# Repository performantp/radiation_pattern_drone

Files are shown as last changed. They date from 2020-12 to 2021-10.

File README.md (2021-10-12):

# Radiation Pattern Drone Project 
README

Die mit MMANA oder 4NEC berechneten Antennen sollen mit einer Drohne auf Abstrahlungscharakteristik und Abstrahlungswinkel ausgemessen und überprüft werden. Die erstellten versionierten Dateien sollen für weitere Projektmitglieder lesbar abgelegt werden.

Release 1.3a (diese Aufgabe wurde im September 2021 unterbrochen, weitere Hinweise und Details sind am Schluss aufgeführt).

Release 1.4a es wurden anschliessend zwei Lösungsvarianten evaluiert. 

Variante 1: Welche anfangs Oktober 2021 nun bereits mit einem ersten Test läuft, ist folgende: Mit einem Raspi auf dem rtl_power läuft und RTL-SDR mit einen Transverter
(47g) wird ein Frequenzbereich von 7-14 MHz überwacht und die gemessenen Werte werden mit einem Python Programm auf einem Raspi Zero W (40g) abgegriffen und dargestellt (Kabel und Antennen ca. 50g). Die ersten Messergebnisse sind so, dass man die gemessenen Werte noch gegenüber dem S-Level kalibrieren muss.

Variante 2: Im Hintergrund ist noch folgende zweite Lösung angedacht und die entsprechende Hardware wurde im September 2021 bereits beschafft.
Mit einem Raspi Zero W (40g) sollen die Messwerte von einem RTL-SDR mit integriertem Transverter aufgesammelt werden und die Daten anschliessend mit rtl_power und/oder Python ausgewertet werden.

Zu der Programmiersprache Python wurde von HB9FRV Ende September 2021 ein USKA HamAcademy durchgeführt. Es gibt voraussichtlich noch weitere Python Kurse. Auch wie man mit Python SDR Implementationen erstellt, wird von Mathias HB9FRV im Rahmen der USKA HamAcademy vermittelt. Daniel HB9GVD wird am 23.10.2021 am Kurs teilnehmen. Die Kurse sind für USKA Mitglieder mit 60.- CHF Kursgeld zugänglich. Auch dieser Kurs wird ev. wiederholt.

Das Team sucht weitere Interessierte, wenn möglich mit Python Kompetenz, welche die Python Aktivitäten unterstützen können. Interessenten melden sich bitte bei Martin HB9GYF oder Daniel HB9GVD.

Release 1.4b (nächste Aufgabe)
Mit einer grösseren Drohne und einer Last von ca. 150g und einem Gesamtgewicht von mehr als 1kg eine zu messenden Antenne (voraussichtlich eine Small Transmitting Loop (STL)) in einem Stufenflug zu erfliegen, damit daraus die Abstrahlcharakteristik der Antenne ermittelt werden kann. Analysieren wieviele Messungen im Flug pro Sekunde durchgeführt werden müssen, damit die Abstrahlcharakteristik ermittelt werden kann. Analysieren, ob sich im PoC dazu der WSPR-Ansatz eignet. Analysieren, wie z.B. grosse Beam-Antennen auf so kleine Aussendungen in 200m rund um die Antenne reagieren/gemessen werden können. Analysieren, ob sich die kleine Stabantenne im PoC eignet oder ob eine Drahtantenne realisiert werden soll. Analysieren, wie sich eine Aussendung z.B. mit 1W im Flug eignet. Die generelle Datensammlung soll im PoC überprüft werden. Die Datenauswertung im PoC soll nach einem Flug innert 12h vorliegen.

Eine Drohne herzustellen inkl. Akku, GPS und allem SDR-Equipmnet unter 250g wäre interessant, um unter den (künftigen) restriktiven gesetzlichen Anforderungen "in die Luft" zu kommen.



Die Drohne Plan B1 kann mehrere Way Points xyz fliegen und so müssten wir in der Lage sein, unser Stufenprofil auf verschiedenen Höhen auszufliegen. Die Drohne Plan B2 wurde bestellt und ist im September 2021 ebenfalls in der Schweiz bei Daniel HB9GVD. 



Release 1.4c (übernächste Aufgabe)
beinhaltet die Realisierung des sogenannten Datensammelpunkts gemäss Datenmodell sowie der Speicherung der Daten für spätere Auswertungen. Die Empfangssignalstärke sowie die GPS-Daten (es könnten die GPS-Daten der Drohne sein) sollen aufgenommen, zeitlich verknüpft und raw gespeichert werden. 

Release 1.5 (weitere Aufgaben) 
beinhaltet die Realisierung von Auswertungen nach Abzug über WLAN oder Bluetooth von der Drohne auf einen PC. Diese können als erstes Proof of Concept für die Auswertung des Abstrahlwinkels und den weiteren Sendekeulen manuell oder automatisch mit einer Python Programmierung erfolgen. 

---------------------------------------------------------------------------------------------------------------------------------------------------------------------------------
Release 1.3a (diese Aufgabe wurde im September 2021 unterbochen)

Aufgabenstellung: Beinhaltet die Realisierung auf einem eigenen Board mit einem ESP32 Prozessor für die Scriptsprache Phyton mit WLAN und Bluetooth Schnittstelle, welches mit KICAD geplant wird (Design per 15.04.2021 abgeschlossen) und dessen PCB-Fertigung in China inklusive Bestückung erfolgt. Dabei können nur Bauteile vom Produzenten auf der Platine eingebaut werden. Die Integration des Silicon Labs SDR Chipset SI4734-D60-GU (SSOP Bauweise) und weitere 1-2 Bauteile werden dann abschliessend manuell in der Schweiz bestückt und danach getestet. Die Box ohne Antenne ist ca. 5x5x3 cm gross und wird mit ca. 30g Last berechnet. Professionelle Drohne aus US mit 780g Fluggewicht und Funktionen wie u.a. Motion Tracking, Way Point Skills ist nach längeren Shiping Aktionen in der CH eingetroffen und sie wurde getestet. Die vorhandenen Flug Management Skills sind hervorragend, aber u.a. aus Lizenzgründen vermutlich "zu gut". Aus der Sicht maximales Gesamtgewicht, welches unter 250g angestrebt wird (somit ist ein Flug bis 250m Höhe ohne Voranmeldung möglich, gesetzliche Randbedingung) wurde für das PoC eine noch leichtere Drohne bestellt. Die PoC Anforderungen an diese leichte Drohne sind mit Last gesamthaft nicht schwerer als 250g, Way Points zu fliegen, Position halten zu können und alles bis ca. 15 km Wind auf +/- 0.5m genau zu fliegen, und dabei die GPS-Daten zu speichern.  

Das SDR PCB ist am 08.05.2021 fertig "designed" und geht bald in die Fertigung nach China. Screenshot von Daniel HB9GVD erhalten. 



Warum wurde unterbrochen? Beim Testen des Boards sind im August/September 2021 Design-Fehler aufgetreten. Einige Verbindungen konnten zwar mit einer ad hoc Verbindung/Korrektur korrigiert werden. Trotz mehreren Anläufen das Board "zum Laufen" zu bringen, und weiteren Arbeiten wurde der "Durchbruch" leider nicht erreicht. Die Arbeiten zu Release 1.3a wurden deshalb vorläuftig eingestellt, alternative Lösungswege wurden analysiert und gefunden. Gerne lädt das Team Interessierte ein, das Board und die entsprechende Programmierung weiterzuführen. Daniel HB9GVD teilt sein Wissen gerne. Die Gewichtsvorteile der eigenen Hardware würden eher eine <250g Drohne erlauben.

--------------------------------------------------------------------------------------------------------------------------------------------------------------------------------
Abgeschlossene oder gestrichene Releases:
Release 1.1 (am 23.12.2020 abgeschlossen)
beinhaltete die Realisierung im November/Dezember 2020 auf einem Breadboard mit dem Silicon Labs Chipset 30, welcher "nur" MW und FM kann. Die Realiserung mit dem Display ST7735SB mit einer SD-Speicherkarte wurde am 01.12.2020 wegen Inkompatibilität zur Original Display Library eingestellt. Weiter verfolgt wurde die Realisierung mit dem Display ST7735S. Die Realisierung wurde in Woche 50/2020 erfolgreich abgeschlossen. Die erreichten Ergebnisse von diesem Release sind in der Dokumentation festgehalten. 

Release 1.2 (auf diesen Schritt wird am 23.12.2020 verzichtet, weil zwei andere OM's diesen Nachweis bereits vollbracht haben, Verweis auf zwei you tube Videos)
beinhaltet die Realisierung auf einem Breadboard mit dem Silicon Labs SDR Chipset SI4734-D60-GU (in der SSOP Bauweise mit oder ohne Breakout Board), welcher MW, FM und SW, inbesondere LSB, USB und CW, kann. Das Display und die Bedienung wird mit einer App realisiert. 

--------------------------------------------------------------------------------------------------------------------------------------------------------------------------------

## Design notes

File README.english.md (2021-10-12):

Antennas calculated either with programs like i.e. MMANA or 4NEC shall be checked and measured with a drone for its real transmission angle and further antenna characteristics. 
Versioned Python sources, compiler scripts for raspi zero W or other documentation presented in Mind Manager files, pdf-files and/or Word files shall be documented for additional project members. 

Variant 1: Equipment rtl_power with transverter in tests and already measured values from 7-14 MHz shall be calibrated against S-Level. First measured realtime date with Python performed, and further analysis of these data still in progress as quick win. 

Variant 2: Equipment raspi zero W to be connected with uSDX (hardware already available on site), and measured data to be selected and displayed with Python to the user under investigation (second opinion). 

First Python training course from Mathias HB9FRV as USKA HamAcademy performed, second Python training already planned. A welcome to an additional team member with Python knowledge is kindly requested. If you would like to join the team, please contact either Daniel HB9GVD or Martin HB9GYF.

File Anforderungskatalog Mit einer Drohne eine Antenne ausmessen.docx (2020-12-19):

# Anforderungskatalog & Proof of Concept "Mit einer Drohne eine Antenne ausmessen" Motto: content over form 19.12.2020

# Anforderungskatalog & Proof of Concept "Mit einer Drohne eine Antenne ausmessen" Motto: content over form 19.12.2020

# 1 Einleitung

Man kann eine Antenne mit MMANA oder 4NEC2, usw. berechnen. Wenn man sie einerseits baut und andererseits aufstellt, weiss man nicht wie die Abstrahlungscharakteristik und der Abstrahlungswinkel wirklich ist. Welchen Einfluss hat u.a. die Umgebung?

Zur Schreibweise und Definition sind es zum Teil Anforderungen (ANF) zum Thema. Welche sich in Business Use Cases (BUC's) und [System] Use Cases (UC's) unterteilen.

## 1.1 Anforderungen (ANF) sind unterteilt in

### 1.1.1 Business Use Cases (BUC's)

Anforderungen vom Benutzer, was er braucht um den Business Use Case "Antennen mit einer Drohne ausmessen" benötigt/braucht

### 1.1.2 [System] Use Cases (UC's)

System Use Cases werden im Weiteren nur als Use Cases (UVC's) beschrieben und das sind Anforderungen an die Technik und/oder Drohne, welche erfüllt sein sollten, damit man schlussendlich einen oder mehrere BUC's durchführen kann.

Wenn Sie das Dokument durchlesen, werden sie leicht merken um was es dabei geht.

## 1.2 Testfälle für BUC's oder UC's werden als Test Cases (TC's) bezeichnet

# 2 Vor dem Start

Die Drohne steht in der Nähe der aufgebauten Antenne und die Antenne ist im Betrieb. Der Empfänger in der Drohne muss vo dem Start, resp. bereits beim Einschalten mindestens mit einem 60 dB Attenuator geschützt werden, ansonsten der Empfänger bei Anschluss einer Antenne gleich zerstört wird. Warum? Auch mit einem solchen Schutz mit 60 dB, so die Erfahrungen/Lernlektion anlässlich eines Fieldday mit dem HB9LU Morseteam, liegt bei ca. 100 W Sendeleistung der Empfangspegel von S9+40 an, wenn die sendende Antenne ca. 50m entfernt ist.

# 3 UC: Attenuator Umschaltung in der Luft

Der Attenuator muss in der Luft umgeschaltet werden können, d.h. je weiter weg die Drohne fliegt soll ein kleinerer Attenuator eingesetzt werden. Dies soll automatisch erfolgen. Wenn die Drohne weit genug weg ist, soll der Attenuator ausgeschaltet werden. Wenn die Drohne sich wieder der Antenne nähert, soll der Attenuator wieder eingeschaltet werden,

Wenn sich die Drohne einer anderen sendenden Antenne nähert, soll das gleiche Procedur erfolgen, um den Empfänger zu schützen.

# 4 BUC: 'normales' Diagram einer Monoband Antenne erfliegen

Monoband Dipole oder Monoband Verticals haben eher bekannte Abstrahlungscharakteren.

# 5 BUC: Diagramm einer Yagi Antenne erfliegen und F/B Verhältnis ausweisen

# 6 BUC: Sendekeulen inklusive Abstrahlwinkel erfliegen, z.B. mit einem Wellenflug oder Rundflug (Kreis) auf verschiedenen Höhen in verschiedenen Radien

## 6.1 24.11.2020

### 6.1.1 für das Proof of Concept könnte man ganz einfach in der erwarteten Hauptstrahlrichtung in Distanz 20m und 5m Höhe auf 150m hoch, dann 20m weiter weg in 40m/150 auf 5m runter, dann weiter weg auf 60m in 5m Höhe usw. fliegen

# 7 Eine Antenne ist an einen WSPR Sender (WSPRlite Flexi) angeschlossen und sendet auf einer eingestellten Frequenz

## 7.1 1 Watt

### 7.1.1 war es bei Martin früher einmal mit einer WSPR Aussendung auf dem ICOM 7300. Die TRX-Aussendung musste manuell gestartet werden. Habe die Ansteuerung nicht/nie realisiert. Aber für einzelne Aussendungen und kurze Tests über z.B. 10 Minuten (5 Aussendungen) war das ok

## 7.2 kleine Leistung ... sind m.E. die milliWatt Dinger ab der Stange

### 7.2.1 WSPRlite Flexi mit 200 mW

Siehe auch: WSPRlite Flexi mit 200 mW an einer kurzen Antenne mit der obigen Konfiguration, prüfen, oder

#### 7.2.1.1 bei Wimo für 80 Euro aber Ende Oktober 2020 ausverkauft

#### 7.2.1.2 der ältere Typ ist der WSPRlite Classic

##### 7.2.1.2.1 der ältere Typ WSPRlite Classic hat ein Filter für 20m und 30m eingebaut

##### 7.2.1.2.2 Der neuere Typ benötigt für jedes Band ein eigenes Filter um sich zu schützen

###### für die ersten Tests habe ich bis und mit 16.11.2020 keine weiteren Filter gebaut oder eingesetzt

#### 7.2.1.3 Lutz Electronic hat beide auch im Angebot, zu kaufen gemäss Web-Seite

##### 7.2.1.3.1 am 02.11.2020 WSPRlite Flexi mit Kleinmaterial bestellt

##### 7.2.1.3.2 Lieferung von Lutz Electronic am 04.11.20220 eingetroffen

#### 7.2.1.4 200 mW ist die maximale Leistung. Man kann sie laut Beschreibung auch auf 5 mW reduzieren

#### 7.2.1.5 WSPR Message Type 1

##### 7.2.1.5.1 wir werden den WSPR Message Type 1 verwenden und "nur" HB9GYF aussenden, d.h. ohne einen Prefix oder Suffix zu verwenden

Siehe auch: Callsign HB9GYF eingestellt

##### 7.2.1.5.2 wir werden "nur" den vierstelligen Locator JN47 aussenden

Siehe auch: Locator JN47

#### 7.2.1.6 WSPR Message Type 2/3

##### 7.2.1.6.1 WSPR Messages Type 2/3 benötigen zwei Aussendungen und sie werden gegenüber WSPR Message Type 1 nur zu ca. 25% von 'hörenden' Stationen erkannt und in die WSPR-Datenbank geschrieben

#### 7.2.1.7 Beschreibungen, FAQ, Config, usw sind auf der Web-Seite www.DXplorer.net nachzulesen, resp. das EInstellpogramm WSPRliteConfig runterzuladen

Siehe auch: Einstellungen des WSPRlite Flexi mit dem Programm WSPRliteConfig

#### 7.2.1.8 05.11.2020

##### 7.2.1.8.1 Einstellungen des WSPRlite Flexi mit dem Programm WSPRliteConfig

###### man kann 5, 10, 20, 50, 100 oder 200 mW einstellen

###### Callsign HB9GYF eingestellt

###### Locator JN47

###### 20m Band

###### Es wird eine Frequenz ausgewählt

###### Aussendung 50%

###### Aussendungsdauer 3 days

###### so ist jede Aussendung natürlich gesetzeskonform

##### 7.2.1.8.2 vor dem Start

###### nicht vergessen die 20m Antenne anzuschliessen

###### habe meine ca. 80 cm lange EH-Dipol Antenne, realisiert mit zwei Haarspraydosen mit einem SWR 3.0, vertikal an einer Stipprute aufgesteckt angeschlossen

###### Filter-Thematik: Habe es ohne Filter probiert

Siehe auch: Filter Thematik

###### haben andere OM's auch schon gemacht, aber ...

###### zusammen mit Dani und seinem Analyser noch die Oberwellen ausmessen

##### 7.2.1.8.3 Start

###### man muss manuell starten, in dem man auf die Taste am WSPRlite Flexi drückt und zwar an geraden Minuten und die Sekunde 02

###### dazu auf dem PC mit dem Browser auf eine Web-Seite "Atomuhr von der Schweiz" öffnen

###### und zur richtigen Zeit noch die Taste drücken

###### wenn man zur falschen Zeit drückt, wird sofort ausgesendet

Siehe auch: man kann in diesem Fall zur richtigen Zeit, d.h. zur Sekunde 02 in einer geraden Minute, erneut die Taste drücken

###### man kann in diesem Fall zur richtigen Zeit, d.h. zur Sekunde 02 in einer geraden Minute, erneut die Taste drücken

##### 7.2.1.8.4 Aussendungskontrolle

###### mit dem ICOM 705 einem Dummyload mit einem parallelen kurzen Draht auf dem Band messen

###### in 2m Abstand kommt das ausgesendete 5 mW Signal mit S9+15 an

##### 7.2.1.8.5 Auswertung

###### im WSPRliteConfig unten einen Link anklicken führt den Benutzer direkt auf die WSPR Datenbank

###### am 05.11.2020 mit 5 mW Aussendung über die Inhouse Antenne nichts über eine Aussendung von HB9GYF gefunden

#### 7.2.1.9 Filter Thematik

##### 7.2.1.9.1 WSPRlite Flexi hat keine Filter

###### WSPRlite Classic hat zwei eingebaute Filter für das 20m und 30m Band

##### 7.2.1.9.2 bei Lutz Elecronic kann man Filter pro Band kaufen. Man muss diese dann aber selber zu sammen bauen, wickeln und löten

###### die Platine für drei Filter hat aber noch zwei Schalter drauf und man muss die Filter umschalten

##### 7.2.1.9.3 man muss aufpassen, dass man Filter kauft, welche nicht nur zum Empfangen, sondern auch zum Senden verwendet werden können

###### Es kommt auch noch drauf an, für welche Power sie sind

###### Filter für 1 KW oder 100 W sind natürlich zu stark und kosten auch sehr viel (schwer mit PL-Stecker sind sie auch noch)

###### Filter für 10 W kann man für rund 25.- USD auch mit SMA Stecker pro Band kaufen

##### 7.2.1.9.4 ein Überlastschutz ist das natürlich nicht

###### hiezu könnte man die Schaltung mit der Glühlampe, welche ich zusammen mit Mathias baute, verwenden

###### einen Überlastschutz würden wir benötigen, wenn starke Stationen in der Nähe des WSPR's aussenden, weil diese den WSPR Empfänger "verbrennen" könnten

##### 7.2.1.9.5 Als Umgehung der Filter-Thematik kann man eine schmalbandige Magnetic Loop als Sende-Antenne einsetzen

###### Martin hat noch die Magnetic Loop von HB9LU, welche auch 20m kann

###### bis jetzt nur 80m ausprobiert

###### ev. bei Gelegenheit mal ausprobieren

## 7.3 so war m.E. der letzte Versuch bei HB9LU (Martin war leider im 2019 nicht dabei)

### 7.3.1 Bericht auf der Web-Seite von HB9LU resp. HB9BXE nachlesen

#### 7.3.1.1 Bericht von Hans-Peter erhalten gelesen und auch an Dani verschickt

#### 7.3.1.2 interessant: die gemessenen Daten (die Empfangspegel) werden per Morsesignal auf UHF übermittelt (1 Mann Betrieb)

### 7.3.2 Nein, es war bei HB9LU nicht WSPR, sondern ein Feldstärke Messgerät, Marke Eigenbau

#### 7.3.2.1 im Film von Marcin HB9EGA war nicht erkennbar wie gross die Distanz beim Ausmessen der Antenne war

# 8 BUC: NVIS Anteil einer Antenne erfliegen

## 8.1 gemäss Dani am 31.10.2020 darf die Drohne, entfernt von einem Flughafen, auf max. 150m Grund fliegen

# 9 Zugeklappte Punkte

## 9.1 Antenne sendet FT8 Signale aus

### 9.1.1 Entscheid 30.10.2020: das Proof of Concept führen wir mit WSPR durch

# 10 BUC: Hohe Schule mit ad hoc Messungen an/bei in Betrieb stehenden Antennen idR mit hoher Leistung

## 10.1 UC: Antenne sendet während dem Drohnenflug mit SSB oder CW z.B. in einem Contest auf einer (1) festen Frequenz

## 10.2 UC: Antenne sendet während dem Drohnenflug mit SSB oder CW z.B. in einem Contest auf mehreren nicht angekündigten Frequenzen

## 10.3 wenn 200 mW des WSPRlite Flexi ein S9+30 ergeben, sind 1W gleich S9+36, 4W gleich S9+42, 16W gleich S9+48, 64W gleich S9+52, 256W gleich S9+58 und 1000W gleich S9+64 (wenn wir HB-Stationen ausmessen)

### 10.3.1 ein Bandpass Filter ist hier definitiv nicht die Lösung oder nur dann, wenn andere Stationen in der Nähe als die zu messende, ebenfalls mit starker Leistung senden, aber auf einem anderen Band

### 10.3.2 wenn wir den SDR Empfänger Chip mit dem Bausatz mit der Glühbirne schützen, dann verbrennen wir mit einem starken Signal zwar den SDR Chip nicht, wir wissen aber nicht wie stark das Empfangssignal wirklich ist

Siehe auch: UC: wir müssen den SDR Empfänger Chip mit einem Attenuator von 60 dB schützen. Der Attenuator muss schaltbar sein und er muss irgendwie manuell einstellbar (z.B.vor dem Start) und/aber bei Überlast automatisch sein

### 10.3.3 UC: wir müssen den SDR Empfänger Chip mit einem Attenuator von 60 dB schützen. Der Attenuator muss schaltbar sein und er muss irgendwie manuell einstellbar (z.B.vor dem Start) und/aber bei Überlast automatisch sein

Siehe auch: UC: Attenuator Umschaltung in der Luft

# 11 BUC: 3D-Diagramm Darstellung von Keulen und Abstrahlwinkel und deren Winkel in Grad gegenüber N mit z.B. einer Stick-Steuerung nach Drohnenflug innert 60 Minuten erstellen

## 11.1 UC: in der Drohne hat es zur Datenspeicherung z.B. eine microSD Karte zur Datenspeicherung, oder sonst einen Speicher, welcher nach dem Flug manuell oder über WLAN Transfer abgerufen und ausgewertet werden kann

## 11.2 als Quick Win sicher keinen Datentransfer planen & realisieren

# 12 Lösungsideen

## 12.1 Dani hat einen SDR Chip für ca. 3 USD evaluiert, den wir prüfen müssen

### 12.1.1 https://de.aliexpress.com/item/32288294783.html

### 12.1.2 und noch Details sowie Schema

#### 12.1.2.1 https://www.hackster.io/CesarSound/am-fm-sw-radio-receiver-si4730-si4735-79438f

### 12.1.3 wie kann der SDR Empfänger ein WSPR Signal von 5.9 Hz Bandbreite erkennen? Oder messen wir mit einem Filter von 500 Hz einfach das stärkste Signal innerhalb des 200 Hz breiten WSPR-Bands?

### 12.1.4 SDR Chip

https://de.aliexpress.com/item/32288294783.html

## 12.2 Hack RF one

### 12.2.1 hat eine wirklich kleine Sendeleistung von ca. 5 dBm

### 12.2.2 wird im Novmber 2020 is auf Weiteres nicht verfolgt

# 13 Fragen

## 13.1 offene Fragen

### 13.1.1 Gewicht-Management

#### 13.1.1.1 Wieviel Gewicht mag die Drohne aus den USA etwa (+/- 50g) transportieren?

Siehe auch: Dani meint, dass der SDRPlay RSP1 mit ca. 120 g schwer oder zu schwer ist und dass es "leichtere Dinger" gibt

## 13.2 gelöste oder geschlossene Fragen

### 13.2.1 Es sind alle Informationen von früheren Fragen noch da, aber sie werden im Mindmap zugeklappt. Sie sind aber im Word Dokument jederzeit nachlesbar und/oder können im Mindmap jederzeit hier links aufgeklappt werden

#### 13.2.1.1 Können wir als Empfänger den SDRPlay RSP1 dazu unter Linux o.ä. einsetzen?

##### 13.2.1.1.1 Dani meint, dass der SDRPlay RSP1 mit ca. 120 g schwer oder zu schwer ist und dass es "leichtere Dinger" gibt

Siehe auch: Dani hat einen SDR Chip für ca. 3 USD evaluiert, den wir prüfen müssen

#### 13.2.1.2 Können wir als Empfänger einen SDR Kiwi dazu einsetzen?

##### 13.2.1.2.1 ist noch schwerer

# 14 Quick Wins

Siehe auch: Eine Antenne ist an einen WSPR Sender (WSPRlite Flexi) angeschlossen und sendet auf einer eingestellten Frequenz

## 14.1 zuerst die Quick Wins erreichen, austesten & überprüfen

# 15 Proof of Concept

## 15.1 Test Case 0

### 15.1.1 Wie kann man die Daten vom SDR-Empfänger aufsammeln? Zwischenspeichern? (siehe geänderter Lösungsansatz vom 18.12.2020)

#### 15.1.1.1 SDR Empfänger bauen und ausmessen (siehe Messresultate vom 18.12.2020)

##### 15.1.1.1.1 Eingangsprüfung durchführen. Am 21.11.2020 bis 10.12.2020 funktioniert es auf dem Steckbrett von Dani mit dem SDR Chip Typ SI4730 ohne den Zusatz D60, d.h. der SW-Teil SI4730-D60 noch nicht

###### SDR Chip am 18.11.2020 eingetroffen

###### SDR Chip bestellen

###### der erste SDR Chip bei Dani kann "nur" FM und MW

Siehe auch: der Testaufbau ist noch dunkel, es rührt sich noch nichts. Das Display zeigt bei Dani nichts an

###### 20.11.2020

###### Erwägungen: Man könnte das Schema zeichnen und dann alles in China fertigen und bestücken lassen

###### es geht laut Dani "nur" mit elektrischen Teilen, welche der Print-Hersteller in China selber zur Verfügung hat. Weitere Teile muss man dann anschliessend selber einbauen & einlöten

###### 22.11.2020

###### der Testaufbau ist noch dunkel, es rührt sich noch nichts. Das Display zeigt bei Dani nichts an

###### man muss die Library von der LCD-Library noch richtig zur Arduino Library einspielen. Diesen Punkt überprüfen durch Dani

Um mit dem I2C LCD Modul zu arbeiten benötigt man eine Library, welche noch nicht im Arduino Programm vorinstalliert ist. Diese kann man zum Beispiel unter https://github.com/fdebrabander/Arduino-LiquidCrystal-I2C-library als .ZIP Datei herunterladen. Danach muss die Library im Arduino Programm hinzugefügt werden. Das kann unter dem Punkt „Sketch“ dann „Include Library“ und „add .ZIP Library ..“ gemacht werden. Jetzt kann im Code auf die Library zurückgegriffen werden.

###### wird am 17.12.2020 geschlossen

###### 23.11.2020

###### es gibt noch eine gute Beschreibung zu Arduino

###### HYPERLINK "http://funduino.de/wp-content/uploads/2016/11/Anleitungen-deutsch-12-2016.pdf" Anleitungen für Arduino - Anleitungen und Kits für Arduino (funduino.de)

###### 10.12.2020

Dani meldet: Bei Mathias funktioniert das Display und der Arduino. Es muss fast ein (1) Display und ein (1) Arduino von je zwei (2) defekt sein. Er wird wenn das Material von Mathias zurück ist, dies bei sich erneut verifizieren. Er meint, dass es nichts mit Windows Arbeitssystem oder Linux Arbeitssystem zu tun hat. Bei ihm funktioniert, der Arduino nur mit dem Display verbunden, d.h. mit dem je zweiten Display und Arduino nicht. So ein Punkt ist natürlich tödlich und kostet enorm viel Zeit --> wir haben so ca. 17 Arbeitstage verloren/verbrannt

###### 15.12.2020

###### Nun funktioniert es bei Daniel auf dem Breadboard

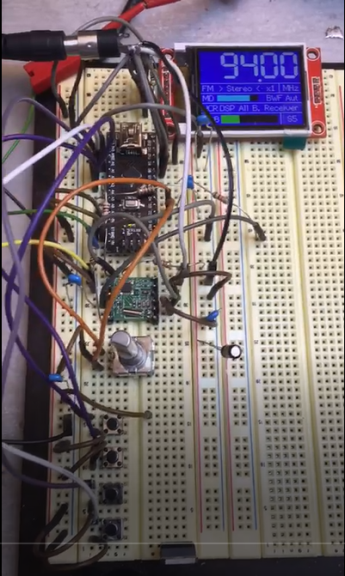
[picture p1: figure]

###### 17.12.2020

###### Dani berichtet, dass es bei ihm der Arduino ist/war, welcher defekt ist/war. Es könnte auch ein Pin gewesen sein

###### Auch ein AM-Signal auf 630 kHz im Mittelwellenberich mit 1 kHz Bandbreite kommt nun rein

###### Test Resultate 8.12.2020

###### Zusammenfassung

###### Welche Tests hat Martin durchgeführt

###### Weitere Tests

###### Weiteres Vorgehen

###### hier liest Du das Mail dazu

Hier meine Kurzzusammenfassung meiner Tests. Daniel brachte mir am Donnerstagabend 17.12.2020 das Breadboard mit dem laufenden Arduino und Display für weitere Tests vorbei, welches er am Nachmittag bei Mathias gezeigt hat.

Zusammenfassung

Das Breadboard läuft mit dem 30-er Chip auf FM und MW hervorragend. SW und insbesondere SSB (F3E) oder CW (A1A) kann es nicht. LW kann es auch nicht.

Welche Tests hat Martin durchgeführt?

Parallel zum Testaufbau hat Martin ein Tecsun S-8800e (allein stehend) sowie den Xiegu G90 mit einer 53m langen Drahtantenne hinter einem CG-3000 zur Verfügung.

Der Empfang mit der FM-Modulationsart funktioniert problemlos mit der ca. 10 cm langen FM-Antenne. Wenn der 10 cm lange Draht auf dem Tisch liegt kommt der FM-Sender auf 99.90 MHz mit S5 durch. Ist der 10 cm lange Draht senkrecht in die Luft gerichtet, kommt der gleiche FM-Sender auf 99.90 MHz mit S7 an.

Wenn man durchklickt, hat es die Bereiche LW, MW1, MW2 und man erkennt dann auch die SW-Bänder, ganz am Schluss ist dann der FM-Bereich eingeschaltet. Dann fängt es wieder von vorne mit dem LW an. In diesen SW-Bändern kann man die Frequenz in 1 oder 5 oder 10 kHz Schritten etwas rauf oder runterdrehen und man fällt dann automatisch in unsere Amateurfunk KW-Bänder rein. Man erkennt dies direkt an der Anzeige. Der zweite Draht am Breadboard ist die AM-Antenne, welche Martin mit einem 1m langen Draht verlängert hat.

LW auf 234 kHz wird zwar ein S3 angezeigt, aber der französische Sender kommt auf dem Breadboard nicht durch, auf dem Tecsun S-8800e hingegen schon.

MW2 auf 1190 kHz kommt mit der Bandbreite 6 kHz ein eventuell slavischer Sender mit S5 an. Der Sender, resp. die Sprache und Musik kann klar empfangen werden. Wenn man das Verstärkerboard, an das der Lautsprecher angeschlossen ist, etwas vom Breadboard entfernt (ca. 20 cm) dann nimmt das Knacken ab. Das Knacken erfolgt im Rhythmus wie das Lämpchen am Arduino blinkt (bei der Realisierung der kleinen Platine an die Abschirmung denken, die Realisierung beim Colibrinano könnte m.E. diesbezüglich ein gutes Vorbild sein). Man merkt, dass die Propagation sich verändert. Um 1908 LT steigt die Signalstärke auf S7 und um 1912 LT ist die Signalstärke wieder bei S5 angelangt. Um 1920 LT ist die Signalstärke noch S3, aber die Sprache des Senders ist immer noch klar und verständlich.

Es fällt auf, dass man die Bandbreite von 1, 1.8, 2, 2.5, 3, 4 und 6 kHz einstellen kann, dies aber keinen Einfluss auf den Empfang hat.

Um 2300 LT auf MW2 und 740 kHz kommt ein spanischer Sender mit S5 an.

Um 2305 LT auf MW2 und 660 kHz liegt ein eventuell italienischer Sender mit S7 an.

Um 2312 LT hat es auf 640 kHz einen Sender, welcher zwischen S5 und S7 schwankt.

Die gleichen Empfangsfrequenzen auf dem MW1 Bereich zeigen schwächere Empfangssignale bei den gleichen obigen Sendern an. MW1 auf 740 kHz ein S3 und 660 kHz ebenfalls ein S3. Warum das so ist, ist Martin nicht klar. Habe daraufhin immer mit MW2 gearbeitet.

Beobachtung 1

Plötzlich war zwei Mal die Ausgabe auf dem Lautsprecher weg. Den Strom auf dem Verstärkerboard off/on brachte keinen Erfolg. Den Strom am Breadboard off/on ebenfalls nicht. Irgendwie war es so, dass man nach dem Wiedereinschalten am Schalter für die Bereichsumschaltung durchklicken musste und erst wenn der FM-Bereich aktiv war/ist, wird der Lautsprecher wieder aktiv.

Weiteres

Auf MW2 konnte ich die Frequenz auf 1838 kHz in das 160m Band stellen. Dabei schaltete die Anzeige auf dem Display auf AM 160 um. Wenn ich mit dem Xiegu G90 auf 1837 kHz mit CW sendete, bewegte sich die dB-Anzeige, d.h. der Balken nach rechts und es wurde S5 angezeigt. Im Lautsprecher hörte ich nichts. Die Beobachtung der Anzeige war aber nicht bei jedem Senden mit dem Xiegu G90 eindeutig. Manchmal reagierte die Anzeige nicht mehr. Nach off/on und einmal rundherum Schalten über FM und dann über LW in die SW-Bänder ging es dann wieder ein oder zwei Mal.

Erwägung 1

Der 30-er Chip kann m.E. nicht SSB und auch nicht CW. Er kann „nur“ AM und FM. Mit CW (A1A) haben wir ja nur einen Träger. Martin hat zwei neuere Videos auf dem Internet gefunden, zu dem zwei OM’s unabhängig voneinander mit dem SI4735-D60-GU Chip und selber erstellen Boards ein SSB-Signale (LSB und USB) sowie ein CW Signal hörbar zeigten.

Weiterer Test

Am Freitag 18.12.2020 führte ich eine AM-Aussendung mit dem Xiegu G90 im 160m Band auf 1860 kHz durch. Dies brachte zwar die S-Level Anzeige zur leichten Bewegung, aber aus dem Lautsprecher kam nichts heraus. Martin meint, dass der 30-er Chip diese 1860 kHz Frequenz nicht beherrscht. Auf 21400 kHz war dasselbe Verhalten bei einer AM-Aussendung vom Xiegu G90 feststellbar. Auf dem Tecsun S-8800e hörte ich zwar das Geräusch/Ton von meinem Reinblasen am Xiegu G90 Mikrofon, den Pfeifton hingegen aber nicht (komisch). Aber eine AM-Aussendung auf dem Xiegu G90 hat Martin noch nie gemacht. Auf dem Display vom Xiegu G90 sah es aber nach einer AM-Aussendung mit zwei Seitenbändern aus.

Erwägung 2

Der 30-er Chip ist gemäss Datenblatt nicht für SW freigegeben. Tests mit dem SI4735-D60-GU Chip planen und wiederholen.

Erwägung 3

Im Moment sind meine Gedanken „ausgeschossen“. Ich hoffe, dass wir mit dem SI4725-D60-GU Chip weiter kommen (sie sind im Moment am/beim Zoll). Vielleicht kann man mit fast Null-Aufwand einfach den neuen Chip auf das Breadboard stecken und einen weiteren Test durchführen. Dies könnte dann ein Eingangscheck sein. Vermutlich ist die Arduino Software natürlich für den neuen Chip „bereit“, aber ohne den neuen Chip geht es halt nicht.

Weiteres Vorgehen

Daniel erläuterte mir, dass die weiteren Tests mit einem ESP32 Prozessor geplant werden. Dieser ESP32 Prozessor ist wesentlich leistungsstärker. Über einen Bootloader kann man WLAN und Bluetooth Anschlüsse aktivieren und eine Anzeige könnte einfach über ein App erfolgen. Es braucht gar kein Display. Eine GPS Anbindung und/oder eine Sammlung von GPS-Daten wäre über eine weitere Schnittstelle relativ einfach denkbar. Eventuell auch eine SD-Karte für eine Speicherung wäre so einfach möglich. Die Print-Planung und die Print-Herstellung (Abschirmung) sind die nächsten Schritte, welche Daniel in Angriff nimmt.

##### 15.1.1.1.2 SDR Chip SI4734-D60-GU bei Dani eingetroffen

###### Es gibt neu den Chip SI4734-D60-GU, der SW kann und von dem Dani fünf (5) Stück am 21.11.2020 bestellt hat

Siehe auch: https://www.aliexpress.com/item/4000063117010.html

###### leider gibt es das Breakout Board nicht mehr in Ali-Express

Siehe auch: https://www.aliexpress.com/item/4000063117010.html

###### https://www.aliexpress.com/item/4000063117010.html

###### am Schluss die Bezeichnung GU von SI4734-D60-GU bedeutet, dass das Bauteil die Grösse 24-SSOP hat, d.h. 24 Pin ca. 20x40 mm

###### 17.12.2020

###### Dani meldet, dass die D60-er Chips nun am CH-Zoll sind

###### einer der nächsten Schritte ist das Board, welches nun aufgeplant werden soll/wird. Dani trifft sich heute noch mit Mathias (ist am 17.12.2020 erfolgt, siehe dazu wie sich die Lösungsidee verändert hat)

###### 19.12.2020

###### Das geplante Vorgehen ändert sich mit einer Realisierung mit einem ESP2 Prozessor

Daniel erläuterte mir, dass die weiteren Tests mit einem ESP32 Prozessor geplant werden. Dieser ESP32 Prozessor ist wesentlich leistungsstärker. Über einen Bootloader kann man WLAN und Bluetooth Anschlüsse aktivieren und eine Anzeige könnte einfach über eine App erfolgen. Es braucht gar kein Display. Eine GPS Anbindung und/oder eine Sammlung von GPS-Daten wäre über eine weitere Schnittstelle relativ einfach denkbar. Eventuell auch eine SD-Karte für eine Speicherung wäre so einfach möglich. Die Print-Planung und die Print-Herstellung (Abschirmung) sind die nächsten Schritte, welche Daniel in Angriff nimmt.

Vielleicht kann man, als Idee von Martin, mit fast Null-Aufwand einfach den neuen Chip SI4734-D60-GU auf das Breadboard stecken und weitere KW- und CW-Tests durchführen. Dies könnte dann ein Eingangscheck sein. Vermutlich ist die Arduino Software natürlich für den neuen Chip „bereit“, aber ohne den neuen Chip geht es halt nicht

###### man könnte so auch den WSPRlite Flexi auf einer leicht anderen Frequenz austesten

##### 15.1.1.1.3 Kurzbeschreibung SI4730-D60 hier nachlesen

Ein hochintegriertes SDR-Receiver-IC, ein Arduino und ein Farbdisplay ergeben zusammen einen respektablen Empfänger, der von Langwelle bis UKW reicht. Hackster-User CesarSound hat mit dem Silicon-Labs-Chip si4730 einen komfortablen Weltempfänger gebaut, der Frequenz, Wellenbereich und Empfangsfeldstärke übersichtlich auf einem 1,8"-Farbdisplay darstellt und über einen Dreh-Encoder bedient wird. Die Ansteuerung des über den I2C-Bus befehligten Chips übernimmt ein simpler HYPERLINK "https://www.heise.de/thema/Arduino" Arduino Nano. Der si4730 war der erste voll integrierte AM/FM-Empfänger auf dem Markt, der vollständig ohne externe Spulen, Verstärker- und Abstimmstufen auskam; die interne Signalverarbeitung (Filterung, Verstärkung, Demodulation, bei FM auch Stereo-Dekodierung) erfolgt rein digital. Das für Handheld-Geräte gedachte winzige IC gibt es inzwischen mit allen benötigten Bauteilen montiert auf einem Breakout-Board, Händler verlangen rund 2 Euro dafür. Bei der Beschaffung sollte man darauf achten, die IC-Revision D60 zu erwischen, nur sie unterstützt auch die Kurzwellen-Bänder. Das auf HYPERLINK veröffentlichte Projekt bietet eine Frequenzanzeige im Siebensegment-Stil, zwei Balkenindikatoren zur Anzeige der Signalstärke, die Auswahl von sieben Bandbreiten-Filtern für AM, Anzeige der Wellenlänge des Bandes, eine Stereo/Mono-Anzeige und zwei "Skins" (Farbschema). Es deckt 14 Bänder ab: LW, MW, KW, CB (100kHz bis 30MHz) sowie das erweiterte FM-Band von 64 bis 108MHz. Das Display ist ein preiswertes 1,8"-TFT, so dass die gesamten Bauteilkosten weniger als 20 Euro betragen (ein billiger Arduino-Nachbau vorausgesetzt). Die Lang- und Kurzwellenversionen des Chips sind Si4734 und Si4735. Die Si4731 und 4735 haben zusätzlich noch RDS-Support. Laut einigen Beiträgen im Internet funktioniert der Si4730 jedoch auch auf Kurzwelle.

###### Hier sind einige Videos zu sehen

###### HYPERLINK "https://www.heise.de/news/Mit-2-Euro-SDR-Chip-Arduino-wird-zum-Weltempfaenger-4941272.html" Mit 2-Euro-SDR-Chip: Arduino wird zum Weltempfänger | heise online

###### Auszug aus zwei PDF's

###### 4.2. Operating Modes

The Si473x-D60 operates in either an FM receive or AM receive modes. In FM mode, radio signals are received on FMI and processed by the FM front-end circuitry. In AM mode, radio signals are received on AMI and processed by the AM front-end circuitry. In addition to the receiver mode, there is a clocking mode to choose to clock the Si473x-D60 from a reference clock or crystal. On the Si473x-D60, there is an audio output mode to choose between an analog and/or digital audio output. In the analog audio output mode, ROUT and LOUT are used for the audio output pins. In the digital audio mode, DOUT, DFS, and DCLK pins are used. Concurrent analog/digital audio output mode is also available requiring all five pins.

###### 4.4. AM Receiver

4.4. AM Receiver

The highly-integrated Si473x-D60 supports worldwide AM band reception from 520 to 1710 kHz using a digital low-IF architecture with a minimum number of external components and no manual alignment required. This digital low-IF architecture allows for high-precision filtering offering excellent selectivity and SNR with minimum variation across the AM band. The DSP also provides adjustable channel step sizes in 1 kHz increments, AM demodulation, soft mute, seven different channel bandwidth filters, and additional features, such as a programmable automatic volume control (AVC) maximum gain allowing users to adjust the level of background noise. Similar to the FM receiver, the integrated LNA and AGC optimize sensitivity and rejection of strong interferers allowing better reception of weak stations. The Si473x-D60 provides highly-accurate digital AM tuning without factory adjustments. To offer maximum flexibility, the receiver supports a wide range of ferrite loop sticks from 180–450 µH. An air loop antenna is supported by using a transformer to increase the effective inductance from the air loop. Using a 1:5 turn ratio inductor, the inductance is increased by 25 times and easily supports all typical AM air loop antennas which generally vary between 10 and 20 µH.

###### 4.5. SW Receiver

The Si4734/35 is the first fully integrated IC to support AM and FM, as well as short wave (SW) band reception from 2.3 to 26.1 MHz fully covering the 120 meter to 11 meter bands. The Si4734/35 offers extensive shortwave features such as continuous digital tuning with minimal discrete components and no factory adjustments. Other SW features include adjustable channel step sizes in 1 kHz increments, adjustable channel bandwidth settings, advanced seek algorithm, and soft mute. The Si4734/35 uses the FM antenna to capture short wave signals. These signals are then fed directly into the AMI pin in a wide band configuration. See "AN332: Si47xx Programming Guide” and “AN383: Si47xx Antenna and Schematic Guidelines" for more details.

Radio operation:

The radio is operated using a rotary encoder and 4 buttons, as described below:

Rotary encoder: used to tune to radio stations.

Button 1: for changing bands (14 AM and 1 FM bands).

Button 2: for changing tuning steps AM (1kHz, 5kHz, 10kHz).

Button 2: for changing tuning steps FM (100kHz, 200kHz). NEW

Button 3: to select the AM bandwidth filters (6, 4, 3, 2.5, 2, 1.8, 1kHz).

Button 3: to select the FM bandwidth filters (Aut, 110, 84, 60, 40kHz). NEW

Button 4: to select the color scheme of the display (2 schemes).

###### Button 3: to select the AM bandwidth filters (6, 4, 3, 2.5, 2, 1.8, 1kHz)

###### SW band support (Si4734/35 and Si4730-D60) (2.3–30 MHz)

###### Receiver Characteristics

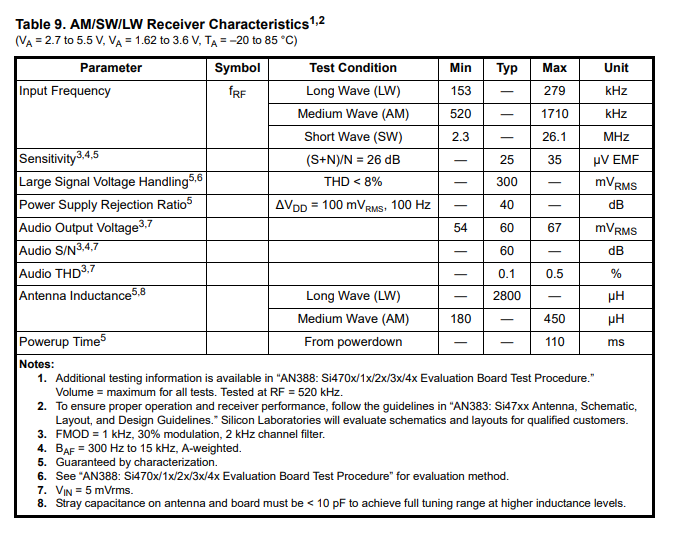
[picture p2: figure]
graphic
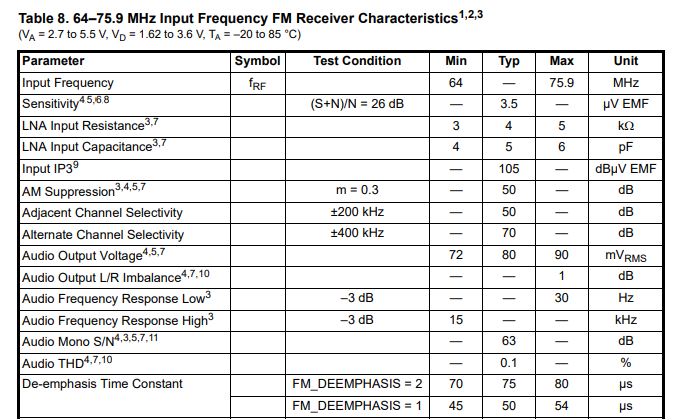
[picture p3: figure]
graphic

###### Lessions learned

###### in solchen Fällen halte Dich zuerst an die Datenblätter vom Produzenten. Die sind unterteilt in Werte in uV/m <30 MHz und in >30 MHz (siehe Receiver Characteristics)

###### Gemäss Silican Labs ist die Sensivity 25 uV/m, das wäre S8

###### es könnten auch 3.5 uV/m sein, das wäre S5

###### Dieser Wert ist beim Hersteller in der FM Tabelle aufgeführt. Somit ist bei FM S9 = 5uV/m über 50 Ohm und der Wert 3.5 uV/m ist somit ein S8

###### in einer Beschreibung auf einer China Web-Seite des Vorgängers zur D60 Ausführung sind 34 dbuV/m angegeben, das wäre ein S9 Signal

###### <30 MHz, S9 = -73 dBm = 50 uV/m über 50 Ohm >30 MHz, S9 = -33 dBM = 5 uV/m über 50 Ohm

###### Table 25. AM Receiver Window Descriptions

###### Function, Band Selection

The Function buttons are used to boot up the device in different mode. Using the Band Selection drop down box, you can select different AM, LW, or SW bands. The drop down box will only appear with LW or SW enabled device. If an SW band is selected using the SW/WB Antenna Card, set the varactor to 1 for best performance. LW not support with SW/WB Antenna Card.

###### Status

The RSSI indicator displays the RSSI of the signal in dBuV. The SNR indicator displays the SNR of the received signal in dB. The varactor value specifies the capacitance of the tuning front-end. A value of 6143 means that the maximum capacitance is being presented at the AM input and a value of 1 means that the varactor is at its minimum value. The AGC Index indicator displays the AGC status. The Soft Mute indicator displays the estimated attenuation applied to the signal based on RSSI and SNR values.

###### 6. Ordering Guide

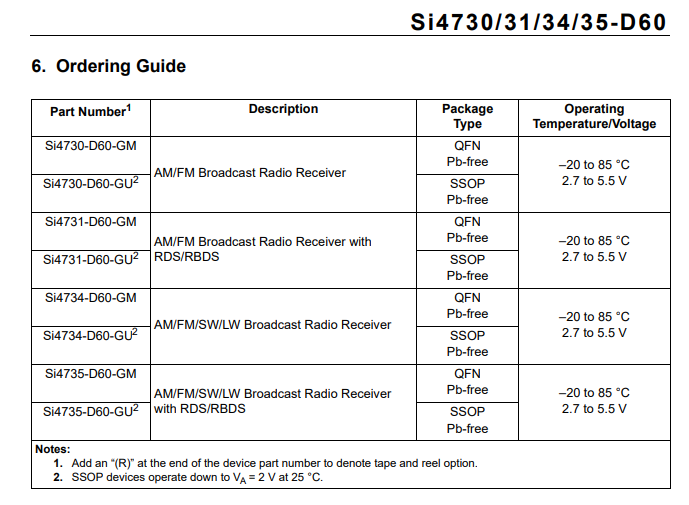
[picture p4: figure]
graphic

###### Functional Description

###### Functional Block Diagram

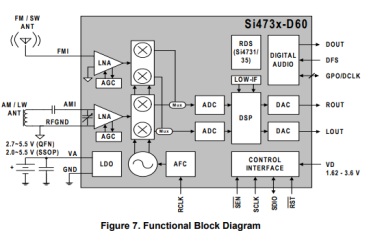
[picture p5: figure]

###### Auszug aus der hackster Beschreibung

###### Radio operation

Siehe auch: SW band support (Si4734/35 and Si4730-D60) (2.3–30 MHz), Button 3: to select the AM bandwidth filters (6, 4, 3, 2.5, 2, 1.8, 1kHz)

The radio is operated using a rotary encoder and 4 buttons, as described below:

Rotary encoder: used to tune to radio stations

Button 1: for changing bands (14 AM and 1 FM bands)

Button 2: for changing tuning steps AM (1kHz, 5kHz, 10kHz)

Button 2: for changing tuning steps FM (100kHz, 200kHz). NEW

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

Button 3: to select the FM bandwidth filters (Aut, 110, 84, 60, 40kHz). NEW

Button 4: to select the color scheme of the display (2 schemes)

###### Antenna

About the antenna to be used. Preferably use an external Long Wire antenna and a ground connection for good shortwave reception. Other types of antennas can also be used, such as the MiniWhip and the Magnetic Loop.

For good performance in MW (LW) band should be user a standard ferrite stick antenna with 12cm x 1cm. The bigger the ferrite bar is, the better is the reception.

For the FM band, a whip or wire with 70cm will be sufficient. For DX reception, a commercial external VHF/FM antenna can be used.

###### Status per 29.11.2020

Im Weiteren hat Martin den Arduino Code angesehen und zwar die Rev ision 2.1 vom November 2020. Man muss bei den Variablen noch die Startadresse I2C ADDRESS OF SI7435 angeben. Bei der Anweisung „Byte SI7435_ADDRESS“. Entweder ist es 0x11 oder 0x63. Einmal ist es mit 0x11 SEN PIN TO GND gemeint, und sonst ist es 0x63 SEN PIN TO 3v3 verstanden. Im Schema sehe ich, dass es am IC1 an Pin 3 den GND gibt und an Pin 1 den 3V3. Pin 1 ist auf dem Schema mit Arduino verdrahtet und dort geht es auf den Anschluss 3.3V. Den genauen Pin am Arduino Uno selber kann Martin nicht aus dem Schema rauslesen. Die Antworten kommen von Dani.

Q1. Welche SI7435_ADDRESSE hast Du angegeben?
A1. 0x63, bei meinem Breakoutboard mit dem quadratischen 3020 Chip drauf ist der SEN Pin fest auf 3.3V verdrahtet.

Q2. Was ist eigentlich mit SEN gemeint? Sending? Anders? Oder ist es so, dass man dem Arduino so angibt, dass er den Ausgang 3.3 V am Arduino aktivieren soll und die 3.3 V so rausgehen?
A2. Bin mir auch nicht sicher, Sense?

Q3. Wir haben m.E. noch den quadratischen SI4730 ohne eine Nachbezeichnung (kann MW & FM) mit den 10 Pins im Einsatz. Richtig?
A3. Ja, so ein SI4030 Breakout PCB, mit einem quadratischen Chip drauf der mit 3020 bezeichnet ist, das ist meines Wissens nach die Rev. 20 (ohne SW).

Q4. Der Kollege hat m.E. bereits den SI4730-D60 (der kann schon SW, es könnte aber noch der quadratische Chip sein) angeschlossen und wir werden das Nachfolgemodell SI4734-D60 oder SI3735-D60 einsetzen? Und die Bezeichnung am Schluss mit -GU zeigt dann auf die Bauform SSOP. Die ist eher rechteckig mit Füsschen und Pins zum anlöten. Richtig?
A4. Genau, ich habe nun die SI4734-D60-GU (Bauform SSOP) bestellt. Die sind rechteckig und mit Füsschen ...

Q5. Wie bist Du sonst noch weiter gekommen? Hat das Library mischen/einfügen etwas gebracht?
A5. Nur neue Warnungen und mehr Verwirrung. Ich muss mal mehr Zeit investieren ...

###### Conf Call vom 30.11.2020 mit Mathias, Dani und Martin

###### Status: Drohne ist noch in Kanada. könnte aber im Dezember 2020 noch voraussichtlich eintreffen. Erste Tests mit WSPR und Magnetic Loop durchgeführt, Die Arbeiten mit dem Arduino und der aktuellen Source von Hackster läuft nicht. Es kommen viele Warnungen, welche analysiert werden müssen

###### Repository mit Github ev. von HB9UF planen & mittelfristig sicherstellen

###### Source Code, Libraries und Compiler Prozeduren ablegen und nachführen

###### Martin hat die Dokumentation abgelegt

###### Repository Konzept festhalten, zentrale Ablagen und dezentrale Ablagen, d.h. lokale Ablagen sicherstellen

###### wir haben unsere Unterlagen am anfangs Dezember im Repository von HB9UF

###### Zugangskonzept planen & durchführen

###### Martin muss von Mathias lernen, welche Rollen das HB9UF GitHub kennt

###### habe ich irgendwi an anderere Stelle ganz grob dokumentiert

###### man muss aber das nehmen, was GitHub zur Verfügung stellt

###### Wiki planen & durchführen

###### erster kurzer Test im Gratis-GitHub durchgeführt. Es scheint im 2020 nicht unsere erste Aufgabe zu sein

###### Ticket System planen & sicherstellen

###### die Funktion im Gratis-GitHub gesehen. Scheint im 2020 nicht unsere erste Aufgabe zu sein

###### Mathias arbeitet mal mit Windows und Arduino

###### Material zum Testen, u.a. ST7735 an Mathias schicken, verantwortlich Daniel

###### Daniel arbeitet mit Linux und Arduino weiter

###### Vorgehensweg: Wenn etwas nicht läuft, Codeteile mit der dazugehörenden Library rausnehmen und so mal arbeiten, resp. schrittweise reduzieren bis es mit dem Arduino läuft. Dann wieder schrittweise einzelen Teile wieder einbringen, usw.

###### 01.12.2020

###### Martin fragte am 01.12.2020 Elmar HB9DVF an, ob wir ein Repository vonHB9UF benützen dürfen

###### Dazu ein Grobkonzept erstellt

###### Antwort von Elmar am 02.12.20 ... ja wir dürfen. Alles Weitere zur Einrichtung des Repository/Project soll über Mathias laufen

###### Martin nimmt mit Mathias Kontakt auf

ein public Repository (die Gratisvariante) erstellt und ein paar Unterlagen drauf geladen. Die Versionierung von Mind Maps funktioniert nicht ganz so wie Martin es erwartet. Die Regel scheint nicht so zu sein, wie es bei UBS in DocWeb war (wie heisst das Tool mit dem Originalnamen auf dem Markt? Anders? Ja, aber wie?). Oder ich habe den Weg zum Ziel noch nicht gefunden

Siehe auch: Erkenntnisse , Martin konnte falsch eingestellte Dateien im Repository kommentieren & löschen, man kann aus dem zentralen Repository die Ausgabe "Main" runterladen (Martin hat noch keinen Branch angestossen) und auf dem Laptop dezentral weiter arbeiten

###### Wenn man GitHub macht, resp. anwendet dann muss man gemäss Martin als GitHub Anfänger eine Schulung von ca. 6h durchführen

###### ... Ergänzung am 17.12.2020: Es waren am Schluss ca. 3 Arbeitstage mit der Ablage von live-Unterlagen und einer Besprechung im Team für die Abmachung der Prinzipien. Es ist an einer Stelle im Mindmap dokumentiert

am Telefon berichtet Daniel, dass er neue (1-2) andere Displays erhalten hat. Er macht mal mit denen weiter. Die neuen scheinen technisch und Bezeichungsmässig eher beim erforderlichen Typ ST7735 zu sein. Daniel hat etwas von einer anderen und einfacheren Schnittstelle erwähnt. Martin hat das technisch nicht verstanden. Aber die Nachricht tönte gut

Siehe auch: das jetzige Display ST7735S wird, laut Daniiel, vermutlich mit der Original Library von Xhackster laufen

###### 02.12.2020

###### im Gratis Git Hub

###### Martin konnte falsch eingestellte Dateien im Repository kommentieren & löschen

###### man kann aus dem zentralen Repository die Ausgabe "Main" runterladen (Martin hat noch keinen Branch angestossen) und auf dem Laptop dezentral weiter arbeiten

###### Daniel kann die Unterlagen auch aus dem Repository runter laden und sie werden nachher auf seinem PC/Laptop dargestellt

###### Daniel wird einen Account lösen und dann seine Test im Gratis-GitHub planen & durchführen

###### Display

###### Das erste Display war/ist ST7735SB und hat eine SD-Speicherkarte und vier zusätzliche Pins. Mit der funktioniert die Library von Xhackster laut Daniel nicht

Siehe auch: ab 15.12.2020 erledigt

###### das jetzige Display ST7735S wird, laut Daniiel, vermutlich mit der Original Library von Xhackster laufen

###### ab 15.12.2020 erledigt

##### 15.1.1.1.4 Library einrichten

###### I2C LCD

Um mit dem I2C LCD Modul zu arbeiten benötigt man eine Library, welche noch nicht im Arduino Programm vorinstalliert ist. Diese kann man zum Beispiel unter https://github.com/fdebrabander/Arduino-LiquidCrystal-I2C-library als .ZIP Datei herunterladen. Danach muss die Library im Arduino Programm hinzugefügt werden. Das kann unter dem Punkt „Sketch“ dann „Include Library“ und „add .ZIP Library ..“ gemacht werden. Jetzt kann im Code auf die Library zurückgegriffen werden.

###### hier ist noch ein Hinweis zu entnehmen (RFID)

Beim Auslesen und verarbeiten der Daten eines RFID-Empfängers wären wie auch bei anderen komplexen Aufgaben sehr viele Zeilen Quellcode erforderlich. Daher bedienen wir uns einer vorgefertigten Library aus dem Internet. Es gibt einige verschiedene im Netz zu finden. In dieser Anleitung haben wir uns für die Library von der Internetseite

https://github.com/miguelbalboa/rfidentschieden. Damit man damit arbeiten kann, muss man sich die Library zunächst herunterladen und im Arduino Programmordner abspeichern. Auf der Internetseite klickt man dazu unten rechts auf „Download ZIP“ und speichert die gepackte Datei auf seiner Festplatte.

Danach entpackt man den Inhalt in die Arduino-Software auf der Festplatte und zwar in den Ordner „libraries“. Für gewöhnlich befindet sich der Ordner auf der Festplatte unter dem Pfad „C:Programmearduinolibraries…“ (Wenn man das Programm an einer anderen Stelle gespeichert hat, muss man dort den Ordner „libraries“ verwenden. Sobald die Datei entpackt ist, entsteht im Ordner „libraries“ die Datei „rfid-master“. Jetzt MUSS zunächst der Bindestricht entfernt werden. Man benennt den Ordner also um in den Ordner „rfidmaster“. So, das wäre geschafft. Die Library kann in der Arduino-Software verwendet werden.

### 15.1.2 GPS Eingangsprüfung durchführen

#### 15.1.2.1 GPS Bestellung

##### 15.1.2.1.1 GPS Evaluation durchführen

### 15.1.3 Daten vom SDR-Empfänger aufsammeln, zwischenspeicherm und auswerten? Datum, Zeit, ev. Frequenz oder kleines Frequenzband (WSPR Bandbreite von, Martin meint, 200 Hz), gemessene Feldstärke, Ort und Höhe mit einem GPS

#### 15.1.3.1 WSPRlite Flexi mit Sendeantenne zu SDR Chip Empfänger mit einer kurzen Empfangsantenne, alles "nicht fliegend" auf einem Pult, resp. in einem Raum oder auf einem Balkon und einem Pult (50% Aussendungszeit und Starttaste am WSPRlite Flexi beachten)

#### 15.1.3.2 GPS Messung so sicherstellen, dass wir dies zusammen mit dem SDR Empfänger auf die Drohne platzieren können

## 15.2 Test Case 1

### 15.2.1 die Motoren zeigen bei einem Test mit einer (1) älteren Drohne bei Dani am 30.10.2020 am Analyser praktisch keine Störungen an/auf

#### 15.2.1.1 eine Drohne gleich neben einem SDRPlay RSP1A unter Windows und SDRuno mit einer kurzen Empfangsantenne laufen lassen und prüfen, ob u.a. die Motoren den Empfang stören oder nicht. Wie verhält sich u.a. der Rauschpegel?

Siehe auch: die Motoren zeigen bei einem Test mit einer (1) älteren Drohne bei Dani am 30.10.2020 am Analyser praktisch keine Störungen an/auf

##### 15.2.1.1.1 auf nächste Woche geplant

###### hat Martin mit dem ICOM 705 am 05.11.2020 durchgeführt

Siehe auch: WSPRlite Flexi mit 200 mW

#### 15.2.1.2 uns wird klar, dass man diesen Test mit der neuen Drohne aus den USA wiederholen muss, wenn sie eintrifft, resp. bei jeder anderen Drohne natürlich auch

##### 15.2.1.2.1 es könnte sogar ein Testpunkt vor jedem Drohnenstart sein

### 15.2.2 Martin könnte bei Dani am 06.11.2020 mit dem ICOM 705 nochmals den Motorentest messen. Kommen wir auf das gleiche Resultat?

## 15.3 Test Case 2

### 15.3.1 WSPRlite Flexi mit 200 mW an einer kurzen Antenne mit der obigen Konfiguration, prüfen, oder

Siehe auch: ICOM 705 mit 1 Watt und der WSPR Software zum Senden bringen und eine kurze Antenne mit der obigen Konfiguration prüfen, oder

#### 15.3.1.1 Lutz meldet am 30.10.2020, dass beide WSPR's am Lager sind und die Versandkosten 10.- CHF betragen

##### 15.3.1.1.1 Martin bestellt einen WSPRlite

##### 15.3.1.1.2 zuerst den Betrag am Sonntagabend mit XYL überweisen. Wurde dann erst am Montag 01.11.2020 gemacht

##### 15.3.1.1.3 alles bestellte Material liegt am 04.11.2020 bei Martin vor

Siehe auch: WSPRlite Flexi mit 200 mW

#### 15.3.1.2 Martin hat zwei ganz kleine EH-Antennen, zwei für 80m und zwei für 20m in der Länge von 50 cm, resp. 1m. Die könnten wir für einen Inhouse Messversuch bei Dani oder Martin einsetzen

Siehe auch: kleinen und sehr leichten SDR Empfänger mit WSPR Empfangssignal testen

##### 15.3.1.2.1 "out door" gehen die Antennen natürlich auch

### 15.3.2 Vorbehaltener Entschluss sofern es mit WSPRlight Flexi betreffend Power und Sendezeit nicht geht

#### 15.3.2.1 ICOM 705 mit 1 Watt und der WSPR Software zum Senden bringen und eine kurze Antenne mit der obigen Konfiguration prüfen, oder

##### 15.3.2.1.1 Entscheid: am 31.10.2020: lassen wir das, weil wir die Variante WSPRlite Flexi verfolgen

## 15.4 Test Case 3

Siehe auch: Test Case 0

### 15.4.1 kleinen und sehr leichten SDR Empfänger bauen

#### 15.4.1.1 Den SDR Chip hat Dani bestellt und berichtet am 31.10.2020, dass er den Testaufbau gemäss dem Schema mal probieren wird. Dann haben wir etwas in der Hand und können so den SDR Chip und die Ausgabedaten testen

##### 15.4.1.1.1 am 18.11.2020 SDR Chip eingetroffen

##### 15.4.1.1.2 Testaufbau auf dem Steckbrett liegt am 01.12.2020 vor

##### 15.4.1.1.3 am 01.12.2020 neues Display eingetroffen

##### 15.4.1.1.4 am 01.12.2020 läuft es noch nicht

### 15.4.2 kleinen und sehr leichten SDR Empfänger mit WSPR Empfangssignal testen

### 15.4.3 kleiner und sehr leichten SDR Empfänger im Drohnenflug mit WSPR Empfangssignal testen

## 15.5 Test Case 4

### 15.5.1 Empfängerüberlast

#### 15.5.1.1 Dani 31.10.2010, Abschwächer 10-30 dB kann mit IC geschaltet werden

##### 15.5.1.1.1 Wir würden bei einer sehr starken Sendeantenne sicher eine 60 dB Dämpfung benötigen

#### 15.5.1.2 wir könnten die Schaltung mit der Glühlame, welche wir mit Mathias HB9FRV geplant & gebaut haben, für den Überlastfall vor dem WSPRlite Flexi einschlaufen

##### 15.5.1.2.1 aber ... wie ist nun das gemessene Empfangssignal? Das funktioniert nicht, resp. es wäre nur eine Überlastsicherung

## 15.6 Test Case 5

### 15.6.1 WSPR sendet 1 min 51 sec und dann erst wieder auf die volle Minute, resp. per 01 oder 02 (eine ganz leicht verspätete Aussendung ist mit der erwarteten zeitlicher Verschiebung über mehrere Tage nicht so empfindlich ...)

15.6.1.1 die Drohne müsste ggfs. dann ca. 10 Sekunden in der Luft stehen bleiben, bevor sie weiter fliegt & weiter misst. Achtung diese Aussage stimmt leider nicht ganz. Es ist eine sogenannte 50% Aussendung. Habe aber am 10.11.2020 gemerkt, dass die Aussendungen auch ab und zu länger ausbleiben. Man müsste in einem solchen Fall bei dem WSPRlite Flexi auf die Starttaste drücken (dabei ist die organisatorische Aktion und die Möglichkeit einer 100m weit abgesetzte Antenne zu beachten!?)

##### 15.6.1.1.1 sie fliegt laut Dani mit 50-100 km/h

##### 15.6.1.1.2 wie lange dauert ein Flug mit 36 km/h im Radius um die Antenne von 50m, 100m 150m und 200m?

###### 36 km/h sind 10 m/s

###### 50m Radius mal 2 mal 3.14 = 100 x 3 = ca. 300, d.h. mit 10 m/s dauert ein Kreis rund 30 Sekunden

###### Für eine maximale Höhe von 150m sind in 5m Höhenschritte somit 30 Runden, ohne NVIS Messung, zu erfliegen. Eine Messung dauert dann mit 36 km/h somit 900 Sekunden oder 15 Minuten

Siehe auch: fliegt die Drohne mit 72 km/h dauert alles nur noch die Hälfte und somit 4,5 Minuten, NVIS Messung: auf 50m Höhe die Kreise in 5m Schritten verkleinern, bis sich die Drohne in der Luft in der Mitte, d.h. gerade über der Antenne befindet/stillsteht. Danach Landung oder nächsten Messauftag einleiten.

###### bei einem Radius 50 m auch nur in 5-er Schritten bis 50m Höhe fliegen, dauert es 10 Runden und somit 300 Sekunden also 5 Minuten

###### 100m Radius, 200 x 3 = 600, dauert es rund 60 Sekunden

###### fliegt die Drohne mit 72 km/h dauert alles nur noch die Hälfte und somit 4,5 Minuten

###### NVIS

###### NVIS Messung: auf 50m Höhe die Kreise in 5m Schritten verkleinern, bis sich die Drohne in der Luft in der Mitte, d.h. gerade über der Antenne befindet/stillsteht. Danach Landung oder nächsten Messauftag einleiten.

##### 15.6.1.1.3 wir könnten in 5m Höhe (Sicherheitshöhe) anfangen und in 5m Schritten nach oben bis in die maximale Flughöhe von 150m messen

#### 15.6.1.2 wir könnten auch in einer Distanz von xy-Meter einfach mal mit der Drohne senkrecht 150m hoch fliegen lassen und so den Abstrahlungswinkel messen . Distanz dann jeweils um 20-40m erhöhen und wieder in verschiedenen Höhen messen

##### 15.6.1.2.1 das könnten wir mit auch älteren Drohnen durchführen (einfach, kein Risiko)

##### 15.6.1.2.2 drehbare Antennen wären so einfach ausmessbar

##### 15.6.1.2.3 das schafft die Drohne in einem Messdurchgang (1 min 51 sec)

#### 15.6.1.3 Zeitmanagement & Akku-Management

##### 15.6.1.3.1 Dani meinte mal, dass die Akku 10-15 Minuten halten würden

## 15.7 Test Case 6

### 15.7.1 GPS

#### 15.7.1.1 Ein GPS misst laut Daniel auf ca. einen (1) Meter genau. Wir prüfen, ob wir einen GPS Empfänger neben dem SDR Empfänger einbauen können

##### 15.7.1.1.1 so könnte man auch ohne Drohne eine Antenne messen und z.B. mit dem Auto herumfahren oder zu Fuss unterwegs sein und messen oder eine drehbare Yagi-Antenne auf einen Berg richten und mit dem Auto die Strasse hoch- und runterfahren und so den Abstrahlwinkel messen

#### 15.7.1.2 ist vermutlich eine ANF ....

## 15.8 Test Case 7

### 15.8.1 Welchen Einfluss hat das Nahfeld und das Fernfeld auf die Abstrahlungsmessung und/oder Abstrahlwinkelmessung? Merkt man dies bei der Messung? Oder ist dies ein Punkt, welcher in den Fachgesprächen einfach weiter geplappert wird.

#### 15.8.1.1 wer hat dies schon wirklich gemessen? Und wenn ja, wie wurde das gemessen?

##### 15.8.1.1.1 die Ansichten gehen auseinander wo genau das Fernfeld anfängt. 2 Lambda, 5 Lambda oder 10 Lambda? anders? Wie?

###### wir werden es vermutlich herausfinden, wenn wir "fliegen"

15.8.1.2 Martin hat an seinen Loops mit dem Electromagnetic Radiation Tester zwar die uTesla gemessen und in nur 2 cm Abstand von der M.L. schon 1200 V/m gemesen. Deshalb glaube ich die Aussage rechts nicht mehr und behaupte, dass das magnetische Feld und das elektrische Feld viel näher beieinander sind

### 15.8.2 erster Feld Test am 07.11.2020 auf dem Herrenberg

#### 15.8.2.1 Sendeantenne die EH-Dipol mit den Haarspraydosen für 20m Band mit SWR 3.0, etwa 60° schräg in 4m Höhe aufgehängt, WSPRlite Flexi. Als Empfänger ICOM 705 mit einer ca. 100 cm langen Lautsprecherlitze (analog als mögliche Empfangsantenne an einer Drohne)

##### 15.8.2.1.1 WSPRlite Flexi 5 mW hat in unmittelbarer Entfernung zur Sendeantenne ein S9+8, in 10m ein S3 und in 20m ist der Empfangspegel kleiner S3

###### die ca. 100 cm lange Empfangsantenne lag einfach auf der Ladefläche vom Kombi des Subarus

##### 15.8.2.1.2 WSPRlite Flexi mit 100 mW hat in unmittelbarer Entfernung zur Sendeantenne ein S9+25 oder S9+30 in 10m ein S8, in 20m ein S5 und in 35m ein Signal kleiner S3. Wenn man dort den Draht der 50 cm langen Empfangsantenne senkrecht hält, ist es ein S5 Signal

##### 15.8.2.1.3 WSPRlite Flexi mit 200 mW hat ein S9+30

###### WSPR Aussendung, man muss mit einer Atomuhr auf dem Handy bei einer gerade Minute auf 01 oder 02 Sekunde starten, zeigt nur eine Station HB9NF mit SNR -21 dB an

Siehe auch: die in der Luft hängende 60° schräge Haarspraydosen Antenne verbessert das Ergebnis eigentlich auch nicht so gut ...

###### Ist die Haarspradose wirklich so schlecht? Ich hatte doch zu Hause kurz vor Mitternacht auf 20m mit RBN in ca. 10m Höhe aus dem Dachfenster hinaus eine Station aus D und eine aus F und war sehr stolz auf das Ergebnis

###### Wieso hatte ich damals mit dem herunter hägenden Koaxkabel aus dem Dachfenster hinaus in 10m Höhe (simit ca. 15m über Grund) ein gutes SWR auf 20m und auf dem Herrenberg in 4m Höhe nicht mehr? Es sah doch im Hinblick auf das Koaxkabel in etwa gleich aus ...

#### 15.8.2.2 Fragen & Antworten

Siehe auch: Fragen

##### 15.8.2.2.1 Wie nimmt schon wieder der Empfangspegel mit der Distanz ab? Quadratisch?

##### 15.8.2.2.2 Welchen Einfluss hat die Empfangsantenne, wenn sie senkrecht oder vertikal steht? Und die Sendeantenne als Dipol vertikal steht

###### die in der Luft hängende 60° schräge Haarspraydosen Antenne verbessert das Ergebnis eigentlich auch nicht so gut ...

##### 15.8.2.2.3 Wie sieht das Ganze an der Stealth Loop Antenne von Ciro Mazzoni im Garten aus? Ein WSPR-Test kostet fast keinen Aufwand

###### 11.11.2020

###### Relativ gesehen schwache Reports von HB9NF. Zum Messen des Empfangssignals selber könnte es im Umkreis von 200m locker passen

Siehe auch: ich kann auch die HB9LU Loop Indoor zum Senden verwenden und dann draussen messen

##### 15.8.2.2.4 ich kann auch die HB9LU Loop Indoor zum Senden verwenden und dann draussen messen

Siehe auch: Wie sieht es aus mit der HB9LU Magnetic Loop (ML) auf 20m? Die könnte man später auch problemlos ins Feld mitnehmen

##### 15.8.2.2.5 Wie sieht es aus mit der HB9LU Magnetic Loop (ML) auf 20m? Die könnte man später auch problemlos ins Feld mitnehmen

###### Ja, die ML sendet am 09.11.2020 erfolgreich Indoor mit einem SWR 1.2 und interessanterweise gibt auch hier, das WSPRlite sendet ebenfalls wie am Samstag mit 200 mW, HB9NF mit SNR -16 dB eine Antwort, d.h. 5-8 dB besser als die Haarspray EH-Dipol Antenne (das ist eine (1) S-Stufe

###### Der Empfang-Wert schwankt ein bischen und die Frequenz auch

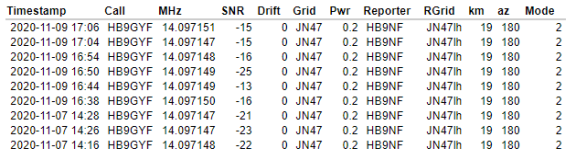
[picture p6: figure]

###### es sind plötzlich schlechtere SNR-Werte eingetroffen. Martin hat mit dem RigExpert gemerkt, dass das SWR viel schlechter geworden ist. Es scheint der BNC an der CL zu sein

###### Ursache gefunden & behoben. Schlechter Kontakt im/am BNC Stecker bei der CL

###### es ist vermutlich auch noch der BNC Stecker mit dem Kabel. Ab und zu ist das SNR nicht gut und man findet dann auch den Dip nicht oder der Dip ist schlecht

###### warum habe ich nur Rückmeldungen von HB9NF? Und sonst von keinem anderen Reporter?

###### Update Firmware von 1.1.4 auf 1.1.6 vom 20190103 am 09.11.2020 um 1031 pm durchgeführt

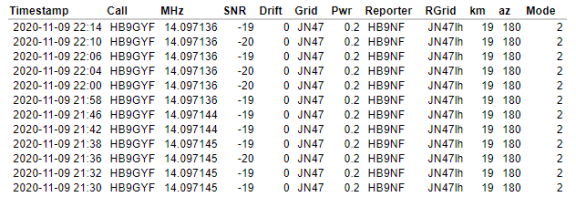
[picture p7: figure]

###### noch nicht verstanden, wie man die Frequenz einstellt. Habe unter FW 1.1.6 wieder auf 14.097145 gestellt, aber nun ist der Empfang auf 14.097136. Nicht verstanden warum ...

###### nach dem Firmware Update auf 1.1.6 hatte ich zuerst auf 14.097153 gestellt und m.E. wurde keine Aussendung von HB9NF dekodiert, resp. ich bin mir plötzlich zum Timestamp nicht mehr sicher. Der müsste doch UTC sein. Begründung, die Software läuft ja weltweit

###### noch nicht verstanden, wie breit die Bandbreiten wirklich sind. Es wird behauptet 5,9 Hz. Toleranz auch nicht verstanden

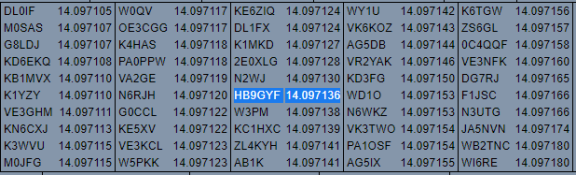
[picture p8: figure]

###### unter diesem Link kann man auf allen Bändern nachsehen, welche Station wo sendet, resp. einen Platz belegt

###### http://wsprnet.org/drupal/wsprnet/activity

Siehe Dokument(e): http://wsprnet.org/drupal/wsprnet/activity

###### ich erkenne Überschneidungen bei Bandbreiten von 6 Hz

###### plötzlich eine leicht andere Frequenz, denn sie steht jetzt auf 14.097135

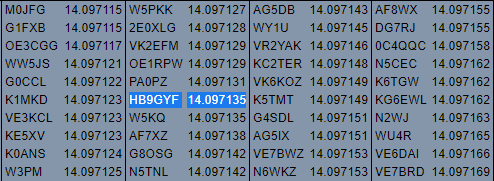
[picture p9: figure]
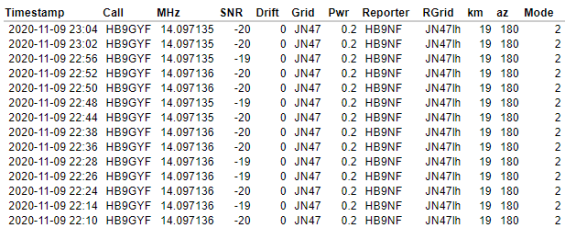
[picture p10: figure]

###### Wenn HB9BNF sendet, und ich weiss nicht wann, aber dann erkennt der meine Aussendung während seiner Aussendung natürlich nicht

###### Warum kommt Mode 2? Ich habe doch Mode 1 eingestellt, oder ist das nicht das gleiche?

###### Werden eigentlich eine oder zwei Aussendungen vorgenommen?

###### am Anfang, d.h. nach dem Drücken der Taste auf dem WSPRlite Flexi zur Sekunde 01/02 sind es beim ersten Mal jeweils zwei Aussendungen hintereinander

###### bei der WSPR Abfrage aus der Datenbank, kann man 2, 5, 15 oder 30 angeben. Die Werte 15 sind für Mode -2 & -15. Der Wert 30 ist Beta für FST4W MF/LF mode 300 & 1800

Siehe auch: Ich habe in meiner Config auch einen 6-stelligen Locator eingetragen,, aber das ändert bei mir nichts. Es kommt immer ein 4-stelliger Locator aus der Datenbank -->das hat mit Mode 2 zu tun

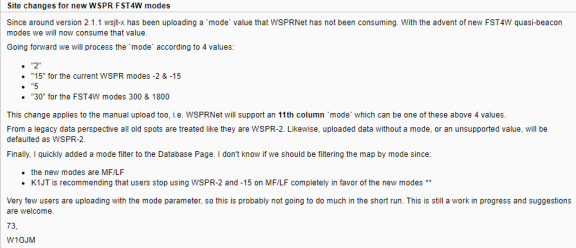
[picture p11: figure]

###### alle alten Spots werden unter Type 2 geführt

Siehe auch: a8

###### ich habe zuerst die Coupling Loop (CL) verwendet, welche wir in Luzern im Restaurant Listrig bauten

###### Noch die kleine CL mit 60 cm Länge 3x2,5 mm2 ausprobieren

###### der Reporter HB9NF meldet einige WSPR Stationen mit Mode 2 und die haben zum Teil wirklich 6-stellige Locators

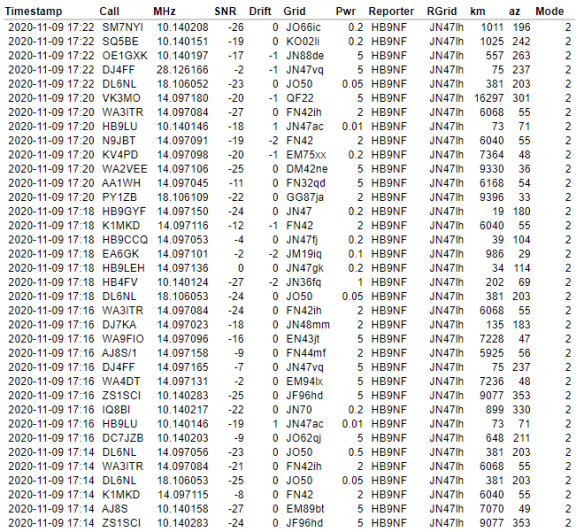
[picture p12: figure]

###### Ich habe in meiner Config auch einen 6-stelligen Locator eingetragen,, aber das ändert bei mir nichts. Es kommt immer ein 4-stelliger Locator aus der Datenbank -->das hat mit Mode 2 zu tun

Erstens, nun taucht jetzt am 10.11.2020 wieder ein Punkt auf, welchen ich schon mal herausgefunden habe. Wenn die CL im Umfang zu klein ist, ist der Dip nicht genügend ausgeprägt, resp. tief und sporadisch geht er nach einer gewissen Zeit wieder hoch. Zweitens, macht mir das RG58 Kabel (ich habe deren drei ausprobiert) ab und zu Mühe. Gibt es eigentlich mechanisch leicht unterschiedliche BNC-Stecker? Kontaktpobleme?

###### habe nun die grösste 3x2,5 mm CL mit U=1m eingesetzt. Das SWR kommt so schön runter 1.1

###### aber ab und zu "rutscht" das SWR wieder auf 3 hoch ... warum?

###### Toll, nun kommt noch ein weiterer Reporter HB9CCQ dazu

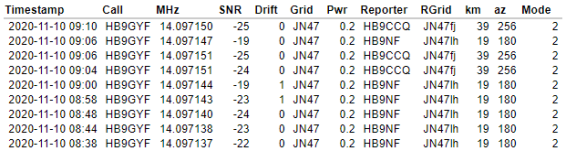
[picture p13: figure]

###### das beste Resultat des Tages mit einem RG58 Kabel von dem HB9LU ML-Kurs und der 1m langen 3x2,5 mm2 CL. Das SWR liegt 1.2 herum

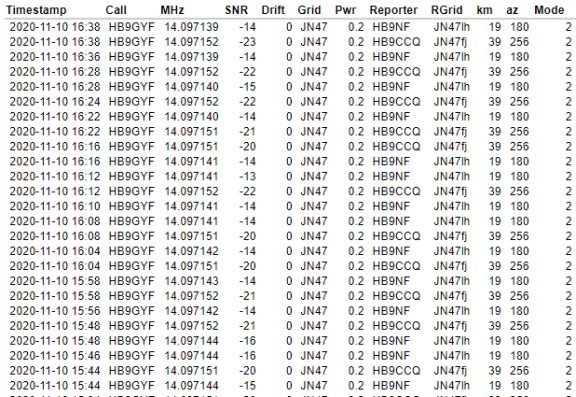
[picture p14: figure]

# 16 Datenschutz & Bewilligungen

## 16.1 wenn man mit einer Drohne bis auf eine maximale Höhe von 150m fliegt, muss man die Einwilligung von den Grundeigentümer und den Bewohner haben. Je nachdem wie weit wir fliegen (Nahfeld/Fernfeld) ist dieser Aspekt nicht unerheblich oder eventuell sogar ein Killerpunkt

### 16.1.1 Umgehung: Wir könnten bei den ersten Versuchen auf einem Modell Flugplatz testen, dort ist das fliegen ja erlaubt

#### 16.1.1.1 auf einem Modellflugplatz darf man gemäss Dani bis auf 300m Höhe fliegen

### 16.1.2 mit mehreren Grundeigentümer und den Bewohnern das Ganze absprechen wollen wir echt nicht während den Versuchen für Proof of Concept und vermutlich auch später nicht

# 17 Killerpunkte

## 17.1 die Killerpunkte müssen wir möglichst früh erkennen & festhalten

## 17.2 Übersteuerungsthematik

### 17.2.1 02.11.2020

#### 17.2.1.1 Wenn der Sender (beim WSPRlite vermutlich nicht, aber bei einer Antenne mit 100 W oder 1 KW u.U. schon) der zu messenden Antenne sendet, darf es den Empfänger zur Steuerung der Drohne nicht "zu machen" oder übersteuern (Bemerkung am Höck vom 02.11.2020 per Video Conf)

## 17.3 WSPRlite mit 50% Aussendung

### 17.3.1 04.11.2020

#### 17.3.1.1 WSPRlite Flexi sendet maximal 50% von einer Stunde oder mehr aus, d.h. nur je zwei Minuten, resp. 1 min 51 sec lang, und dann ist zwei Minuten Pause. Oder man drückt auf die Sendetaste

### 17.3.2 05.11.2020

17.3.2.1 Wird die Taste gedrückt, dann wird sofort gesendet und die LED leuchtet rot. Drückt man für eine ordentliche Aussendung die von anderen WSPR Empfänger aufgenommen werden soll und so in die WSPR Datenbank aufgenommen werden soll, zu früh, kann der Benutzer jeweils in einer graden Minuten wieder zur Sekunde 02 für die nächste Aussendung, resp. Start, die Taste drücken und so synchronisieren (dazu eine Atomuhr benutzen)

### 17.3.3 06.11.2020

#### 17.3.3.1 Alternative: Zum WSPRlite Flexi könnte man z.B. ein ICOM 705 mit 0,5 W einsetzen und eine vorprogrammierbare CW-Meldung mit 13 WPM absetzen, z.B. zuerst "qrl? qrl?" und dann "de hb9gyf/p hb9gyf/p antenna characteristic and radiation angle checking with a drone"

##### 17.3.3.1.1 diese Meldung während der Ausmessung dann laufend wiederholen lassen

## 17.4 nur ca. 100 cm lange KW-Empfangsantenne beim SDR Chip bei der Drohne

### 17.4.1 10.11.2020

#### 17.4.1.1 die WSPR-Signalstärke muss im Bereich von 1 bis 5 eventuell 10 Lambda (bei 20m sind das 100m, resp. 200m) noch gut auswertbar/messbar sein

17.4.1.1.1 man stelle sich den Unterschied beim Empfangssignal vor ... ein 2x5.05m Dipol auf 5m Höhe in 200m Distanz zur zu messenden drehbaren Antenne fest am Boden montiert oder eine flatternde 100 cm lange Laufsprecherlitze senkrecht nach unten hängend (Drohne steht in der Luft "Position Hold") oder die100 cm lange Laufsprecherlitze flattert horizontal in der Luft (Drohne fliegt mit 36 km/h einen Radius in n-m Höhe um die zu messende Antenne

###### oder müssen wir auf EndFed und ev. verkürzte EndFed umschalten/umdenken? Oder sind es einfach nur ca. 2.5m Lautsprecherlitze an Stelle von 100 cm für den KW-Empfang? Vertikal nach unten hängend?

## 17.5 potentieller Killerpunkt für/gegen WSPRlite Flexi Realisierung mit maximal 200 mW

### 17.5.1 11.11.2020

#### 17.5.1.1 WSPRlite Flexi auf 5 mW Leistung reduzieren und mit verschiedenen Empfangsantennen einen Test durchführen

##### 17.5.1.1.1 100 cm Lautsprecherliste

###### in 10m Entfernung inhouse ergibt sich ein S8 bis S8 auf dem ICOM 705

###### mit dem Tecsun 880e kann man das WSPR-Signal auch noch recht gut nachweisen/messen/austesten. Habe noch keine Erfahrungen betreffend dem Signalpegel auf dem Tecsun S-Meter. Inhouse hat es in 10m Entfernung gut geklappt. Outdoor Versuch noch planen & durchführen

##### 17.5.1.1.2 2.5 m Lautsprecherlitze

###### in 10m Entfernung inhouse ergibt sich ein S9 auf dem ICOM 705

##### 17.5.1.1.3 Kartonspule oder Luftspule

###### der Empfang am ICOM 705 auf dem 40m Band ist mit der Kartonspule sehr schwach. Auch mit einem winzigen Dipol aus zwei Kartonspulen ebenfalls. Man merkt es an dem Rauschen, welches idR mit Preamp 2 kleiner S3 ist

##### 17.5.1.1.4 Ferritkern mit einer Wicklung für das 20m Band

###### hat jemand00 einen Ferritkern oder Ferritstab?

###### am14.11.2020 im Brocki ein Kofferradio für 5.- Fr gekauft und daraus den Ferritstab genommen

Siehe auch: die Wicklungen darauf sind beim Kofferradiomit HF-Litze erstellt worden. Das Zeug ist echt sehr, sehr dünn. Ich selber wickelte ad hoc, d.h. ohne Berechnung, mit 0.28 mm Cu-Draht und erreichte glücklicherweise ein Dip oben im 20m Band

###### Dani hat am 14.11.2020 zwei Ferritstäbe aus China bestellt

###### die Wicklungen darauf sind beim Kofferradiomit HF-Litze erstellt worden. Das Zeug ist echt sehr, sehr dünn. Ich selber wickelte ad hoc, d.h. ohne Berechnung, mit 0.28 mm Cu-Draht und erreichte glücklicherweise ein Dip oben im 20m Band

###### die Zuschaltung eines Plattenkondensator beeinflusste die Resonanzfrequenz nur mariginal

###### Warum? Nicht begriffen ...

###### ich habe im Moment noch kein Messgerät für ein "kleines" Henry und für Kondensatormessung um schätzungsweise nachzumessen. Dani wird eines vorbei bringen

###### Es wurde schlussendlich am 16.11.2020 ein Ferritstab verwendet

###### am 16.11.2020, mit 5 mW aus dem WSPR Flexi erreichte ich ein S9+10 Signal in 2m Distanz. Der Ferritstab ist somit rund 10 dB schwächer als der 1m lange Draht

Siehe auch: in 10m Entfernung inhouse ergibt sich ein S8 bis S8 auf dem ICOM 705

17.5.1.2 Warum soll man die Leistung auf 10 mW reduzieren? Man hätte so die Möglichkeit die Sendeleistung noch auf 200 mW zu erhöhen. Das wären zwei S-Stufen. Man könnte so bei einer z.B. über 100m verwenden Koaxkablen RG213 abgesetzten Antenne die Leistung erhöhen um den Kabelverlust von ca. 7 dB auszugleichen

## 17.6 starke/s WSPR-Sendesignal/e gleichzeitig auf unserem Empfänger SI47xx-D60 während unserem Messflug, welche unser WSPRlite Flexi Sendesignal aus der zu messenden Antenne übertreffen

### 17.6.1 23.11.2020

#### 17.6.1.1 bei einer Feldmessung mit einem 10m langen Draht ist mir aufgefallen, dass WSPR Signale mit S5 zu hören/messen waren

Siehe auch: einmal testen, ob ich beim WSPRlite Flexi auch eine Frequenz ausserhalb der WSPR-Bandes von ca. 200 Hz einstellen kann. So könnten wir diesen Punkt umgehen und müssten nicht darauf hoffen, dass während dem Messflug kein anderes starkes WSPR-Signal aus der Umgebung reinkommt

#### 17.6.1.2 einmal testen, ob ich beim WSPRlite Flexi auch eine Frequenz ausserhalb der WSPR-Bandes von ca. 200 Hz einstellen kann. So könnten wir diesen Punkt umgehen und müssten nicht darauf hoffen, dass während dem Messflug kein anderes starkes WSPR-Signal aus der Umgebung reinkommt

# 18 Use Cases (UC's) für die Drohne und deren Steuerung

## 18.1 Fragen von Martin 06.11.2020

### 18.1.1 die Drohne ist physikalisch klein und in 150m Höhe ist sie für den Piloten nicht mehr sehr gut sichtbar. Auch die Fluglage ist u.U. vom Boden aus nicht mehr klar erkenntlich

Siehe auch: Eigentlich ist es verboten mit Flugobjekten ohne direkten Sichtkontakt zu operieren

#### 18.1.1.1 UC: Der Pilot muss einen Befehl an die Drohne senden können "Halte die Lage & Position bei"

Siehe auch: Ein "Position Hold" und ein "Coming Home" sind Grundfunktionen von GPS gesteuerten Drohnen

### 18.1.2 es windet regelmässig oder unregelmässig in der Höhe

Siehe auch: UC: Der Pilot muss einen Befehl an die Drohne senden können "Halte die Lage & Position bei"

#### 18.1.2.1 UC: Senkrecht auf- und abfliegen und dabei die Position halten (GPS)

Siehe auch: Ein "Position Hold" und ein "Coming Home" sind Grundfunktionen von GPS gesteuerten Drohnen

### 18.1.3 die Drohne erkennt u.U. eine Hochspannungsleitung nicht, oder sie erkennt den Antennendraht einer Windom F5 Antenne nicht

Siehe auch: Wie genau die Objekterkennung ist, muss Dani wohl erfliegen. Ja, ein dünner Draht kann schon schwierig werden.

#### 18.1.3.1 UC: Eine Art Flugverbotszone/n soll vor dem Flug definiert werden können

Siehe auch: Andere komerzielle Drohnen werden mit "offiziellen Flugverbotzonen" ausgeliefert und der entsprechende z.B. Flughafen muss ein Entsperrcode geben, damit trotzdem geflogen werden kann., Freiwillige Sperrzonen zu definieren ist vielfach möglich.

### 18.1.4 Der Pilot hat u.U. das Zeitmanagement im Zusammenhang mit dem Akku Management nicht immer im Griff

#### 18.1.4.1 UC: Wenn die Akkus zur Neige gehen, soll die Drohne zum Startpunkt fliegen und dort entweder in z.B. 50m Höhe auf den Landebefehl warten oder automatisch landen

Siehe auch: Eine "Batteriestandskontrolle" ist üblicherweise in der Telemetrie enthalten und ein Unterschreiten einer Schwelle kann dann vom RC-Sender z.B. in ein Piepston oder eine Vibration interpretiert werden

#### 18.1.4.2 UC: Status der Drohne anzeigen und ggfs. einen hörbaren Ton für den Piloten aussenden

### 18.1.5 man weiss als Pilot u.U. nicht mehr genau wo die Drohne ist, wenn sie z.B. in einem grösseren Radius um die Antenne herum fliegt oder sie ist nicht im Blickfeld des Piloten (Rücken) und sie dabei den Empfangspegel misst

18.1.5.1 UC: Der Pilot soll auf einen einfachen Befehl/Bedienung hin die Drohne dazu veranlassen, dass sie zum Startpunkt zurückfliegt und dort in z.B. 50m Höhe stehen bleibt. Der Pilot kann dann einen neuen Flugbefehle erteilten oder den den erteilten Flugbefehl fortsetzen lassen oder z.B. senkrecht nach unten eine Landung einleiten

Siehe auch: Ein "Position Hold" und ein "Coming Home" sind Grundfunktionen von GPS gesteuerten Drohnen

#### 18.1.5.2 UC: Fluglagedarstellung

Siehe auch: Fluglagen werden üblicherweise auch per Telemetrie übermittelt und können auf dem RC-Sender ev. grafisch angezeigt werden

## 18.2 Antworten von Dani 07.11.2020

### 18.2.1 Eigentlich ist es verboten mit Flugobjekten ohne direkten Sichtkontakt zu operieren

### 18.2.2 Ein "Position Hold" und ein "Coming Home" sind Grundfunktionen von GPS gesteuerten Drohnen

### 18.2.3 Eine "Batteriestandskontrolle" ist üblicherweise in der Telemetrie enthalten und ein Unterschreiten einer Schwelle kann dann vom RC-Sender z.B. in ein Piepston oder eine Vibration interpretiert werden

### 18.2.4 Wie genau die Objekterkennung ist, muss Dani wohl erfliegen. Ja, ein dünner Draht kann schon schwierig werden.

### 18.2.5 Andere komerzielle Drohnen werden mit "offiziellen Flugverbotzonen" ausgeliefert und der entsprechende z.B. Flughafen muss ein Entsperrcode geben, damit trotzdem geflogen werden kann.

#### 18.2.5.1 Freiwillige Sperrzonen zu definieren ist vielfach möglich.

### 18.2.6 Fluglagen werden üblicherweise auch per Telemetrie übermittelt und können auf dem RC-Sender ev. grafisch angezeigt werden

# 19 Was kann die Drohne, welche Dani bestellte?

## 19.1 03.11.2020

### 19.1.1 die Drohne "Skydio 2 mit Cinema Kit" ist schnell, mit hochauflösenden Bildern, resp. Film

#### 19.1.1.1 Film siehe hier

##### 19.1.1.1.1 https://www.skydio.com/pages/skydio-autonomy

### 19.1.2 ups, unser Projekt wurde schon mal realisiert

#### 19.1.2.1 USING A HACKRF AS A BEACON TRANSMITTER ON A DRONE FOR ANTENNA CALIBRATION

##### 19.1.2.1.1 https://www.rtl-sdr.com/using-hackrf-beacon-transmitter-drone-antenna-calibration/comment-page-1/

## 19.2 11.11.2020

### 19.2.1 die Drohne sendet vermutlich auf 2.4 GHz und nicht wie die anderen Modellfluggeräte auf 868 MHz

### 19.2.2 die Drohne wird laut Dani ohne FLARM geliefert

# 20 Spulen wickeln & messen

## 20.1 16.11.2020

### 20.1.1 mit einem Papier einen Spulenkörper erstellen und den möglichst satt aber doch noch rutschbar auf dem Ferritstab anbringen

#### 20.1.1.1 eine Art Pergamentpapier funktioniert am 18.11.2020 ganz gut

### 20.1.2 die Wicklung als Kreuzwickelspule, resp. wilde Wicklung anbringen

#### 20.1.2.1 diese beiden Typen auf der linken Seite, resp. Arten von Wicklungen nicht verstanden und in Wiki auch nichts dazu gefunden

##### 20.1.2.1.1 Korbboden-Wicklung

##### 20.1.2.1.2 Waben-Wicklung

### 20.1.3 im Moment noch mit 0.28 mm Cu Lackdraht gewickelt

#### 20.1.3.1 0.1 mm Cu Lackdraht bei Reichelt am 16.11.2020 bestellt

#### 20.1.3.2 gelernt, dass es HF-Litze in schier unermesslichen unterschiedlichen Typen gibt. Die Dinger sind z.T. sehr, sehr dünn mit 7x 0,07 mm

##### 20.1.3.2.1 irgendwie scheint der Vorteil von HF-Litze gegenüber Festdraht bei der Obergrenze von mehreren 100 kHz zu liegen

##### 20.1.3.2.2 ich konzentriere mich auf 14 MHz im 20m Band

20.1.3.2.3 Wilde Wicklung mit 0.28 mm Cu-Draht auf einem 10 mm Ferritkern funktioniert zufälligerweise im20m Band. Habe aber nicht gezählt wieviele Wicklungen ich getätigt habe, und der parallele Kondensator 5-30 pF bringt fast nicht, resp. die Res f verschiebt sich nur mariginal . Habe ihn deshalb weggelassen

## 20.2 18.11.2020

### 20.2.1 Dani meldet: Anbei ein Artikel von gestern, aber für uns sehr passend

#### 20.2.1.1 toller Artikel und Video

### 20.2.2 https://hackaday.com/2020/11/17/portable-ham-antenna-uses-smd-capacitors/

Siehe Dokument(e): https://hackaday.com/2020/11/17/portable-ham-antenna-uses-smd-capacitors/

## 20.3 19.11.2020

20.3.1 meine kleinste 20m Antenne gebaut (rund 12x40 mm lang, Antenne 60 mm lang) mit 3 primär Windungen doppelt und dann rund 20 sekundär Windungen mit 0.28 mm Cu-Draht. Lieber zuerst 30 Windungen wickeln (Res f ist dann zu tief) und dann abwicklen. Auch hier hat der parallele zur Primärwicklung geschaltete 5-30 pF Kondensator fast keinen Einfluss. Habe ihn einfach weggelassen

Siehe auch: der Drehko mit den drei zuschaltbaren Kondensatoren aus dem HB9LU Magnetic Loop Projekt eignet sich sehr gut, um die Res f eines bewickelten Toros einzustellen

#### 20.3.1.1 Dani hat noch ein paar so Torus-Kerne. Mit einem solchen ebenfalls ein Exemplar erstellen

Siehe auch: Was ist das? Eine Toroidspule, auch Kreisringspule, Ringspule oder Ringkernspule genannt

#### 20.3.1.2 Was ist das? Eine Toroidspule, auch Kreisringspule, Ringspule oder Ringkernspule genannt

## 20.4 20.11.2020

### 20.4.1 Dani hat Links von FM/MW Antennen von Ali-Express zum Studium geschickt

#### 20.4.1.1 https://de.aliexpress.com/item/4000125449068.html

#### 20.4.1.2 https://de.aliexpress.com/item/4000666255118.html

#### 20.4.1.3 https://de.aliexpress.com/item/32960744056.html

#### 20.4.1.4 https://de.aliexpress.com/item/32814705679.html

#### 20.4.1.5 https://de.aliexpress.com/item/4000666343805.html

#### 20.4.1.6 leider hat keine der Antennen aus China eine Beschreibung. Man muss sie kaufen und dann ausmessen. Oft sind es optisch gesehen zwei Wicklungen MW und FM vermutlich. SW haben sie idR vermutlich nicht

## 20.5 21.11.2020

### 20.5.1 der Drehko mit den drei zuschaltbaren Kondensatoren aus dem HB9LU Magnetic Loop Projekt eignet sich sehr gut, um die Res f eines bewickelten Toros einzustellen

#### 20.5.1.1 so gelernt, dass es erstens einen ca. 88-90 pF Kondensator braucht, um auf 14097 kHz zu kommen (C gemessen mit dem kleinen Gerät von Dani)

#### 20.5.1.2 gelernt, dass das SWR besser wird, wenn man sekundär Windungen wegnimmt, von 1:20 auf 1:12 brachte das SWR auf kleiner 1.5

#### 20.5.1.3 gelernt, dass man mit dem Abstand der sekundär Windungen und/oder der primär Windungen (nur 3) das SWR und die Res f leicht beeinflussen kann

#### 20.5.1.4 mit WSPRlite Flexi sendet auch diese munzig kleine 6 cm lange Antenne, aber sie ist um mehrere S-Stufen schlechter als die 20m Magnetic Loop von HB9LU

### 20.5.2 ein neues Kapitel öffnet sich: Digitally Tunable Capacitor

#### 20.5.2.1 DTC (digitally tunable capacitor)

##### 20.5.2.1.1 Bei den Kondensatoren unterscheidet man zwischen den verschiedenen Festkondensatoren und denen mit abstimmbarer Kapazität. Zu Letzteren gehören Drehkondensatoren, Trimmer, Kapazitätsdioden und digital abstimmbare Kondensatoren, Digitally Tunable Capacitors (DTC)

20.5.2.1.2 Digitally Tunable Capacitors sind in Chipform aufgebaute veränderbare Kondensatoren in CMOS- oder UltraCMOS-Technologie. Vom Aufbau her bestehen DCT-Kondensatoren aus mehreren MOS-Kondensatoren, die über MOSFETs zu- oder abgeschaltet werden. So können beispielsweise bei fünf Kondensatoren insgesamt 32 verschiedene Kapazitätswerte zu der vorhandenen Kapazität hinzugefügt werden. Liegt die Basiskapazität eines DTC-Kondensators bei 10 pF und haben die fünf Kondensatoren Kapazitäten von 1 pF, 2 pF, 4 pF, 8 pF und 16 pF, dann beträgt das Abstimmverhältnis 10 pF zu 41 pF, also 1:4,1. Durch Zu- und Abschalten kann jeder Wert zwischen 10 pF und 41 pF gewählt werden. Da DTC-Kondensatoren mit MOSFET-Schaltern arbeiten, haben sie einen hohen Gütefaktor, der 100 und mehr betragen kann

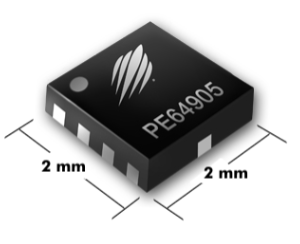
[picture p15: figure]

###### diese Dinger sind wirklich klein

###### Frequenzbereich min und max beachten

###### 100 MHz min

###### C min und C max beachten. Dies wird u.U. auch als Verhältnisfaktor ausgewiesen

###### die Preise sind sehr moderat, resp. klein

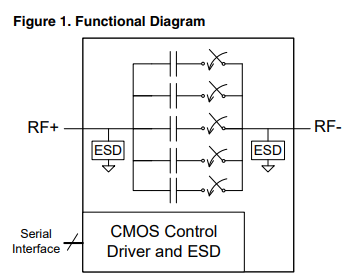
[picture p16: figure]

###### sehr interessant, aber vermutlich nichts für Martin

### 20.5.3 Martin selber wird im Moment für die weiteren Tests bei Scheiben-Kondensatoren sowie mit kleinen ca. 7-12 mm grossen Trimm-Kondensatoren bis max. 30 pF, welche noch mit zwei Fingern problemlos haltbar sind, vermutlich steckenbleiben

#### 20.5.3.1 Warum?

##### 20.5.3.1.1 in der SMD 805 Grösse?

###### SMD Trimm Capacitor Reichelt und Distrelec gesehen. Müsste man mal beschaffen und sehen wie gross die Stellschraube wirklich ist

###### die SMD Trimm Capacitor sind von den pF's her eher mit kleinen Werten ausgesattet. Auch das müsste man prüfen. Aber man könnte das mehrfach bestücken und mit Brücken arbeiten

# 21 Projektorganisation & Aufgaben

## 21.1 Projekt Organisation (PO)

Martin weiss am 01.12.2020 natürlich, dass man PO's idR anders darstellt. Aber auch hier gilt 'content over form' ... es geht für die Phase Proof of Concept auch so.

Im November 2020 haben 'nur' Daniel HB9GVD und Martin HB9GYF am Projekt gearbeitet.

Anfangs Dezember 2020 sind im Moment nur drei (3) Personen im engeren Kreis. Daniel HB9GVD, Mathias HB9FRV und Martin HB9GYF.

## 21.2 Aufgaben

Martin HB9GYF nimmt die Rolle Projekt Manager an sich und ist für die Dokumentation und das Projekt Repository verantwortlich. Im Moment auch die Aspekte über WSPRlite Flexi oder ICOM 705 Sender sowie eine Testantenne Magnetic Loop HB9AG oder andere kleine Testsendeantennen.

Daniel HB9GVD hat die technische Leitung für die Drohne, den SDR Empfänger, GPS Aspekte und Auswertung und im Moment insbesondere die Arduino Sourcen.

Mathias HB9FRV hilft partiell im Arduino Coding mit, damit wir den kostengünstigen und sehr, sehr leichten SDR Empfänger zum Laufen bringen. Er ist natürlich auch ein guter Reviewer der erarbeiteten Ergebnisse und kann mit seinen technischen Fähigkeiten unterstützen. Er hat auch immer gute und zu überprüfende Ideen sowie Hinterfragungen im Kopf.

# 22 Project Repository & Konzept

Wir möchten die Unterlagen in einem Github zentral ablegen. Die Arbeitskopien hat natürlich jeder Mitarbeiter selber auf seiner Arbeitsstation.

Wenn es vom Vorstand der HB9UF Gruppe bewilligt wird, würden wir gerne den Github von HB9UF benutzen.

Vorbehaltener Entschluss: Sollte dies nicht möglich sein oder erst etwas später, werden wir einen kleinen Github einrichten, welcher nur von den drei vielleicht mal vier Personen im Kernteam während dem Proof of Concept genutzt wird. Ein solcher Github, ich meine der kleinste, ist gratis und könnte ggfs. fürs erste genügen. Man könnte so z.B. auch die ersten Schritte lernen, sofern notwendig.

## 22.1 Rollen & Versionierung

Schon zum Anfang muss man sich Gedanken zu Rollen machen. Es sind dies aus der Sicht von Martin am 01.12.2020:

- Hithub Admin
- Hithub Projekt Admin
- Member
- Reviewer
- Projekt Viewer (Viewer für das Projekt)
- Viewer (die Unterlagen sind öffentlich sichtbar)

Wir arbeiten im Moment an der Version 1.1 und man merkt, dass eine Versionierung innerhalb des Projekts und auch bei den Dokumentationen und Sourcen, Compiler Scripts, usw. machen muss.

Die Rollen muss man pro Version steuern können. Warum? Wenn man in der Planungsphase von der Version 1.2 ist, möchte man dies nur im ganz kleinen Kreis tun und sich z.B. nicht von Viewers ablenken lassen.

Wir haben nun am 03.12.2020 unter der Leitung von Mathias auf das GitHub von HB9UF geschaltet. Dort ist alles privat und nur diejenigen Projektmitarbeiter, welche Mathias mit dem GitHub-Namen freischaltete, können das Projekt sehen und bearbeiten. Im Moment ist es am 03.12.2020 somit Mathias, Daniel und Martin.

Bei der Demo am 04.12.2020 merkten wir zusammen mit Mathias, dass das Wiki nur erscheint, wenn man 'public' ist. Auf 'privat' gibt es das nicht. Im Moment haben wir auf HB9UF also "nur" die Rolle Member. Ja, Martin meint, dass Mathias natürlich HitHub Admin ist.

### 22.1.1 Branch Strategie und erste Testergebnisse aus dem GitHub Testsystem

Von den zwei Varianten in GitHub, nämlich github flow oder gitflow, wählen wir den einfacheren, d.h. github flow. Wir haben somit nur zwei (2) branches, den master branch und den develop branch.

Am 03.12.2020 lernt Martin, als er Branch#1 create hat, dass es zwei branches hat. Da taucht noch ein default branch auf, welcher gegenüber Main ist. Der default branch wird auch base branch genannt. Man kann den default branch auch anders dirigieren/umlenken. Es soll aber grössere Auswirkungen innerhalb von GitHub haben. Daraufhin habe ich es wieder zurück geschaltet.

Den feature branch und den hotfix branch verwenden wir im Moment nicht. Den release branch ebenfalls nicht.

Als Martin das zweite Dokument in Branch#1 einstellte, war es hochgeladen sichtbar und dann führte ich einen Merge durch. Die beiden Dokumente wurden in GitHub im Main integriert. Es wurde sofort vorgeschlagen, dass man den Branch#1 nun löschen kann/soll. Martin überprüfte zuerst mit einem Download, dass die beiden Dokumente nun im Main sind. Anschliessend sah er, dass Branch#1 nun Merge ist, und gleich daneben hat es das Icon Korb, womit man den Branch#1 dann löschen kann.

An der HitHub Schulung von Mathias am 04.12.2020 legten wir folgende Branch Strategie fest.

1. Niemand darf so ohne weiteres in Main (vor ein paar Monaten hiess es Master) rein 'merge'. Dies bedarf immer einer Abstimmung und es somit generell verboten.

2. Aus Main wird nach jedem Release der Develop Branch aufgemacht. Es gibt dann daraus einen Develop-docs-martin Branch, einen Develop-source-dani und einen Develop-source-Mathias Branch.

3. Immer wenn ein Arbeitsergebnis fertig ist, wird in den Develop Branch 'merge'. Somit wird erreicht, dass alle Projektmitarbeiter jederzeit neue Funktionen oder z.T. Korrekturen ab dem Develop Branch laden können und so ohne Unterbruch weiter arbeiten können.

Wie eine Konsolidierung von verschiedenen Branches in Develop und dann anschliessend in Main aussieht, hat Martin auf dem Testsystem mal ausprobiert. Man kann das übersichtlich auf Insights/Network ansehen, siehe folgendes Bild. Auf dem Testsystem habe ich einfach mal zwei (2) Entwicklungs-Branches zum Test definiert.

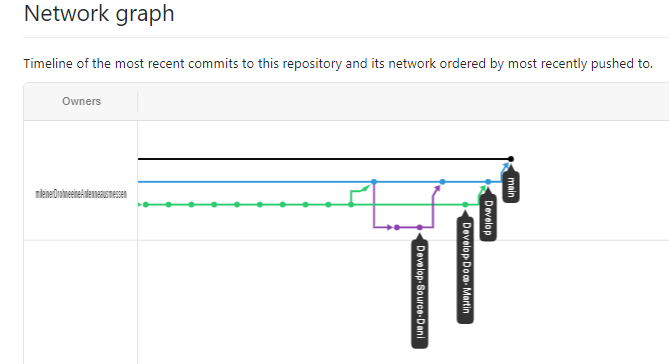
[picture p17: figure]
graphic

### 22.1.2 Umgebungen DEV/TE1/PROD

Im Moment haben wir zwei (2) DEV Umgebungen.

DEV1 bei Daniel unter Linux und ich nenne es mal eine irgendwie ähnlich C++ Sprache/Befehle für Arduino. Sowie den Arduino Ablauf Code nach der Ausführung des Compilers. Die ganz genaue Arduino Art von Daniel ist Martin am 03.12.2020 nicht bekannt.

DEV2 bei Mathias unter Linux und ich nenne es mal eine irgendwie ähnlich C++ Sprache/Befehle für Arduino. Diese ist dann gleich wie die DEV1. Auch hier den Ablauf Code nach der Ausführung des Compilers. Ob dieser in DEV2 gleich ist wie DEV1, ist Martin am 03.12.2020 nicht bekannt.

DEV3 werden wir zukünftig auch noch haben. Wann? Spätestens, wenn wir die Datensammlung für Empfangssignalpegel und GPS-Daten aufsetzen konnten, wird es ein Auswertungstool geben. Ob das auf Windows oder Linux läuft, ist im Dez 2020 noch völlig offen.

TE1 könnte später mal z.B. bei Martin oder Daniel sein. TE2 haben wir voraussichtlich nicht.

PROD ist dann unser erstes System mit dem wir Probeflüge durchführen.

Wenn wir ganz weit voraus denken, könnten es verschiedene PROD Systeme sein, die u.U nicht mal uns gehören, aber in denen Code von uns läuft. Und das noch in unterschiedlichen Versionen/Releases.

### 22.1.3 GitHub Rollen, welche Martin bis und mit 09.12.2020 lernte

#### 22.1.3.1 Sponsor

#### 22.1.3.2 Contributor

#### 22.1.3.3 Maintainer

#### 22.1.3.4 Member

#### 22.1.3.5 Viewer

#### 22.1.3.6 Warum ist das wichtig?

##### 22.1.3.6.1 Man muss das Konzept, welches man selber will, mit dem von GitHub abstimmen. Oder anders gesagt, wenn man sich Rollen vorstellt, welche es in GitHub nicht gibt, ist halt Pause

### 22.1.4 GitHub Ausführungen, welche Martin bis und mit 09.12.2020 kennenlernte

#### 22.1.4.1 Free

##### 22.1.4.1.1 Gratis GitHub, muss aber public sein

#### 22.1.4.2 Pro

##### 22.1.4.2.1 nur noch davon gelesen, aber in der Preisliste nicht mehr gefunden

#### 22.1.4.3 Team

#### 22.1.4.4 Enterprise

#### 22.1.4.5 GitHub One

#### 22.1.4.6 Martin weiss am 09.12.2020 nicht, welche Variante das HB9UF Repository ist/hat

#### 22.1.4.7 am 10.12.2020 im GitHub Testsystem gemerkt, dass dort der Hersteller z.T. auch neue Funktionen ausprobiert. Der Menue-Punkt "Discussions" ist einer davon

## 22.2 Dokumentation

### 22.2.1 Übersicht gesamt

Application/Product Management ist im Moment die Sicht. Es ist aber etwas zuviel des Guten. Wir sind in der Proof of Concept Phase und das Ergebnis kann auch begraben werden, aber ja diese Sicht darfman eigentlich nie ganz aus dem Auge verlieren. Aber mit dieser ad hoc Dokumentation machen wir eigentlich schon recht viel.

#### 22.2.1.1 Im README kann man im Projekt jederzeit und ganz leicht einen kurzen Überblick geben

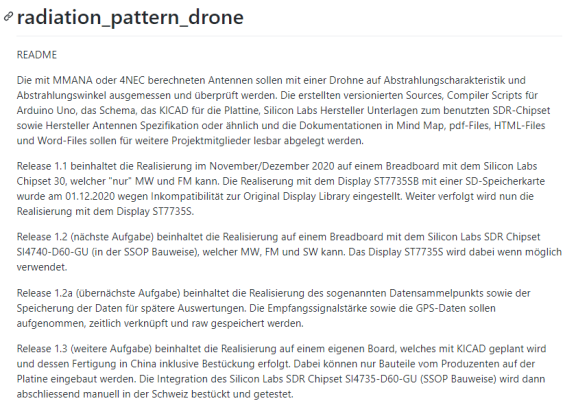
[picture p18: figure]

### 22.2.2 Übersichtsschema SDR Empfänger

AM 02.12.2020 von dem Proof of Concept abgelegt, resp. die original Ausgabe von Xhackster.

### 22.2.3 Projektdokumentation

#### 22.2.3.1 Mindmap, HTML, Word, pdf

#### 22.2.3.2 wichtige Besprechungen & Entscheide

### 22.2.4 Source Code SDR Empfänger

#### 22.2.4.1 Version 1.0 von Xhackster

Achtung es rauschen auch hier schon einige Versionen im Feld herum. Und ein Hithub oder so liegt hier z.Zt. noch nicht vor.

#### 22.2.4.2 Version 1.1

##### 22.2.4.2.1 Proof of Concept

#### 22.2.4.3 Version 1.2

#### 22.2.4.4 Version 1.2a

#### 22.2.4.5 Version 1.3

### 22.2.5 Libraries

### 22.2.6 Compiler & Prozeduren

### 22.2.7 Platinen & weitere Unterlagen

#### 22.2.7.1 PCB

#### 22.2.7.2 Besteller in China

### 22.2.8 Test Equipment

### 22.2.9 Wiki

### 22.2.10 Ticketsystem

#### 22.2.10.1 Das Ticketsystem funktioniert in GitHub mit sogenannten Issues. Die Issues kann man einem Bearbeiter zuweisen

##### 22.2.10.1.1 wie es Viewer benutzen können, weiss Martin am 09.12.2020 nicht. Im Moment nur so verstanden, dass die Projektteilnehmer es nutzen können

##### 22.2.10.1.2 irgendwie scheinen die Issues noch mit dem Kanban Projekt zusammen geführt werden zu können. Aufgefallen ist mir das am 09.12.2020, als ich bei einer Kanban Karten ein # Zeichen benutzte und es eine Issue Nummer anziehen wollte. Noch mehr ausprobieren

Siehe auch: Wenn man den Titel eines Issues mit der # Nummer anzieht, wird es in z.B. To do reingezogen und man kann mit Edit den Punkt anpassen oder man die Question einfach mal so stehen lassen, bis sich jemand die Aufgabe "schnappt"

##### 22.2.10.1.3 Wenn man den Titel eines Issues mit der # Nummer anzieht, wird es in z.B. To do reingezogen und man kann mit Edit den Punkt anpassen oder man die Question einfach mal so stehen lassen, bis sich jemand die Aufgabe "schnappt"

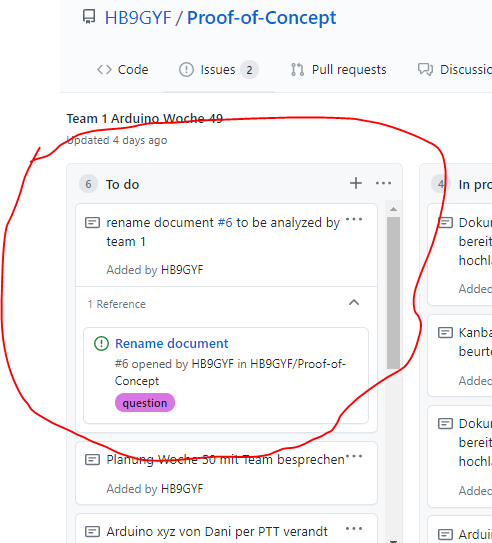
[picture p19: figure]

### 22.2.11 Dokumentation von Herstellern

#### 22.2.11.1 zu SIxxxx

### 22.2.12 Linksammlung

#### 22.2.12.1 eigene

#### 22.2.12.2 auf externe Seiten & Unterlagen

### 22.2.13 Ausbildung

#### 22.2.13.1 Arduino

## 22.3 Einführung GitHub als Version Control System (VCM)

Eine erste Kurzbeschreibung kann man aus dem Wiki entnehmen. Diese Informationen wiederhole ich hier nicht. Eine andere auf Deutsch zusammengefasste Kurzbeschreibung ist auf t3n.de zu entnehmen.

Git: Versionsverwaltung für Software-Projekte

Sinn und Funktion von GitHub stecken schon im zweiteiligen Namen: Git ist nämlich auch der Name einer Software zur Versionsverwaltung. Und was ist das schon wieder? Ganz einfach: An einem Software-Projekt arbeiten heutzutage oftmals mehrere, teilweise sogar Hunderte oder Tausende Entwickler mit. Von denen widmet sich jeder einem anderen Teil des Programms, und deren Arbeitsergebnisse müssen irgendwo zusammengeführt werden. Natürlich könnte jeder Entwickler seine Änderungen und Neuerungen an eine zentrale Person schicken, und diese kümmert sich dann ausschließlich darum, den erhaltenen Code immer zu aktualisieren. Genau diese Tätigkeit lässt sich aber mithilfe einer Versionsverwaltung wie Git automatisieren. Und weil das so praktisch ist und gut funktioniert, finden sich inzwischen viele bekannte Open-Source-Projekte auf GitHub wieder (zum Beispiel der Linux-Kernel, das Web-App-Framework Ruby on Rails oder die JavaScript-Bibliothek jQuery).

Die Beschreibung geht noch weiter, man kann es hoffentlich auch noch in ein paar Monaten dort nachlesen.

### 22.3.1 zu allererst muss man sich bezüglich Dokumentation von Git und GitHub sowie GitHub Desktop wie bei jedem neuen Programm im Klaren sein. Nur was in der Benutzeroberfläche und an Funktionen eingebaut ist, kann man als Benutzer auch nutzen

Vorstellungen im Kopf des Benutzers aus Erfahrungen mit anderen Programmen und Systemen können dabei enorm verwirren, für falsche Annahmen sorgen und ... mehr dazu könnte man in einem kleinen Buch schreiben. Aber ich höre jetzt auf ...

### 22.3.2 dieses Video von 1h ist vermutlich das Beste

#### 22.3.2.1 https://www.youtube.com/watch?v=8JJ101D3knE

Siehe Dokument(e): Git Tutorial for Beginners: Learn Git in 1 Hour - YouTube (https://www.youtube.com/watch?v=8JJ101D3knE)

Dieses Video muss vermutlich Daniel wirklich im Detail ansehen und verstehen.

#### 22.3.2.2 Wer wirklich GitHub Profi werden will, muss noch die nachfolgenden ca. 5h Schulung durchmachen

##### 22.3.2.2.1 aus den Erkenntnissen bis und mit 10.12.2020 genügt das nicht. Es braucht noch längere Schulung und vorallem Praxis

### 22.3.3 Version Control System (VCM) kann

#### 22.3.3.1 Track History

#### 22.3.3.2 Work Together

#### 22.3.3.3 public

#### 22.3.3.4 private

### 22.3.4 central repository like Subversion

#### 22.3.4.1 single point of failure (SPOF) und alle warten bis das System wieder oben ist

#### 22.3.4.2 auch Subversion kann einen dezentralen Betrieb. Es wird mit sogenannten SVN (Subversion Number) synchronisiert oder so ähnlich

22.3.4.3 Wo muss man mit dem Naming noch aufpassen? Die Fans von u.a. Tortoise sprechen ,wenn die das zentrale System meinen, oft auch vom Remote System. Und ja, es ist natürlich die Sichtweise. Aber man kann es drehen und wenden wie man will. Der Lead hat halt das System wo das GitHub Desktop zugreift

### 22.3.5 decentral repository like GitHub

#### 22.3.5.1 alle Entwickler können weiter arbeiten und Daten/Sourcen, usw. miteinander austauschen

#### 22.3.5.2 bedient im command line Modus

#### 22.3.5.3 bedient mit GUI's like Git Kraken oder Sourcetree

### 22.3.6 verteilte Verarbeitung

#### 22.3.6.1 es können auch, wenn das GitHub Desktop ausgefallen oder nicht erreichbar ist, die decentral repository miteinander arbeiten und sich so abstimmen

#### 22.3.6.2 das müsste man aber dann noch im Detail ausprobieren und im Projektteam festlegen

22.3.6.3 Projektregel: Wir fahren mit dem zentralen GitHub System und wer will kann sich dort immer das aktuelle Repository abziehen und dann auf dem eigenen Laptop/System weiter arbeiten. Bei jedem grössen Schritt muss der Projektmitarbeiter ins Develop synchronisieren. Nur wenn wir , d.h. alle eProjektmitarbeiter inverstanden sind, wird ins Main eingespielt

### 22.3.7 Martin hat zwar Git 2.29.2(2).64-bit.exe auf Windows installiert, (dezentral), wird aber das 'command line' Tool sicher nicht benutzen und deshalb bei dem Web-basierten GitHub bleiben

http://git-scm.com/download/win

Es gibt die Möglichkeit von der command line oder ein GUI, Git Kraken ist eines davon. geht für alle Plattformen. Aber, da muss man eine Fee zahlen. Open Source ist Sourcetree und geht aber nur für Windows und MAc.

In Windows kann man unten links cmd eingeben und man bekommt das Fenster. Die Kommandos sind nicht abschliessend.

Git Bash scheint das installierte Programm auf Windows zu heissen.

git --version

git config --global user.name xxxxx

git config --global user.email xxxxx

core editor muss auch konfiguriert werden, und es könnte folgendes sein

git config --global core.editor sein

im core.autocrlf muss man bei Windows ein true -e eingeben. Bei Mac ein Input.

Es scheint um das sogenannte end of line signal zu gehen abc\r\n (hier bin ich mit der Schreibweise nicht mehr sicher).

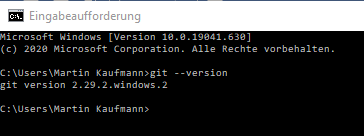
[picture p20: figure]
graphic

### 22.3.8 Erkenntnisse

Erst in der Nacht kommen die Erfahrungen von 10 Jahren bei UBS zur ganzen Thematik wieder in den Sinn und ich kann Git Hub nun wesentlich besser einfügen. Ich weiss es wäre ein kleines Buch. Die weiteren paar kurzen Worte sind nur damit ich mich erinnere ...

Alles was älter als 10 Jahre zum Thema ist, lasse ich im Moment sein. Requirements Management über proTrace, OCRWeb, RTM und das neuste ist im Moment nicht im Kopf. Filesysteme wie File, ShareDrive. Repositories wie Project Repository, Program Repository und Product Repository in DocWeb. Development in Subversion. Release Planung. Vorgehensmodelle wie ERL, RUP/EUP ... die neueren habe ich im Moment aus dem Kopf verloren ... ich müsste nun mein Übergabedokument an die Nachfolger einsehen. Aber ... lassen wir es dabei. Ich meine, ich kann nun Git Hub in diesen Systemen und Vorgehensmodellen richtig einordnen.

Am 03.12.2020 kommen neue Erkenntnisse dazu, als Martin in GitHub mehrere Releases öffnet und die nicht sichtbar sind. Die Denkesweise, dass GitHub bezüglich Releases gleich funktioniert wie RTM, ist komplett falsch. Ich muss es zuerst noch auf GitHub Test Umgebung ausprobieren. Aber es geht vermutlich nur über zuerst create branch und dann ein pull request zu einem Release. Kommt Zeit kommt Rat, aber es ist der gleich grosse Unterschied wie zwischen RTM und Subversion. Plattform Management wie in OCRWeb mal ganz ausser Betracht gelassen, in Zusammenhang mit GitHub.

### 22.3.9 out of github scope

#### 22.3.9.1 build process

#### 22.3.9.2 vendor management

##### 22.3.9.2.1 one vendor

###### Silicon Lab

##### 22.3.9.2.2 multiple vendor

#### 22.3.9.3 gitversion

#### 22.3.9.4 gitreleasemanger

### 22.3.10 Unterlagen, Ausbildung & Dokumentation zu GitHub

#### 22.3.10.1 Git Cheat Sheet

##### 22.3.10.1.1 alle line commands für Developer

#### 22.3.10.2 Tutorial GitHub

Siehe Dokument(e): Git Tutorial for Beginners: Learn Git in 1 Hour - YouTube (https://www.youtube.com/watch?v=8JJ101D3knE)

#### 22.3.10.3 Im Testsystem die erstellen zwei Develop Branches von Dani und Martin erfolgreich 'merged' in Develop und dann noch in Main eingefügt. Man kann das in Insights/Network gut verfolgen

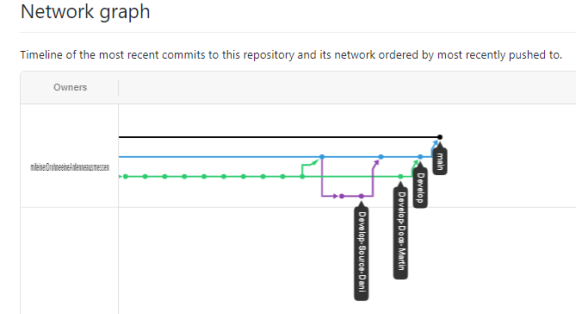
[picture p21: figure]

#### 22.3.10.4 07.12.2020

##### 22.3.10.4.1 Martin lernt etwas wieder, was er vor vielen Jahren mit den Developern von UBS diskutiert und getestet hat

Wir alle kennen es wie es ist, wenn alle auf ihren locals arbeiten ...

Wir haben dann ja alle schon lange ShareDrive eingesetzt gehbt, und gemerkt wie der eine am anderen alles überklatschen kann ...

Dann haben wir deshalb SharePoint eingesetzt und mit Check-out und Check-in gearbeitet. Mit oder ohne Versionierung, mit oder ohne Kommentar beim Check-in ...

SharePoint ist kein Archiv ...

Dazu das wirkliche Archivsystem Docweb, mit Baselines für Project-, Program- , Produkt-Ablagen. Für Organisations- und Mgmt-Ablagen, alles öffentlich oder versteckt. Martin liebt die Baselines von Docweb.

Die Developer-Kollegen hatten zeitgleich mit SharePoint auf Subversion gewechselt und hatten Erfolg für Sourcen, weil der Subversion-Check Zeile für Zeile durchgeführt wird. Mit Spezifikationen hatten sie Pech, das ging in Subversion nicht. Die haben wir dann in die Projekt-Ablage auf dem Docweb gelegt und jeweils in die Baseline von der TE2, kurz vor PROD, gelegt.

Martin scheint am 07.12.2020 zu begreifen, dass er mit den Dokumentationen in GitHub Desktop das gleiche Problem hat. Seine Dateien in z.B. als .docx Dateien scheinen alles zu "überklatschen". Es wird kein Conflict festgestellt. Es wäre also so wie zu ShareDrive Zeiten ... leider ...

Ob dies in Turtoise GUI anders wäre, entzieht sich per 07.12.2020. Einen Test muss ich auf dem Test GitHub Desktop noch machen und dabei zwei Branches verwenden.

###### Test auf Test GitHub Desktop mit zwei Branches und .docx Dateien, verantwortlich Martin

#### 22.3.10.5 09.12.2020

##### 22.3.10.5.1 in GitHub Beta wird neu von Head Branch und Base Branch unterschieden. Was ist das? Auch sind hier die für mich neuen Begriffe squash merging & rebase merging aufgeführt. Was ist das?

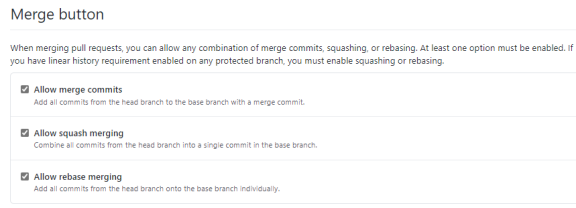
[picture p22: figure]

### 22.3.11 Unterlagen, Ausbildung & Dokumentation zu Sourcetree (open source)

#### 22.3.11.1 bei der Schulung wird das GUI vorgestellt

#### 22.3.11.2 Der Benutzer arbeitet gar nicht im Command Line Interface (CLI)

#### 22.3.11.3 Martin gefällt das Arbeiten mit GUI's und wird sicher nicht im Command Line Modus arbeiten

#### 22.3.11.4 in diesem zweiten Video erkennt man, dass sich das Arbeiten mit GitHub eignen, wenn man mit mehreren Personen in der "gleichen" Source arbeitet. Auch dann muss man sich absprechen, wer wo in der Source arbeitet, aber GitHub deckt auf, wenn die gleichen Zeilen verändert werden

##### 22.3.11.4.1 Link 1

Siehe Dokument(e): #1 Einfach GIT nutzen mit SourceTree ohne die böse Console! [Tutorial] - YouTube (https://www.youtube.com/watch?v=EfU4o7U_xAk)

##### 22.3.11.4.2 Link 2

Siehe Dokument(e): #2 Mit #GIT im Team arbeiten einfacher als man denkt! Git Tutorial! [Tutorial] - YouTube (https://www.youtube.com/watch?v=7rplh8J0nPI)

### 22.3.12 Unterlagen, Ausbildung & Dokumentation zu Tortoise GUI (ebenfalls open source)

#### 22.3.12.1 Mathias verwendet dieses Tool und wir "sollten" es deshalb auch verwenden

22.3.12.2 Martin als Fan von GitHub Desktop merkte, dass folgender Fall u.U. "verherend" sein kann. Wenn man als Benutzer nicht merkt, dass man im falschen Branch ist, dann geht es schnell schief. Martin hat im Testsystem dann mal schnell etwas in Develop rein 'merge', d.h. in den falschen Branch, und das wurde dann in den Main reingeschoben ???? Man muss als Bearbeiter in HitHub Desktop höllisch aufpassen was man macht. Würde man ein Remote GUI benutzen, passiert dieser Fehler m.E. nicht. Einfach auf dem Desktop GUI retour fahren wie im Remote GUI ist nicht einfach möglich. Man sieht so dann wirklich alle Fehler! Ja, so soll es auch sein

#### 22.3.12.3 10.12.2020 zwei Statements zu Tortoise

##### 22.3.12.3.1 Martin lernte in einem Telefongespräch mit Dani, dass er für seine Arbeiten Tortoise voraussichtlich nicht benutzen wird. Er kann relativ gut mit GitHub Desktop arbeiten

##### 22.3.12.3.2 Martin merkte auch, dass er alle Arbeiten in GitHub Desktop ausführen kann, ausser die Funktion Insights/Network ... das Projekt ist z.Zt. auf 'private' gestellt. Man müsste es auf 'public' stellen.

###### mit Mathias dies bei Gelegenheit besprechen

# 23 Abkürzungen Abbriviations

## 23.1 BOM order ist die Bauteileliste

# 24 Alternative, wenn der SDR Chip SI4734-D60-GU nicht geht

## 24.1 Es gibt von Elektra SDR Shield einen Bausatz für 45 Euro mit Arduino

## 24.2 Auch bei Shop Box 73 gibt es den gleichen

## 24.3 Beide sind am 10.12.2020 nicht verfügbar

# 25 Datenmodell

## 25.1 Martin hat am 11.12.2020 ein Datenmodell erstellt, resp. einen Vorstufe davon und eine Diskussion beantragt. Die Unterlagen decken die folgenden Bereiche ab

### 25.1.1 Datenmodell Phase Messung

### 25.1.2 Datenmodell Phase Flugplanung

### 25.1.3 Datenmodell Phase Auswertung

## 25.2 Das Datenmodell deckt eindeutig im Moment "nur" das Proof of Concept ab

# 26 Markante Projektänderung bezüglich der Lösungsidee

19.12.2020 Seite 11 von 77 Anforderungskatalog Mit einer Drohne eine Antenne ausmessen 20201205 20201205

Mit einer Drohne eine Antenne ausmessen

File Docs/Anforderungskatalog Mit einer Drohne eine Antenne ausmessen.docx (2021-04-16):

# Anforderungskatalog & Proof of Concept "Mit einer Drohne eine Antenne ausmessen" Motto: content over form 16.04.2021

# 1 Einleitung

Man kann eine Antenne mit MMANA oder 4NEC2, usw. berechnen. Wenn man sie einerseits baut und andererseits aufstellt, weiss man nicht wie die Abstrahlungscharakteristik und der Abstrahlungswinkel wirklich ist. Welchen Einfluss hat u.a. die Umgebung?

Zur Schreibweise und Definition sind es zum Teil Anforderungen (ANF) zum Thema. Welche sich in Business Use Cases (BUC's) und [System] Use Cases (UC's) unterteilen.

## 1.1 Anforderungen (ANF) sind unterteilt in

### 1.1.1 Business Use Cases (BUC's)

Anforderungen vom Benutzer, was er braucht um den Business Use Case "Antennen mit einer Drohne ausmessen" benötigt/braucht

### 1.1.2 [System] Use Cases (UC's)

System Use Cases werden im Weiteren nur als Use Cases (UVC's) beschrieben und das sind Anforderungen an die Technik und/oder Drohne, welche erfüllt sein sollten, damit man schlussendlich einen oder mehrere BUC's durchführen kann.

Wenn Sie das Dokument durchlesen, werden sie leicht merken um was es dabei geht.

## 1.2 Testfälle für BUC's oder UC's werden als Test Cases (TC's) bezeichnet
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

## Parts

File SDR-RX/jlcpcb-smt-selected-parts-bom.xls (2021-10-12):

Comment | Designator | Package | LCSC Part
68nF | C8 | Capacitor_SMD:C_0603_1608Metric_Pad1.08x0.95mm_HandSolder | C31658
10uF | C1,C6,C12,C13 | Capacitor_SMD:C_1206_3216Metric_Pad1.33x1.80mm_HandSolder | C13585
3V3 J5/J2 | PROG-VIN1 | Button_Switch_SMD:SW_SPDT_CK-JS102011SAQN | C160876
22pF | C4,C7 | Capacitor_SMD:C_0603_1608Metric_Pad1.08x0.95mm_HandSolder | C1653
33nF | C3 | Capacitor_SMD:C_0603_1608Metric_Pad1.08x0.95mm_HandSolder | C21117
LD1117S33TR_SOT223 | U3 | Package_TO_SOT_SMD:SOT-223-3_TabPin2 | C23984
SM4007 | D4,D1 | Diode_SMD:D_SOD-123F | C64898
470nH | L1 | Inductor_SMD:L_0603_1608Metric_Pad1.05x0.95mm_HandSolder | C1034
ESP32-WROOM-32 | U2 | RF_Module:ESP32-WROOM-32 | C82899
S8050 | Q1,Q2 | Package_TO_SOT_SMD:SOT-23_Handsoldering | C2146
Fuse_1A | F1 | Fuse:Fuse_1206_3216Metric_Pad1.42x1.75mm_HandSolder | C182308
100nF | C2,C5,C9 | Capacitor_SMD:C_0603_1608Metric_Pad1.08x0.95mm_HandSolder | C14663
32.768kHz | Y1 | Crystal:Crystal_SMD_3215-2Pin_3.2x1.5mm | C32346
GPS | GPS1 | Connector_JST:JST_SH_BM04B-SRSS-TB_1x04-1MP_P1.00mm_Vertical | C239522
10k | R1,R2,R3,R4,R5,R6 | Resistor_SMD:R_0603_1608Metric_Pad0.98x0.95mm_HandSolder | C25804
Reset ESP | RESET1 | Button_Switch_SMD:SW_SPST_B3SL-1002P | C318887
1k惟 @ 100MHz | FB1 | Inductor_SMD:L_1210_3225Metric_Pad1.42x2.65mm_HandSolder | C124093
18pF | C10 | Capacitor_SMD:C_0603_1608Metric_Pad1.08x0.95mm_HandSolder | C1647
470nF | C11 | Capacitor_SMD:C_0603_1608Metric_Pad1.08x0.95mm_HandSolder | C1623

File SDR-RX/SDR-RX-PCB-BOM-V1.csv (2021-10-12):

Reference | Quantity | Value | Footprint | Datasheet | LCSC Part #
C10 | 1 | 18pF | Capacitor_SMD:C_0603_1608Metric_Pad1.08x0.95mm_HandSolder | https://datasheet.lcsc.com/szlcsc/Samsung-Electro-Mechanics-CL10C180JB8NNNC_C1647.pdf | C1647
C11 | 1 | 470nF | Capacitor_SMD:C_0603_1608Metric_Pad1.08x0.95mm_HandSolder | https://datasheet.lcsc.com/szlcsc/Samsung-Electro-Mechanics-CL10B474KA8NNNC_C1623.pdf | C1623
C1 C6 C12 C13 | 4 | 10uF | Capacitor_SMD:C_1206_3216Metric_Pad1.33x1.80mm_HandSolder | https://datasheet.lcsc.com/szlcsc/Samsung-Electro-Mechanics-CL31A106KBHNNNE_C13585.pdf | C13585
C3 | 1 | 33nF | Capacitor_SMD:C_0603_1608Metric_Pad1.08x0.95mm_HandSolder | https://datasheet.lcsc.com/szlcsc/Samsung-Electro-Mechanics-CL10B333KB8NNNC_C21117.pdf | C21117
C4 C7 | 2 | 22pF | Capacitor_SMD:C_0603_1608Metric_Pad1.08x0.95mm_HandSolder | https://datasheet.lcsc.com/szlcsc/Samsung-Electro-Mechanics-CL10C220JB8NNNC_C1653.pdf | C1653
C8 | 1 | 68nF | Capacitor_SMD:C_0603_1608Metric_Pad1.08x0.95mm_HandSolder | https://datasheet.lcsc.com/szlcsc/Samsung-Electro-Mechanics-CL10B683KB8NNNC_C31658.pdf | C31658
C2 C5 C9 | 3 | 100nF | Capacitor_SMD:C_0603_1608Metric_Pad1.08x0.95mm_HandSolder | https://datasheet.lcsc.com/szlcsc/YAGEO-CC0603KRX7R9BB104_C14663.pdf | C14663
D1 | 1 | SM4007 | Diode_SMD:D_SOD-323F | https://datasheet.lcsc.com/lcsc/1809301215_MDD-Microdiode-Electronics-SM4007PL_C64898.pdf | C64898
D2 D3 | 2 | CM1213A-01SO | Package_TO_SOT_SMD:SOT-23 | http://www.onsemi.com/pub_link/Collateral/CM1213A-D.PDF
D4 | 1 | SM4007 | Diode_SMD:D_SOD-123F | https://datasheet.lcsc.com/lcsc/1809301215_MDD-Microdiode-Electronics-SM4007PL_C64898.pdf | C64898
F1 | 1 | Fuse_1A | Fuse:Fuse_1206_3216Metric_Pad1.42x1.75mm_HandSolder | https://datasheet.lcsc.com/lcsc/1808301741_Shenzhen-lanson-Elec-12H1100C_C182308.pdf | C182308
FB1 | 1 | 1kΩ @ 100MHz | Inductor_SMD:L_1210_3225Metric_Pad1.42x2.65mm_HandSolder | https://datasheet.lcsc.com/szlcsc/1811141410_FH-Guangdong-Fenghua-Advanced-Tech-CBG322513U102T_C124093.pdf | C124093
H1 H2 H3 H4 | 4 | MountingHole_Pad | MountingHole:MountingHole_2.7mm_Pad_Via | ~
J1 | 1 | Program | Connector_JST:JST_XH_S7B-XH-A-1_1x07_P2.50mm_Horizontal
J2 | 1 | Vin | Connector_JST:JST_XH_B2B-XH-A_1x02_P2.50mm_Vertical | ~
FM1 | 1 | FM Antenna | Connector_Coaxial:SMA_Samtec_SMA-J-P-X-ST-EM1_EdgeMount | ~
J4 | 1 | AM Antenna | Connector_Coaxial:SMB_Jack_Vertical | ~
J5 | 1 | Conn_01x03_Male | Connector_PinHeader_2.54mm:PinHeader_1x03_P2.54mm_Vertical | ~
GPS1 | 1 | GPS | Connector_JST:JST_SH_BM04B-SRSS-TB_1x04-1MP_P1.00mm_Vertical | https://datasheet.lcsc.com/szlcsc/2010160407_CJT-Changjiang-Connectors-A1002WR-S-4P_C239522.pdf | C239522
L1 | 1 | 470nH | Inductor_SMD:L_0603_1608Metric_Pad1.05x0.95mm_HandSolder | https://datasheet.lcsc.com/szlcsc/Sunlord-SDFL1608Q4R7KTF_C1034.pdf | C1034
Q1 Q2 | 2 | S8050 | Package_TO_SOT_SMD:SOT-23_Handsoldering | https://datasheet.lcsc.com/szlcsc/Changjiang-Electronics-Tech-CJ-S8050_C2146.pdf | C2146
R1 R2 R3 R4 R5 R6 | 6 | 10k | Resistor_SMD:R_0603_1608Metric_Pad0.98x0.95mm_HandSolder | https://datasheet.lcsc.com/szlcsc/Uniroyal-Elec-0603WAF1002T5E_C25804.pdf | C25804
Reset1 | 1 | Reset ESP | Button_Switch_SMD:SW_SPST_B3SL-1002P | https://datasheet.lcsc.com/szlcsc/XKB-TS-1187A-C-E-A_C318887.pdf | C318887
Prog-Vin1 | 1 | 3V3 J5/J2 | Button_Switch_SMD:SW_SPDT_CK-JS102011SAQN | https://datasheet.lcsc.com/szlcsc/1809041640_ALPSALPINE-SSSS710607_C160876.pdf | C160876
TP1 | 1 | Reset ESP | TestPoint:TestPoint_Pad_D1.5mm | ~
TP2 | 1 | Data | TestPoint:TestPoint_Pad_D1.5mm | ~
TP3 | 1 | Clock | TestPoint:TestPoint_Pad_D1.5mm | ~
TP4 | 1 | Reset SI4734 | TestPoint:TestPoint_Pad_D1.5mm | ~
TP5 | 1 | +3V3 | TestPoint:TestPoint_Pad_D1.5mm | ~
U1 | 1 | Si4734-D60-GU | Package_SO:SSOP-24_3.9x8.7mm_P0.635mm | http://www.silabs.com/Support%20Documents/TechnicalDocs/Si4730-31-34-35-D60.pdf
U2 | 1 | ESP32-WROOM-32 | RF_Module:ESP32-WROOM-32 | https://www.espressif.com/sites/default/files/documentation/esp32-wroom-32_datasheet_en.pdf | C82899
U3 | 1 | LD1117S33TR_SOT223 | Package_TO_SOT_SMD:SOT-223-3_TabPin2 | http://www.st.com/st-web-ui/static/active/en/resource/technical/document/datasheet/CD00000544.pdf | C23984
Y1 | 1 | 32.768kHz | Crystal:Crystal_SMD_3215-2Pin_3.2x1.5mm | https://datasheet.lcsc.com/szlcsc/1901081604_Seiko-Epson-Q13FC1350000400_C32346.pdf | C32346

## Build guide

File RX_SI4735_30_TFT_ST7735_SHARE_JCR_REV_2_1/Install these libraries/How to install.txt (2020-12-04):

Just copy all these libraries to you Documents/Arduino/libraries folder.

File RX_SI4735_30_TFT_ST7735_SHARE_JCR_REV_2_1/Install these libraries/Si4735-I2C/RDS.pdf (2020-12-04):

# Information on Radio Data System (RDS)

### Copyright 2012, 2013 Michael J. Kennedy

### May 13, 2013

This document is licensed under the Creative Commons Attribution-ShareAlike 3.0 Unported License. To
view a copy of this license, visit “http://creativecommons.org/licenses/by-sa/3.0/.”

## Background

Radio Data System (RDS) is a standard way of transmitting digital information over an FM analog audio broadcast channel. In the USA a slightly different standard called Radio Broadcast Data System (RBDS) is used. In this document any reference to RDS also applies to RBDS unless otherwise stated. See the Wikipedia page for RDS¹ (http://wikipedia.org/wiki/Radio_Data_System)
for additional information and very useful external links.

The RDS standard is given by IEC-62106:2009. The official version of this document may be purchased from IEC (International Electrotechnical Commission), however, an unofficial draft version is available for free from the RDS forum’s web site. With a little searching, you can also find the older 1999 official version for free on the internet.

RBDS is a combination of IEC-62106 and another document from the National Radio Systems Committee (NRSC) called NRSC-4-B, available for free from “http://www.nrscstandards.org.” The main differences between RBDS and RDS are different rules for PI and PTY codes.

A good book on RDS was published in 1999: "RDS: The Radio Data System" by Dietmar Kopitz and Bev Marks, ISBN 0-89006-744-9.

It is now common for traffic information to be sent over RDS using Group 8A, Traffic Message Channel (TMC) packets. TMC is described in ISO standard 14819 "Traffic and Traveler Information (TTI) — TTI messages via traffic message coding," with 4 parts:

ISO 14819-1:2003 Coding protocol for Radio Data System — Traffic Message Channel (RDS-TMC) using ALERT-C

ISO 14819-2:2003 Event and information codes for Radio Data System — Traffic Message Channel (RDS-TMC)

ISO 14819-3:2004 Location referencing for ALERT-C

ISO 14819-6:2006 Encryption and conditional access for the Radio Data System — Traffic Message Channel ALERT C coding

Before the ISO version was released, earlier versions of TMC were given by CEN standard ENV 12313. See the Wikipedia page for TMC² (http://wikipedia.org/wiki/Traffic_message_channel)
for more information.

1http://wikipedia.org/wiki/Radio_Data_System2http://wikipedia.org/wiki/Traffic_message_channel

## Data format

This document describes the data format once the signal has been decoded and error correcting codes have been applied. The data consists of a series of "packets" that RDS calls Groups. Each Group contains four Blocks named A through D. Each block contains 16 bits of data. All Groups have the following bit layout:

- Block A

16 PI (Program Identification) code that identifies the programming broadcast by the station.

- Block B

4 Group Type code.

### 1 Version code:

0 = A
1 = B

### 1 Traffic Program code:

0 = No Traffic Alerts
1 = Station gives Traffic Alerts

### 5 PTY (Program Type) code

5 Depends on Group Type and Version codes.

- Block C

16 Depends on Group Type and Version codes. Version A has data, version B usually has a duplicate PI also found in Block A.

- Block D

16 Depends on Group Type and Version codes.

The Group Type and Version codes indicate the format of Blocks C and D and the 5 low bits of Block B. In this document and the official documents, the Group Type code and Version code are combined. (Example: 4A.)

Block A always has the Program Identification (PI) code that uniquely identifies the programming broadcast by the station. Typically, a network of stations will share a PI code. This permits the radio to stay tuned to a network, instead of a station. Whenever a station becomes weak, the radio will automatically search for another stronger station with the same PI code. Some stations may switch between network and local programming. In this case, the station may switch to a different PI code while broadcasting local programming. This is usually done by changing the coverage area code inside the PI code.

In RDS, the PI code has the following bit layout:

4 Country code. Cannot be 0.

4 Coverage area code.

8 Assigned ID code. Cannot be 0.

While radio networks may still exist in Europe, Canada, and other areas, they no longer exist in the USA. (They were destroyed by competition from TV.) For many decades, each station has had a unique program format. There are nationally syndicated programs, but each program makes a separate broadcast deal with a station in each market. (In some cases, this can be over 600 stations.) Even when a company owns multiple stations across the country, they always have unique programming on each station.

Because there are no networks in the USA and there are many thousands of stations, the European PI codes found in RDS are inadequate to meet the needs of the USA. This caused the creation of the RBDS standard.

In RBDS, a formula is used to encode the station’s call sign into a PI code. (See the RBDS document for how this is done.) The encoding scheme used was designed to maintain compatibility with RDS, except that RBDS does not normally use coverage area codes.

Note: Occasionally, two USA local stations will broadcast identical programming. (This is called simulcasting.) This is done to increase the coverage area in rural areas. In this case, both stations become a mini network and should share the same PI code. The PI code used is based on the call sign of one of the stations.

The PI code was originally designed to meet the needs of Europe. Later, when RDS was spread to the rest of the world, the country code had to be expanded. Group Type 1A packets contain an 8 bit Extended Country Code (ECC). This permits having unique ID codes across the world. The European broadcasting area uses ECC E0 to E4.

According to RDS (IEC-62106:1999, which is out of date but freely available on the Internet), the USA uses ECC A0 with country codes 1-9, A, B, D, E. (Country codes C and F are unassigned for ECC A0.) Canada is assigned ECC A1 and country codes B, C, D, E. Mexico is assigned ECC A5 and country codes B, D, E, F. However, RBDS (NRSC-4-B:2011) says country code C is used by Canada and F by Mexico, but does not indicate what ECC is then used. RBDS also says country codes B, D, E are reserved for networks with coverage area codes and that they are coordinated with Canada and Mexico. When these country codes are used, the PI codes they form behave exactly as PI codes in RDS. The following table gives the allocation of country codes for RBDS:

Country | Coverage
code | area code | Usage
1-A | No | Call sign encoded PI (USA only)
B, D, E | Yes | NPR (USA) and CBC (Canada) networks
C | Yes | Canada
F | Yes | Mexico

Although RBDS reserves a few PI codes for the National Public Radio (NPR) network, it does not appear that these stations use their network PI codes because most (if not all) NPR stations have unique programming for each station.

It appears to this author, that RBDS ignores the ECC and has "reserved" country codes B-F for Canada and Mexico. This permits North American stations and receivers to ignore ECCs and to assume that country codes 1-A are RBDS and B-F are RDS.

There is one exception to the above rules permitted by RBDS. If a station is broadcasting Traffic Message Channel (TMC) groups (packets), it may set the high nibble to 0x1, regardless of the PI code it should normally use. Apparently, this tells TMC receivers that the station is located in North America.

The original intent of the PI code is to have a unique ID for each programming format to be used internally by the receiver. The user would never see this code. (Although some receivers now show it as a hexadecimal number.) However, because US codes are based on the station’s call sign, it is common for US receivers to display the station’s call sign, derived from the PI code.

The Program Type (PTY) code gives the type of programming found on the station. This code can change throughout the day if the Dynamic PTY flag is set (see below.) The codes chosen for RDS are fine for Europe but have limited value in the USA. For example, I doubt there is any station in the USA that would use the categories "Cultures," "Science," or "Documentary."

RBDS changes most PTY codes to values more useful for the USA. Examples include "Top 40," "Foreign Language," "Religious Music," "Religious Talk," "Spanish Music," "Spanish Talk," and "Hip Hop." It is unlikely that any of these would be used in Europe.

RDS text characters use custom character sets. However, the lower half of each set is basically ASCII. (See official documents for details.) Whenever a text character is received that the receiver does not understand, it should replace it with a space.

The following table gives the Group Types we will discuss in this document. Most other Group Types are for custom use or are reserved. (See official documents for info on the other Group Types.)

Type | Contents
0A/B | Basic information
1A | Additional information
2A/B | Radio Text
3A | Setup open data application
4A | Date and time
10A | Program Type Name
15B | Basic information

Group 0A/B — Basic tuning and switching information

- Block B (low 5 bits)

### 1 TA (Traffic announcement):

0 = No traffic announcements at this moment. Normal programming on audio channel. 1 = Traffic announcement currently being broadcast on audio channel.

### 1 MS (Music/Speech):

0 = Speech
1 = Music
1 Decoder-Identification control code. Contains a 1 bit segment of a four bit code.
2 Segment number for Program Service name and Decoder-Identification control code.
- Block C

16 Two alternate frequencies (version A) or duplicate PI (version B.) Some stations are part of a network of stations with common programming. This field gives the frequency of the neighboring stations in the network. See official documents for more info.

- Block D

8 Program Service name, first character in segment.
8 Program Service name, second character in segment.

The Program Service name is 8 characters that identifies the station with a name or slogan. However, most stations now use it to print a scrolling message that should be sent as a Radio Text message, despite the fact that this is prohibited by RDS. (Stations do this because most car radios do not display Radio Text messages.)

The Program Service name is broadcast in segments with each Group (packet) containing one segment. Each segment contains two characters. Therefore, the full name requires four segments.

The Decoder-Identification control code is a four bit code that provides miscellaneous info. Just as the Program Service name is divided into segments, so is the Decoder-Identification control code. Each group contains a 1 bit segment so four segments are required. The first segment (0) contains the most significant bit, the last segment (3) contains the least significant bit.

The following table shows the relationship between segment numbers and the Program Service name and Decoder-Identification control code:

Segment | PS characters | DI bit
0 | 1, 2 | 3 MSB
1 | 3, 4 | 2
2 | 5, 6 | 1
3 | 7, 8 | 0 LSB

The following table gives the meaning for each bit in the Decoder-Identification control code:

Segment | DI bit | Value and meaning
0 | 3 | 0 = Static PTY code
| | 1 = Dynamic PTY code
1 | 2 | 0 = Not compressed audio
| | 1 = Compressed audio
2 | 1 | 0 = Not artificial head
| | 1 = Artificial head (Binaural audio)
3 | 0 | 0 = Monophonic audio
| | 1 = Stereophonic audio

Group 1A — Program Item Number and slow labeling codes

- Block B (low 5 bits)

5 Radio Paging codes. See official documents.

- Block C

1 Link Actuator. See official documents.
3 Variant code. See below.
12 Data. See below.
- Block D

16 Program Item Number. See official documents.

The Variant code gives the data format for the 12 bit Data field. The following table gives the bit layouts for the Data field for the two most interesting Variants. (See official documents for other Variant codes.)

- Variant = 0

4 Paging. See official documents.
8 Extended Country Code (ECC). See description of PI codes above.
- Variant = 3

4 Reserved.

### 8 Language code. (Annex J says Language code is 8 bits.)

The most interesting Language codes are: (See IEC-62106 Annex J for other codes.)

Language
code | Meaning
0x00 | Unknown or not applicable
0x09 | English

Group 2A/B — Radio Text

- Block B (low 5 bits)

1 A/B flag. Toggles whenever a new message is started. 4 Segment number for Radio Text.

Version 2A:

- Block C

8 Radio Text, first character in segment.
8 Radio Text, second character in segment.
- Block D

8 Radio Text, third character in segment. 8 Radio Text, fourth character in segment.

Version 2B:

- Block C

### 16 Duplicate PI

- Block D

8 Radio Text, first character in segment.
8 Radio Text, second character in segment.

The Radio Text (RT) message is either 64 (Group 2A) or 32 (Group 2B) characters. It describes the current program being broadcast or provides other useful information like traffic reports. Radio Text is broadcast in segments with each Group (packet) containing one segment. There are 16 segments. Group 2A has four characters per segment. Group 2B has two characters per segment.

The following table shows the relationship between segment numbers and Radio Text:

Group 2A | Group 2B
Segment | RT characters | RT characters
0 | 1, 2, 3, 4 | 1, 2
1 | 5, 6, 7, 8 | 3, 4
15 | 61, 62, 63, 64 | 31, 32

Radio Text supports the following control characters:

Char | Name | Usage
0x0D | CR | Marks end of message
0x0A | LF | Optional line break
0x0B | End of headline
0x1F | Soft hyphen

The end of headline character may be placed anywhere within the first 32 character positions and indicates that the text up to that point is considered by the broadcaster to be the "headline" portion of the message. It is inserted by the broadcaster on the assumption that a 2 line by 16 character format has been adopted on the receiver. It may stand in place of a space character in the message.

The soft hyphen indicates the position(s) in long words where the author of the text would prefer a receiver to break a word between display lines if there is a need to do so. It has application only for multi-line non-scrolling displays.

The A/B flag is toggled whenever a new message is started. At this point the receiver should reset the Radio Text receive buffer. The A/B flag will maintain its current state while segments for the current message are broadcast repeatedly. Note that RDS permits stations to shorten the message by skipping segments at the end.

Group 3A — Application identification for open data

- Block B

4 Group Type code for ODA packet.

### 1 Version code for ODA packet:

0 = A
1 = B
- Block C

16 Message.

- Block D

### 16 Application Identification (AID)

RDS supports broadcasting custom protocols using undefined Groups Types (packets.) These packets are called Open Data Application (ODA) packets. To use an ODA packet, you must identify the custom protocol you are using and what Group Type and Version the protocol will be using. This is done by sending a Group 3A packet.

The Application Identification (AID) uniquely identifies which protocol is being used. Its value is assigned by the maintainers of the RDS and RBDS standards.

Some packet types can either be used for ODA or for a purpose defined by the RDS standard. For example, Groups 5A/B can be used for ODA or for Transparent Data Channels (TDC). If a broadcaster wants to use a packet for its default purpose, it sends a Group 3A packet with an AID of 0.

There is a 16 bit Message in Group 3A packets for custom information for each protocol.

Group 4A — Clock-time and date

- Block B (low 5 bits)

3 Unused.
2 Modified Julian Date (MJD) high bits.
- Block C

15 Modified Julian Date (MJD) low bits. 1 Hour high bit.

- Block D

4 Hour low bits.

### 6 Minute

### 1 Sign of Offset:

0 = Positive - Add offset to date/time.
1 = Negative - Subtract offset from date/time.
5 Offset to convert UTC to local time. Units in half hours.

If all date and time fields are set to zero then the packet is meaningless and should be ignored.

The date and time given are in UTC. The offset can be used to convert UTC to local date and time.

The date is given in Modified Julian Date (MJD) form. It represents the number of days since November 17, 1858. Officially, the date is supposed to be restricted to values up to 99999. However, the binary field can contain values up to 131071. I assume the official range will be increased once the current date reaches the current limit. I also suspect that most equipment already support dates up to 131071.

Hour is from 0 to 23. Minute is from 0 to 59.

The offset is an unsigned number. The sign flag indicates if the offset should be added to or subtracted from the date and time. The offset is given in half hour increments.

The following code fragment can be used to convert to local time:

unsigned long date_time; // combines date and time in units of minutes unsigned long MJD; // days since November 17, 1858
unsigned short hour, minute;
short offset;
bool sign;

// initialize MJD, hour, minute, offset, and sign with received RDS data ...
// combine date and time
date_time = MJD*24*60 + hour*60 + minute;
// adjust offset from units of half hours to minutes offset *= 30;
// determine sign of offset
if(sign) offset = -offset; // make negative
// compute local date/time
date_time += offset;
// break down date and time
minute = date_time%60;
date_time /= 60;
hour = date_time%24;
date_time /= 24;
MJD = date_time;

Group 10A — Program Type Name

- Block B (low 5 bits)

1 A/B flag. Toggles whenever a new message is started. 3 Unused.
1 Segment number for Program Type Name.
- Block C

8 Program Type Name, first character in segment. 8 Program Type Name, second character in segment.

- Block D

8 Program Type Name, third character in segment. 8 Program Type Name, fourth character in segment.

The Program Type Name (PTYN) is 8 characters that identifies the type of programming broadcast by the station. This is intended to supplement the Program Type (PTY) code which has only 32 possible values.

The Program Type Name is broadcast in segments with each Group (packet) containing one segment. Each segment contains four characters. Therefore, the full name requires two segments.

The following table shows the relationship between segment numbers and the Program Type Name:

Segment | PTYN characters
0 | 1, 2, 3, 4
1 | 5, 6, 7, 8

The A/B flag is toggled whenever a new name is started. At this point the receiver should reset the Program Type Name receive buffer. The A/B flag will maintain its current state while segments for the current name are broadcast repeatedly. Note that RDS permits stations to shorten the name by skipping the second segment.

Group 15B — Fast basic tuning and switching information

Blocks A and B have the same format as Group Type 0A/B. Block C is a duplicate of block A. Block D is a duplicate of block B.

This Group (packet) probably exists to improve the odds of receiving this basic information on a station with poor reception.

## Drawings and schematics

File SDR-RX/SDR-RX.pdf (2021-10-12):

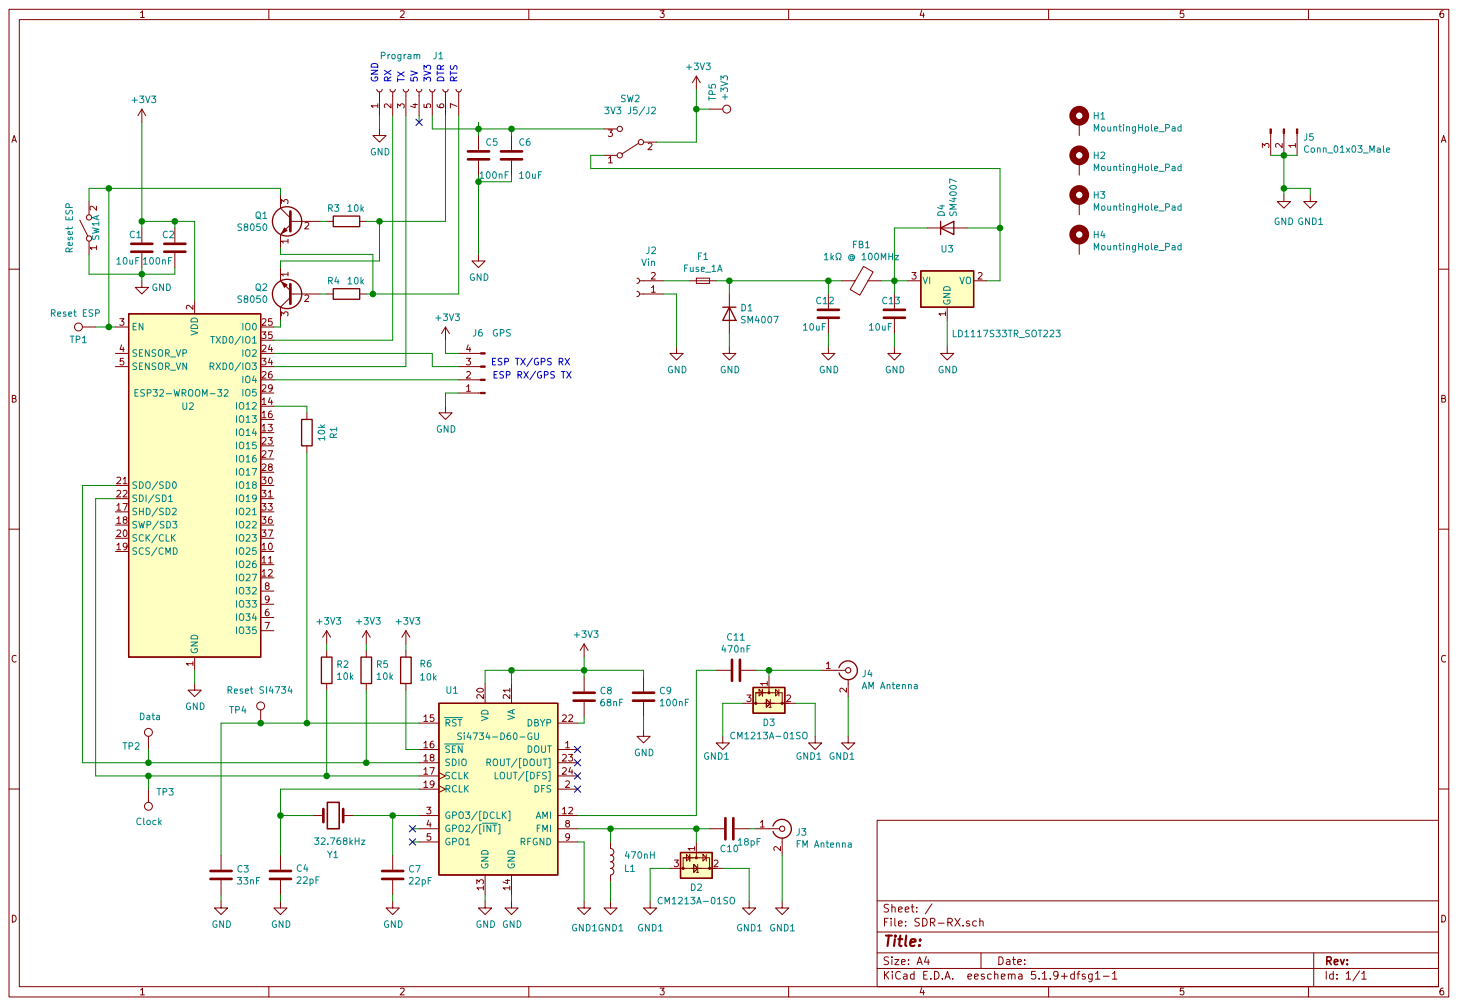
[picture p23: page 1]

1 2 SW1A Reset ESP GND GND GND

2 SCK/CLK 20 SDO/SD0 21 SDI/SD1 22

Id: 1/1 Title: File: SDR-RX.sch Sheet: / GND1

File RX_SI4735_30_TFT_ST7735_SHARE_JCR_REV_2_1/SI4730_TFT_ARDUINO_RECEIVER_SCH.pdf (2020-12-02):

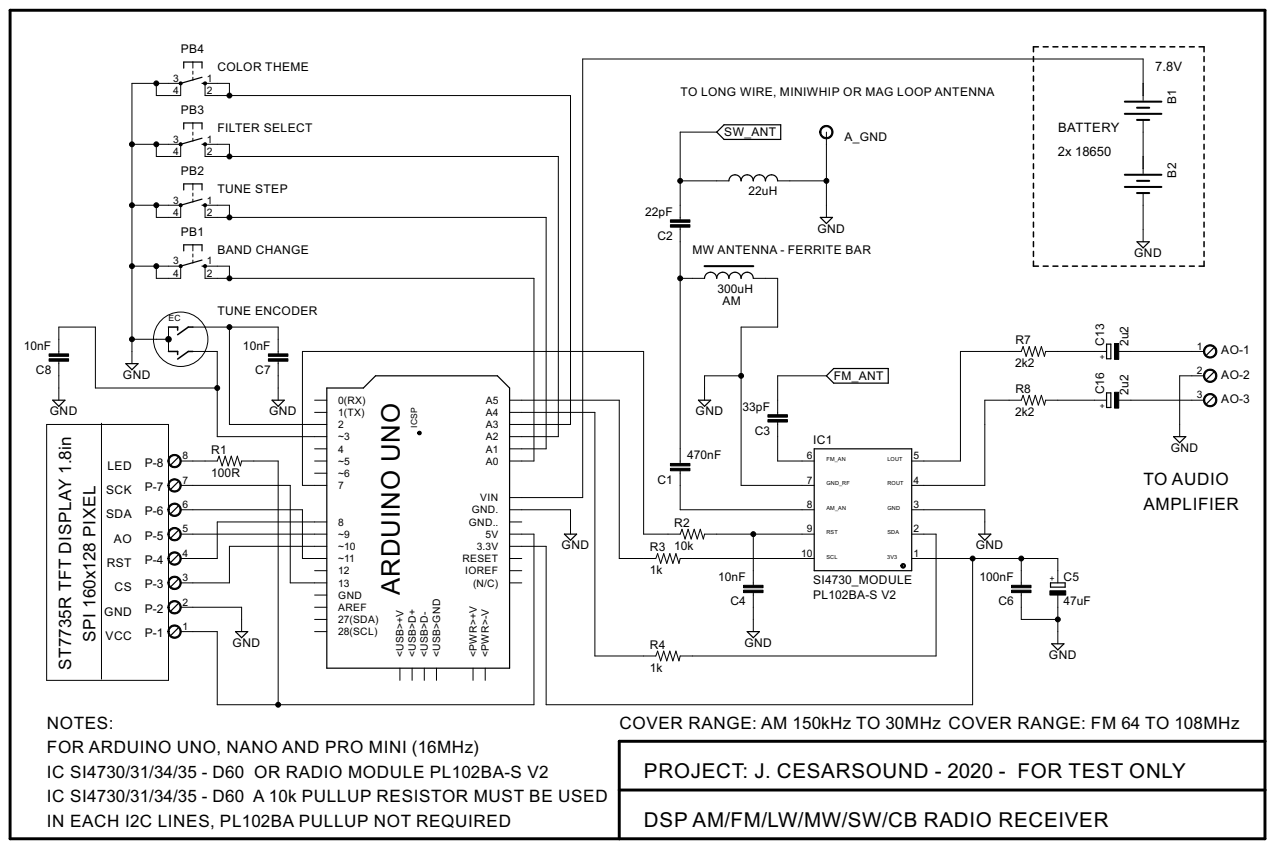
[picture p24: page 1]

TO LONG WIRE, MINIWHIP OR MAG LOOP ANTENNA

MW ANTENNA - FERRITE BAR

28(SCL) 27(SDA) AREF GND

NOTES:
FOR ARDUINO UNO, NANO AND PRO MINI (16MHz)
IC SI4730/31/34/35 - D60 OR RADIO MODULE PL102BA-S V2
IC SI4730/31/34/35 - D60 A 10k PULLUP RESISTOR MUST BE USED
IN EACH I2C LINES, PL102BA PULLUP NOT REQUIRED

COVER RANGE: AM 150kHz TO 30MHz COVER RANGE: FM 64 TO 108MHz

PROJECT: J. CESARSOUND - 2020 - FOR TEST ONLY

DSP AM/FM/LW/MW/SW/CB RADIO RECEIVER

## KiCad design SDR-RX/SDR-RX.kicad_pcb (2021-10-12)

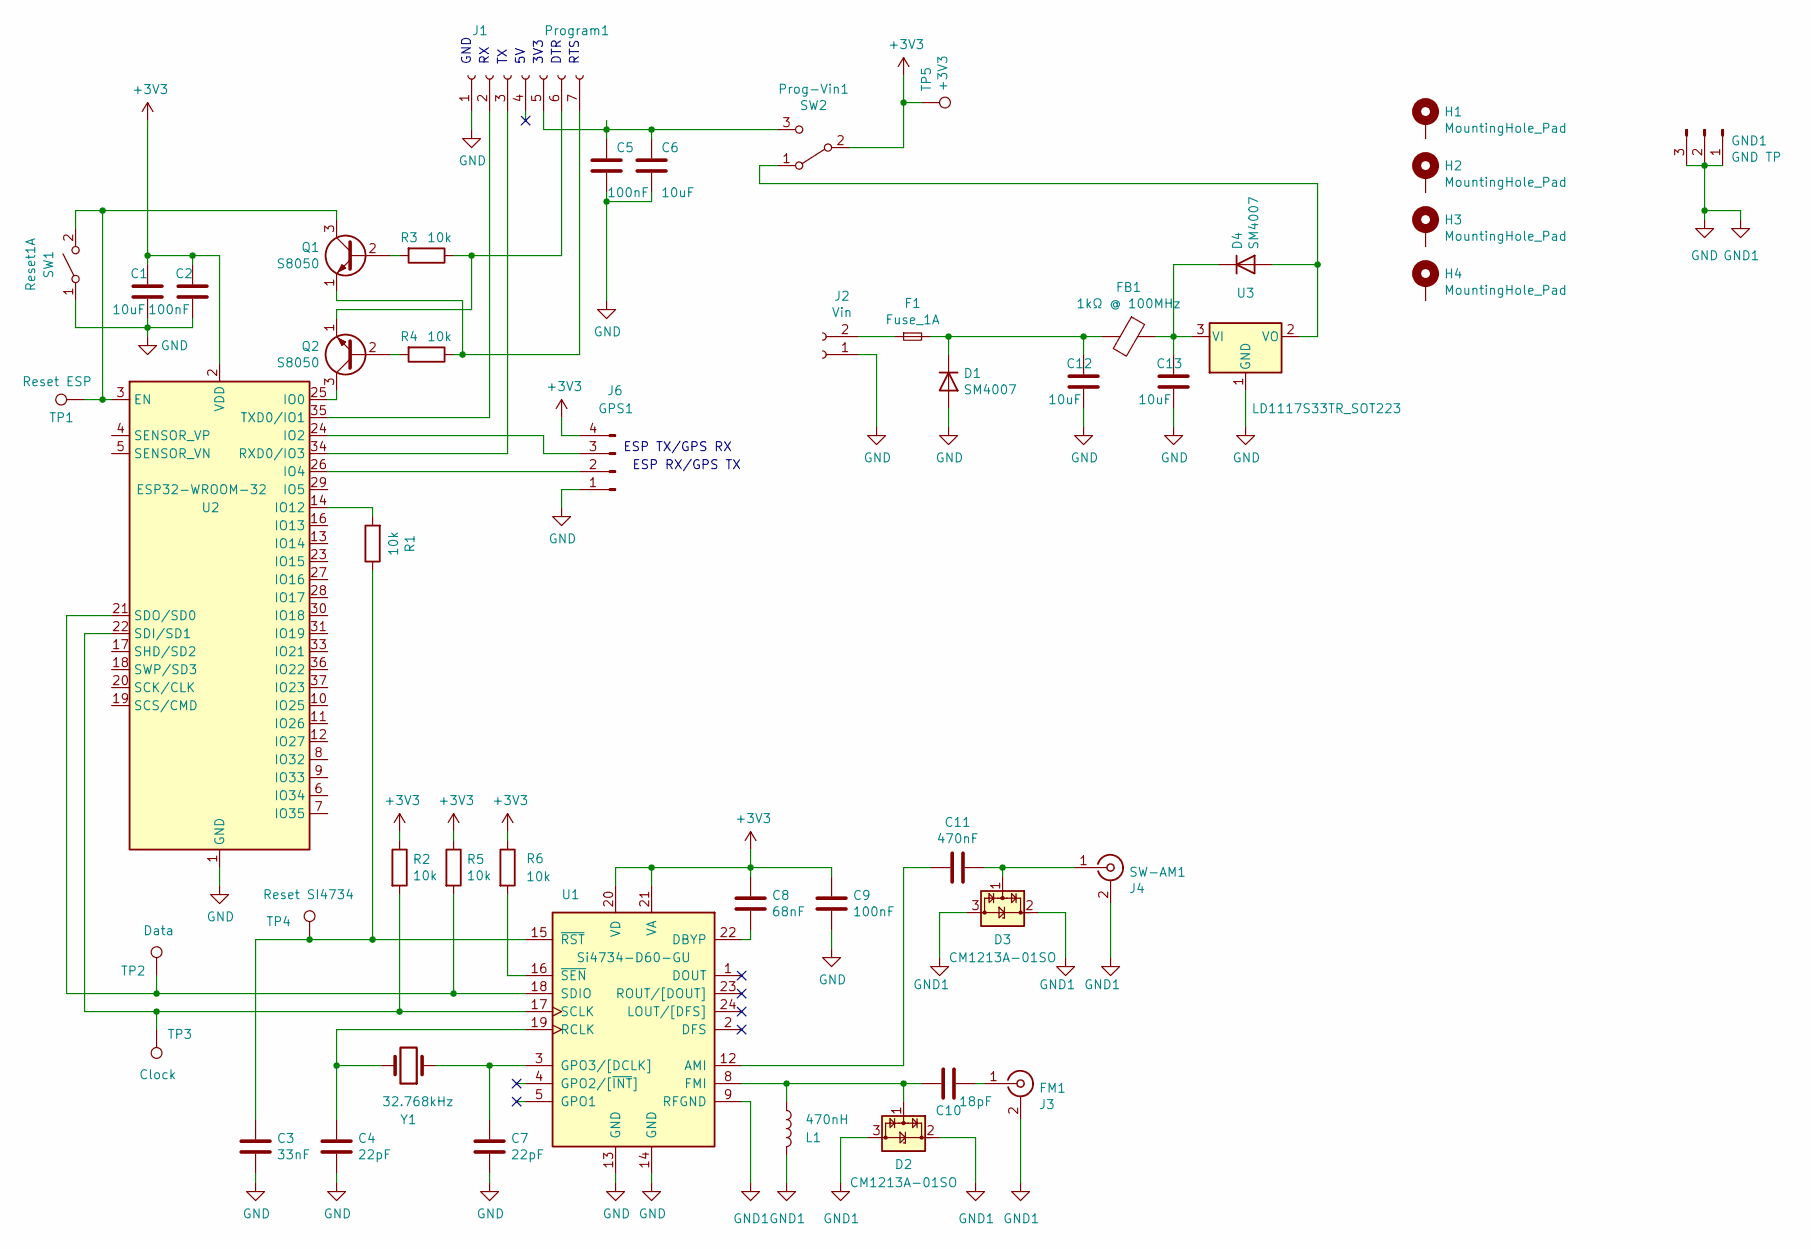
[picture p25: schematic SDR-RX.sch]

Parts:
C1, C6, C12, C13: 10uF; C_1206_3216Metric_Pad1.33x1.80mm_HandSolder; LCSC Part # C13585
C2, C5, C9: 100nF; C_0603_1608Metric_Pad1.08x0.95mm_HandSolder; LCSC Part # C14663
C3: 33nF; C_0603_1608Metric_Pad1.08x0.95mm_HandSolder; LCSC Part # C21117
C4, C7: 22pF; C_0603_1608Metric_Pad1.08x0.95mm_HandSolder; LCSC Part # C1653
C8: 68nF; C_0603_1608Metric_Pad1.08x0.95mm_HandSolder; LCSC Part # C31658
C10: 18pF; C_0603_1608Metric_Pad1.08x0.95mm_HandSolder; LCSC Part # C1647
C11: 470nF; C_0603_1608Metric_Pad1.08x0.95mm_HandSolder; LCSC Part # C1623
D1, D4: SM4007; D_1206_3216Metric_Pad1.42x1.75mm_HandSolder; LCSC Part # C64898
D2, D3: CM1213A-01SO; SOT-23
F1: Fuse_1A; Fuse_1206_3216Metric_Pad1.42x1.75mm_HandSolder; LCSC Part # C182308
FB1: 1kΩ @ 100MHz; L_1210_3225Metric_Pad1.42x2.65mm_HandSolder; LCSC Part # C124093
FM1: J3; SMA_Samtec_SMA-J-P-X-ST-EM1_EdgeMount
GND1: GND TP; PinHeader_1x03_P2.54mm_Vertical
GPS1: J6; JST_SH_BM04B-SRSS-TB_1x04-1MP_P1.00mm_Vertical-GPS; LCSC Part # C239522
H1, H2, H3, H4: MountingHole_Pad; MountingHole_2.7mm_Pad_Via
J2: Vin; JST_XH_B2B-XH-A_1x02_P2.50mm_Vertical
L1: 470nH; L_0603_1608Metric_Pad1.05x0.95mm_HandSolder; LCSC Part # C1034
Prog-Vin1: SW2; SW_SPDT_CK-JS102011SAQN; LCSC Part # C160876
Program1: J1; JST_XH_S7B-XH-A-1_1x07_P2.50mm_Horizontal
Q1, Q2: S8050; SOT-23_Handsoldering; LCSC Part # C2146
R1, R2, R3, R4, R5, R6: 10k; R_0603_1608Metric_Pad0.98x0.95mm_HandSolder; LCSC Part # C25804
Reset1: SW1; SW_SPST_B3SL-1002P; LCSC Part # C318887
SW-AM1: J4; SMB_Jack_Vertical
TP1: Reset ESP; TestPoint_Pad_D1.5mm
TP2: Data; TestPoint_Pad_D1.5mm
TP3: Clock; TestPoint_Pad_D1.5mm
TP4: Reset SI4734; TestPoint_Pad_D1.5mm
TP5: +3V3; TestPoint_Pad_D1.5mm
U1: Si4734-D60-GU; SSOP-24_3.9x8.7mm_P0.635mm
U2: ESP32-WROOM-32; LCSC Part # C82899
U3: LD1117S33TR_SOT223; SOT-223-3_TabPin2; LCSC Part # C23984
Y1: 32.768kHz; Crystal_SMD_3215-2Pin_3.2x1.5mm; LCSC Part # C32346

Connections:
+3V3: C1.1, C2.1, C8.1, C9.1, GPS1.4, Prog-Vin1.2 (B), R2.1, R5.1, R6.1, TP5.1, U1.20 (VD), U1.21 (VA), U2.2 (VDD)
GND: C1.2, C2.2, C3.2, C4.1, C5.2, C6.2, C7.2, C9.2, C12.2, C13.2, D1.2 (A), D2.2 (VP), D2.3 (VN), D3.2 (VP), D3.3 (VN), FM1.2 (Ext), GND1.1, GND1.2, GND1.3, GPS1.1, GPS1.MP, J2.1, L1.2, Program1.1, Reset1.1 (A), SW-AM1.2 (Ext), U1.9 (RFGND), U1.13 (GND), U1.14 (GND), U2.1 (GND), U2.15 (GND), U2.38 (GND), U2.39 (GND), U3.1 (GND)
unnamed: C3.1, R1.1, TP4.1, U1.15 (~RST)
unnamed: C4.2, U1.19 (RCLK), Y1.2
unnamed: C5.1, C6.1, Prog-Vin1.3 (C), Program1.5
unnamed: C7.1, U1.3 (GPO3/[DCLK]), Y1.1
unnamed: C8.2, U1.22 (DBYP)
unnamed: C10.1, FM1.1 (In)
unnamed: C10.2, D2.1 (CH1), L1.1, U1.8 (FMI)
unnamed: C11.1, D3.1 (CH1), SW-AM1.1 (In)
unnamed: C11.2, U1.12 (AMI)
unnamed: C12.1, D1.1 (K), F1.2, FB1.2
unnamed: C13.1, D4.1 (K), FB1.1, U3.3 (VI)
unnamed: D4.2 (A), Prog-Vin1.1 (A), U3.2 (VO)
unnamed: F1.1, J2.2
unnamed: GPS1.2, U2.26 (IO4)
unnamed: GPS1.3, U2.24 (IO2)
unnamed: Program1.2, U2.35 (TXD0/IO1)
unnamed: Program1.3, U2.34 (RXD0/IO3)
unnamed: Program1.6, Q2.1 (E), R3.1
unnamed: Program1.7, Q1.1 (E), R4.1
unnamed: Q1.2 (B), R3.2
unnamed: Q1.3 (C), Reset1.2 (B), TP1.1, U2.3 (EN)
unnamed: Q2.2 (B), R4.2
unnamed: Q2.3 (C), U2.25 (IO0)
unnamed: R1.2, U2.14 (IO12)
unnamed: R2.2, TP3.1, U1.17 (SCLK), U2.22 (SDI/SD1)
unnamed: R5.2, TP2.1, U1.18 (SDIO), U2.21 (SDO/SD0)
unnamed: R6.2, U1.16 (~SEN)

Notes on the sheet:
3V3
DTR
RTS
GND
ESP RX/GPS TX
ESP TX/GPS RX

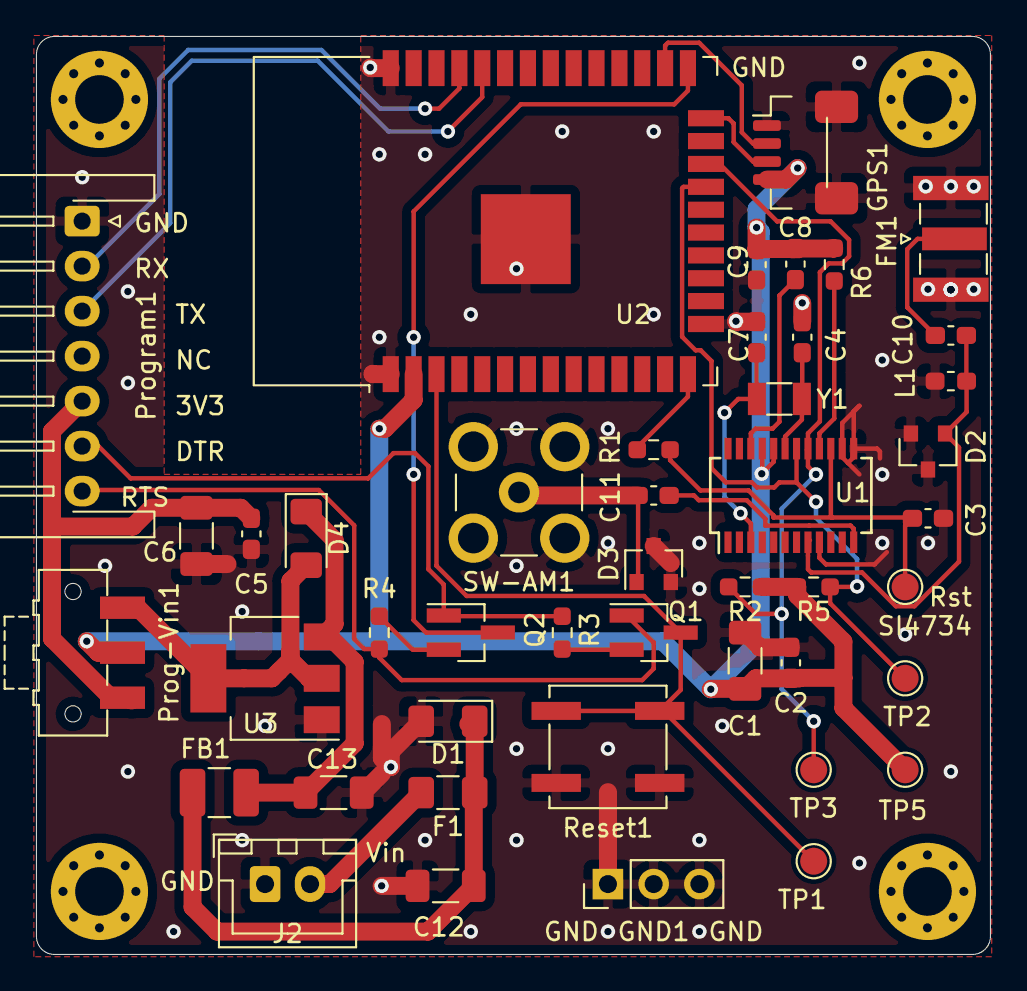
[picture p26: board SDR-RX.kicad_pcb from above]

Board: 2 copper layers, 53.0 x 51.0 mm, 49 parts (0 on the bottom side), 29 nets.

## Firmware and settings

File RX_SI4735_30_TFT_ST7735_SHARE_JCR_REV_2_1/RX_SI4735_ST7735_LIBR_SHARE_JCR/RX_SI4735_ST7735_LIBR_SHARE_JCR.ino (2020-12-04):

/*******************************************************************************************************************************************************
  SI4735/30 AM/FM STEREO - LW/MW/SW/CB RADIO RECEIVER WITH ST7735 COLOR TFT (LIB TFT_ST7735 BODMER) ARDUINO NANO/UNO/PRO MINI - WRITE BY JCR FEB/2020
  RECEPTION RANGE: AM 150kHz TO 30MHz - FM 64 TO 108MHz
  VERSION TO SHARE - JUN/2020
  REV.2.1 - NOV/2020
********************************************************************************************************************************************************
  ELECTRIC CONNECTIONS (ALSO SEE THE SCHEMATICS):
  ST7735 DISPLAY PIN CONNECTION TO ARDUINO NANO/UNO/PRO MINI:
  LED (BACKLIGHT) - 5V(VIA 100R RESISTOR SERIES); SCK - D13; SDA - D11; AO - D9; RESET - D8; CS - D10; GND - GND; VCC - 5V
  ROTARY ENCODER TO ARDUINO: D2; GND; D3
  PUSH BUTTONS:
  BAND SELECT - A0; TUNING STEPS (1k / 5k / 10k) - A1; AM IF FILTER SEL - A2; COLOR THEME - A3 (NOTE: THE OTHER SIDE OF P.B. IS CONNECTED TO GND)
  SI4735/30: SDA - A4 (VIA 1k RESISTOR SERIES); SCL - A5 (VIA 1k RESISTOR SERIES); RESET - D7 (VIA 10k RESISTOR SERIES); VCC - 3.3V; GND - GND
*********************************************************************************************************************************************************
  ATTENTION!
  -MUST INSTALL AND USE THE LIBRARIES LOCATED IN "INSTALL THESE LIBRARIES" FOLDER
  -PLEASE BELOW CHOOSE THE CORRECT I2C ADDRESS FOR YOUR SI4730/35 (0x11 OR 0x63), BEFORE TO START. MODULE PL102BA-S V2.11 USE 0x63
  -FOLLOW THE WIRING AS INDICATED ON SCHEMATICS
  -WORKS WITH IC SI4730-D60 AND SI4731/32/34/35 OR RADIO MODULE PL102BA-S V2.11
  -FOR ICs SI4730/31/34/35 - D60  A 10k PULLUP RESISTOR MUST BE USED IN EACH I2C LINES. FOR PL102BA-S MODULE PULLUPS NOT REQUIRED
*********************************************************************************************************************************************************/

#include <SPI.h>
#include "Wire.h"
#include <TFT_ST7735.h> //BODMER graphics and font library for ST7735 driver chip
#include <Si4735.h>     //MICHAEL KENNEDY SI4735 I2C library modified by JCR
#include <Rotary.h>     //BUXTON Rotary encoder library

TFT_ST7735 tft = TFT_ST7735();  //Invoke library, pins defined in User_Setup.h
Rotary r = Rotary(2, 3);
Si4735 radio;

const byte band = A0;     //Band select and Switch encoder Tune
const byte frstep = A1;   //Tuning Step
const byte filtsel = A2;  //IF filter select
const byte modesel = A3;  //Change diaplay color theme

byte SI7435_ADDRESS = 0x63; //I2C ADDRESS OF SI4735: 0x11 (SEN PIN TO GND) or 0x63 (SEN PIN TO 3v3)

const int bl[22] = {"160 ", "120 ", "90m ", "80m ", "75m ", "60m ", "49m ", "40m ", "41m ", "31m ", "30m ",
                    "25m ", "22m ", "20m ", "19m ", "17m ", "16m ", "15m ", "13m ", "12m ", "11m ", "10m "
                   };
unsigned int freq;
unsigned int fstep;
unsigned int freqold;
int sm, sm_old, mx, mod;
int stp = 2;
int mode = 2;
byte encoder = 1;
byte count = 6;
byte filter = 0x03;
byte fil = 4;
byte fr_h;
byte fr_l;
byte ssb_m = 0x00; //0x00 AM;
byte mw_sw = 0x00; //0x00 MW ; 0x01 SW
byte am_fm = 0x40; //0x40 AM ; 0x20 FM
int period = 100;  //millis period timer for refresh RSQ
unsigned long time_now = 0;  //millis init timer for refresh RSQ
int period_sm = 1000;  //millis period timer for S-meter val peak hold
unsigned long time_now_sm = 0;  //millis init timer S-meter val peak hold

uint16_t ca = 0x001F;  //Blue - tela de fundo
uint16_t cb = 0xFFFF;  //White - textos unidades (ORIG 0x07FF Cyan)
uint16_t cc = 0xFFFF;  //White - linhas
uint16_t cd = 0x3FE0;  //Green - barra SM
uint16_t ce = 0xF81F;  //Magenta - barra MD
uint16_t cf = 0x0000;  //Black - barra inv SM/MD
uint16_t cg = 0xFFFF;  //White - display e kHz
uint16_t ch = 0x07FF;  //Cyan - barra RIT

void setup() {
  tft.init();
  tft.setRotation(3);
  SPI.begin();
  Wire.begin();
  start_msg();
  tft.fillScreen(ca);

  pinMode(band, INPUT_PULLUP);
  pinMode(frstep, INPUT_PULLUP);
  pinMode(filtsel, INPUT_PULLUP);
  pinMode(modesel, INPUT_PULLUP);

  radio.begin(0, SI7435_ADDRESS);
  power_up_norm();
  delay(400);
  am_command();
  count = 6;      //Define initial band at startup
  bandpresets();
  layout();
  setstep();
  frequency();
  smeter();
  band_ind();
  filterAM();

  PCICR |= (1 << PCIE2);
  PCMSK2 |= (1 << PCINT18) | (1 << PCINT19);
  sei();
}

void loop() {
  if (freqold != freq) {
    freqold = freq;
    tune_freq();
    frequency();
  }

  if ((digitalRead(band)) == LOW) {
    inc_preset();
    while (digitalRead(band) == LOW);
  }

  if ((digitalRead(frstep)) == LOW) {
    if (am_fm != 0x20) inc_step();
    if (am_fm == 0x20) setstepFM();
    while (digitalRead(frstep) == LOW);
  }

  if ((digitalRead(filtsel)) == LOW) {
    if (am_fm != 0x20) filterAM();
    if (am_fm == 0x20) filterFM();
    while (digitalRead(filtsel) == LOW);
  }

  if (digitalRead(modesel) == LOW) {
    delay(500);
    ca = 0x0000;  //Black
    cb = 0xFFFF;  //White
    cc = 0xFFFF;  //White
    cd = 0xF81F;  //Magenta   //0x001F;  //Blue
    ce = 0xF81F;  //Magenta
    cg = 0x3FE0;  //Green
    ch = 0x07FF;  //Cyan
    tft.fillScreen(ca);
    //tft.setTextSize(1);
    tft.setTextColor(cb, ca);
    //tft.setCursor(20, 20);
    layout();
    bandpresets();
    frequency(); 
    if (am_fm != 0x20) {fil = 4; filterAM();}
    if (am_fm == 0x20) {fil = 0; filterFM();}
  }

  if (millis() > time_now + period) {
    time_now = millis();
    rsq();
    smeter();
    modgraf();
    if (am_fm != 0x20) band_ind();
    if (am_fm == 0x20) pilot();
  }

  if (sm > mx) mx = sm;
  if (millis() - time_now_sm >= period_sm) {
    time_now_sm = millis();
    mx = sm;
  }
}

ISR(PCINT2_vect) {
  char result = r.process();
  if (result == DIR_CW)
    set_frequency(1);
  else if (result == DIR_CCW)
    set_frequency(-1);
}

void set_frequency(short dir) {
  if (encoder == 1) {     //AM band limits
    if (dir == 1) freq = freq + fstep;
    if (freq >= 30000) freq = 30000;
    if (dir == -1) freq = freq - fstep;
    if (freq <= 150) freq = 150;
  }
  if (encoder == 2) {     //FM band limits
    if (dir == 1) freq = freq + fstep;
    if (freq >= 10810) freq = 10810;
    if (dir == -1) freq = freq - fstep;
    if (freq <= 6410) freq = 6410;
  }
}

void inc_preset() {
  count++;
  if (count > 15)
    count = 1;
  bandpresets();
  delay(50);
}

void bandpresets() {
  tft.setTextSize(1);
  tft.setTextColor(cb, ca);
  switch (count)  {
    case 1:
      encoder = 1;
      radio.begin(0, SI7435_ADDRESS);
      power_down();
      power_up_norm();
      delay(200);
      ssb_m = 0x00;
      freq = 198;
      am_fm = 0x40;
      tune_freq();
      am_command();
      filter = 0x03;
      stp = 1;
      setstep();
      tft.drawString("LW1       ", 30, 57, 2);
      tft.drawString("2k ", 135, 74, 2);
      break;
    case 2:
      freq = 620;
      stp = 3;
      setstep();
      tft.drawString("MW1", 30, 57, 2);
      break;
    case 3:
      freq = 1130;
      stp = 3;
      setstep();
      tft.drawString("MW2", 30, 57, 2);
      break;
    case 4:
      freq = 3700;
      stp = 1;
      setstep();
      break;
    case 5:
      freq = 5000;
      stp = 2;
      setstep();
      break;
    case 6:
      freq = 6180;
      stp = 2;
      setstep();
      break;
    case 7:
      freq = 7295;
      stp = 1;
      setstep();
      break;
    case 8:
      freq = 10000;
      stp = 2;
      setstep();
      break;
    case 9:
      freq = 11940;
      stp = 2;
      setstep();
      break;
    case 10:
      freq = 13790;
      stp = 2;
      setstep();
      break;
    case 11:
      freq = 15400;
      stp = 2;
      setstep();
      break;
    case 12:
      freq = 17780;
      stp = 2;
      setstep();
      break;
    case 13:
      freq = 21525;
      stp = 2;
      setstep();
      break;
    case 14:
      freq = 27015;
      stp = 1;
      setstep();
      break;
    case 15:
      encoder = 2;
      power_down();
      power_up_FM();
      delay(200);
      am_fm = 0x20;
      ssb_m = 0x00;
      freq = 10050;
      fstep = 10;
      tune();
      radio.setMode(FM);
      fil = 0; filterFM();
      stp = 0; setstepFM();
      break;
  }
  if (am_fm == 0x20) {
    tft.setTextColor(cg, ca); tft.drawString("MHz", 132, 57, 2); tft.setTextColor(cb, ca); tft.drawString("FM ", 3, 57, 2);
  }
  else {
    tft.setTextColor(cg, ca); tft.drawString("kHz ", 132, 57, 2); tft.setTextColor(cb, ca); tft.drawString("AM ", 3, 57, 2);
  }
}

void filterAM() {
  tft.setTextSize(1);
  tft.setTextColor(cb, ca);
  switch (fil) {
    case 0:
      fil = 1;
      filter = 0x00; tft.drawString("6k ", 135, 74, 2);
      break;
    case 1:
      fil = 2;
      filter = 0x01; tft.drawString("4k ", 135, 74, 2);
      break;
    case 2:
      fil = 3;
      filter = 0x02; tft.drawString("3k ", 135, 74, 2);
      break;
    case 3:
      fil = 4;
      filter = 0x06; tft.drawString("2k5", 135, 74, 2);
      break;
    case 4:
      fil = 5;
      filter = 0x03; tft.drawString("2k ", 135, 74, 2);
      break;
    case 5:
      fil = 6;
      filter = 0x05; tft.drawString("1k8", 135, 74, 2);
      break;
    case 6:
      fil = 0;
      filter = 0x04; tft.drawString("1k ", 135, 74, 2);
      break;
  }
  property_filter_AM();
}

void filterFM() {
  tft.setTextSize(1);
  tft.setTextColor(cb, ca);
  switch (fil) {
    case 0:
      fil = 1;
      filter = 0x00; tft.drawString("Aut", 135, 74, 2);
      break;
    case 1:
      fil = 2;
      filter = 0x01; tft.drawString("110", 135, 74, 2);
      break;
    case 2:
      fil = 3;
      filter = 0x02; tft.drawString("84k", 135, 74, 2);
      break;
    case 3:
      fil = 4;
      filter = 0x03; tft.drawString("60k", 135, 74, 2);
      break;
    case 4:
      fil = 0;
      filter = 0x04; tft.drawString("40k", 135, 74, 2);
      break;
  }
  fm_command();
}

void inc_step() {
  stp++;
  if (stp > 3)
    stp = 1;
  setstep();
  delay(50);
}

void setstep() {
  tft.setTextSize(1);
  tft.setTextColor(cb, ca);
  switch (stp) {
    case 1:
      fstep = 1;    // 1kHz
      tft.drawString("1k ", 100, 57, 2);
      break;
    case 2:
      fstep = 5;    // 5kHz
      tft.drawString("5k ", 100, 57, 2);
      break;
    case 3:
      fstep = 10;  // 10kHz
      tft.drawString("10k", 100, 57, 2);
      break;
  }
}

void setstepFM() {
  tft.setTextSize(1);
  tft.setTextColor(cb, ca);
  switch (stp) {
    case 0:
      stp = 1;
      fstep = 10;    // 100kHz
      tft.drawString(" x1", 100, 57, 2);
      break;
    case 1:
      stp = 0;
      fstep = 20;    // 200kHz
      tft.drawString(" x2", 100, 57, 2);
      break;
  }
}

void frequency() {    //Format of frequency numbers
  tft.setTextColor(cg, ca);
  if (freq >= 10000) tft.drawNumber(freq, 0, 1, 7); if (freq < 10000 && freq >= 1000) tft.drawNumber(freq, 32, 1, 7);
  if (freq < 1000 && freq >= 100) tft.drawNumber(freq, 64, 1, 7); if (freq < 100 && freq >= 10) tft.drawNumber(freq, 96, 1, 7);
  if (freq < 10) tft.drawNumber(freq, 128, 1, 7); if (freq < 10000) tft.fillRect (2, 1, 28, 48, ca);
  if (freq < 1000) tft.fillRect (34, 1, 28, 48, ca);

  if (am_fm == 0x40 && freq >= 1000) tft.fillCircle(63, 51, 2, cg); else  tft.fillCircle(63, 51, 2, ca);
  if (am_fm == 0x20) tft.fillCircle(95, 51, 2, cg);  else tft.fillCircle(95, 51, 2, ca);
}

void smeter() {  //BARGRAPH SIGNAL METER
  if (sm > 90) sm = 90;

  tft.fillRect(31, 111, sm, 14, cd); // BAR DIRECT
  tft.fillRect(31 + sm, 111, 90 - sm, 14, ST7735_BLACK); // BAR INVERSE

  tft.setTextSize(1);
  tft.setTextColor(cb, ca);
  if (mx < 1) tft.drawString("S0 ", 136, 110, 2);
  if ((mx >= 1) && (mx < 10)) tft.drawString("S1 ", 136, 110, 2);
  if ((mx >= 10) && (mx < 25)) tft.drawString("S3 ", 136, 110, 2);
  if ((mx >= 25) && (mx < 35)) tft.drawString("S5 ", 136, 110, 2);
  if ((mx >= 35) && (mx < 55)) tft.drawString("S7 ", 136, 110, 2);
  if ((mx >= 55) && (mx < 65)) tft.drawString("S9 ", 136, 110, 2);
  if ((mx >= 65) && (mx < 75)) tft.drawString("+20", 136, 110, 2);
  if ((mx >= 75) && (mx < 80)) tft.drawString("+40", 136, 110, 2);
  if (mx >= 80) tft.drawString("+60", 136, 110, 2);
}

void modgraf() {  //BARGRAPH SIGNAL TO NOISE
  int mod_g = map(mod, 0, 65, 65, 0);
  tft.fillRect(26, 77, mod_g, 10, ch); // BAR DIRECT
  tft.fillRect(26 + mod_g, 77, 65 - mod_g, 10, ST7735_BLACK); // BAR INVERSE
}

void layout() {
  tft.setTextColor(TFT_WHITE, TFT_BLUE);
  tft.drawFastHLine(0, 56, 160, cc);  //125
  tft.drawFastVLine(125, 56, 20, cc);
  tft.drawFastHLine(0, 73, 160, cc);
  tft.drawFastHLine(0, 90, 160, cc);
  tft.drawFastHLine(0, 107, 160, cc);
  tft.drawFastVLine(125, 107, 20, cc);

  tft.setTextSize(1);
  tft.setTextColor(cb, ca);
  tft.drawString("JCR", 3, 91, 2);
  tft.drawString("DSP All B. Receiver", 30, 91, 2);
  tft.drawString("MD", 3, 74, 2);
  tft.drawString("BWF", 105, 74, 2);
  tft.drawString("S|dB", 3, 110, 2);
}

void start_msg() {
  tft.fillScreen(TFT_BLACK);
  tft.setTextSize(1);
  tft.setTextColor(TFT_WHITE, TFT_BLACK);
  tft.drawString("JCR Radio - 2020", 3, 10, 2);
  tft.drawString("DSP ALL BAND RECEIVER", 3, 40, 2);
  tft.drawString("REVISION 2.1", 3, 70, 2);
  delay(2000);
}

void band_ind() {
  tft.setTextSize(1); tft.setTextColor(cb, ca);
  if (freq >= 1800 && freq <= 2000) tft.drawString(bl[0], 30, 57, 2); if (freq >= 2300 && freq <= 2495) tft.drawString(bl[1], 30, 57, 2);
  if (freq >= 3200 && freq <= 3400) tft.drawString(bl[2], 30, 57, 2); if (freq >= 3500 && freq <= 3800) tft.drawString(bl[3], 30, 57, 2);
  if (freq >= 3900 && freq <= 4000) tft.drawString(bl[4], 30, 57, 2); if (freq >= 4750 && freq <= 5500) tft.drawString(bl[5], 30, 57, 2);
  if (freq >= 5700 && freq <= 6200) tft.drawString(bl[6], 30, 57, 2); if (freq >= 7000 && freq <= 7299) tft.drawString(bl[7], 30, 57, 2);
  if (freq >= 7300 && freq <= 7600) tft.drawString(bl[8], 30, 57, 2); if (freq >= 9400 && freq <= 10000) tft.drawString(bl[9], 30, 57, 2);
  if (freq >= 10100 && freq <= 10150) tft.drawString(bl[10], 30, 57, 2); if (freq >= 11600 && freq <= 12100) tft.drawString(bl[11], 30, 57, 2);
  if (freq >= 13570 && freq <= 13870) tft.drawString(bl[12], 30, 57, 2); if (freq >= 14000 && freq <= 14350) tft.drawString(bl[13], 30, 57, 2);
  if (freq >= 15100 && freq <= 15830) tft.drawString(bl[14], 30, 57, 2); if (freq >= 18068 && freq <= 18168) tft.drawString(bl[15], 30, 57, 2);
  if (freq >= 17480 && freq <= 17900) tft.drawString(bl[16], 30, 57, 2); if (freq >= 21000 && freq <= 21450) tft.drawString(bl[17], 30, 57, 2);
  if (freq >= 21451 && freq <= 21850) tft.drawString(bl[18], 30, 57, 2); if (freq >= 24890 && freq <= 24990) tft.drawString(bl[19], 30, 57, 2);
  if (freq >= 25670 && freq <= 27999) tft.drawString(bl[20], 30, 57, 2); if (freq >= 28000 && freq <= 29700) tft.drawString(bl[21], 30, 57, 2);
  if (count == 4 && freq < 1800) tft.drawString("MW2", 30, 57, 2);
}
//----------------------------------------------------------------------------------------------------------------
void tune_freq() {
  fr_h = (freq) >> 8;      //Divide um numero Decimal em dois bytes Hexadecimal, Hi byte e Lo byte
  fr_l = (freq) & 0x00FF;

  if ((freq) < 1800) {     //Switch on/off MW tuning cap - 0x00 - MW ; 0x01 - SW
    mw_sw = 0x00;
  }
  else (mw_sw = 0x01);

  tune();
}

void rsq() {
  RSQMetrics rsq;
  radio.getRSQ(&rsq);
  sm = (rsq.RSSI);
  mod = (rsq.SNR);
}

void pilot() {
  RSQMetrics rsq;
  radio.getRSQ(&rsq);
  tft.setTextSize(1);
  tft.setTextColor(cb, ca);
  if (am_fm == 0x20) {
    if (rsq.stereo == 1)
      tft.drawString("> Stereo <", 30, 57, 2);
    if (rsq.stereo == 0)
      tft.drawString("<  Mono  >", 30, 57, 2);
  }
}

void am_command() {
  radio.setProperty(PROP_AM_SOFT_MUTE_MAX_ATTENUATION, 1); // 0 (OFF) - 63
  radio.setProperty(PROP_AM_AUTOMATIC_VOLUME_CONTROL_MAX_GAIN, 0x32C8); // 0x1000 - 0x7800
  radio.setProperty(PROP_AM_AGC_ATTACK_RATE, 4); // 4–248
  radio.setProperty(PROP_AM_AGC_RELEASE_RATE, 4); // 4–248
}

void fm_command() {
  radio.setProperty(PROP_FM_DEEMPHASIS, 0x0001); // 02 = 75 μs;  01 = 50 μs
  radio.setProperty(PROP_FM_CHANNEL_FILTER, filter); // 0 = automat; 1 = 110kHz; 4 = 40kHz
  radio.setProperty(PROP_FM_SOFT_MUTE_MAX_ATTENUATION, 0); // 0 = disable; 31 = max
  radio.setProperty(PROP_FM_BLEND_STEREO_THRESHOLD, 0); // 0 = stereo; 127 = mono
  radio.setProperty(PROP_FM_BLEND_MONO_THRESHOLD, 0); // 0 = stereo; 127 = mono
}
//----------------------------------------------------------------------------------------------------------------
void power_down() {
  Wire.beginTransmission(SI7435_ADDRESS);
  Wire.write(0x11);
  Wire.endTransmission();
  delay(1);
}

void power_up_norm() {
  Wire.beginTransmission(SI7435_ADDRESS);
  Wire.write(0x01);
  Wire.write(0x11);  //11 - NORM ; 31 - PATCH
  Wire.write(0x05);
  Wire.endTransmission();
  delay(1);
}

void power_up_FM() {
  Wire.beginTransmission(SI7435_ADDRESS);
  Wire.write(0x01);
  Wire.write(0x10);  //10 - NORM ; 30 - PATCH
  Wire.write(0x05);
  Wire.endTransmission();
  delay(1);
}

void tune() {
  Wire.beginTransmission(SI7435_ADDRESS);
  Wire.write(am_fm); //0x40 AM ; 0x20 FM
  Wire.write(ssb_m);
  Wire.write(fr_h);  //Hi byte Tune
  Wire.write(fr_l);  //Lo byte Tune
  Wire.write(0x00);
  Wire.write(mw_sw); //0x00 MW ; 0x01 SW
  Wire.endTransmission();
  delay(1);
}

void property_filter_AM() {
  Wire.beginTransmission(SI7435_ADDRESS);
  Wire.write(0x12);
  Wire.write(0x00);
  Wire.write(0x31);
  Wire.write(0x02);
  Wire.write(0x00);     //0x01 = Low cut filter 100Hz ON - 0x00 = OFF
  Wire.write(filter);   //0x00 = 6kHz; 1 = 4kHz; 2 = 3kHz; 3 = 2kHz; 4 = 1kHz; 5 = 1.8kHz; 6 = 2.5kHz;
  Wire.endTransmission();
  delay(1);
}

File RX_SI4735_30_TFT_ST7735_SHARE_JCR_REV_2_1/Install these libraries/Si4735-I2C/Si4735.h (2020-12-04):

/* Arduino Si4735 Library.
 * Original by Ryan Owens for SparkFun Electronics on 2011-5-17.
 * Altered by Wagner Sartori Junior <wsartori@gmail.com> on 2011-09-13.
 * Altered by Jon Carrier <jjcarrier@gmail.com> on 2011-11-11.
 * Cleaned up and improved by Michael J. Kennedy.
 *
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
 * See README file for additional documentation.
 * See the example sketches to learn how to use the library in your code.
 */

#ifndef Si4735_h
#define Si4735_h

//Use to activate low level debugging messages on software serial port
//#define DEBUG 1

#if DEBUG
#include "SoftwareSerial.h"  //SoftwareSerial Library
extern SoftwareSerial debugSerial;
#define DEBUG_TX A0  //Tx PIN
#define DEBUG_RX A1  //Rx PIN - not currently used
#define debug(method, ...) debugSerial.method(__VA_ARGS__)
#else
#define debug(method, ...)
#endif

#if ARDUINO >= 100
  #include <Arduino.h>
#else
  #include <WProgram.h>
#endif

#include <pins_arduino.h>  //Defines SPI pins: SCK, MOSI, MISO, SS

#ifdef __AVR__
   #include <avr/pgmspace.h>
#else
   // Create dummy versions of macros and functions found in <avr/pgmspace.h>
   #define PROGMEM
   #define pgm_read_byte(ptr) (*(ptr))
   #define pgm_read_word(ptr) (*(ptr))
   #define strcpy_P(d, s) strcpy((d), (s))
   #define memcpy_P(d, s, l) memcpy((d), (s), (l))
#endif

/******************************************************************************
* Compile time options for Si4735 library.                                    *
* Change these as required when using the SparkFun Si4735 Breakout Board.     *
* Default values are for SparkFun Si4735 Arduino Shield.                      *
******************************************************************************/

// If Si47xx_SPI macro is defined, use SPI bus to talk to radio.  Otherwise, use I2C bus.
// Remove this macro if you want to use I2C when using SparkFun's breakout board.
// Warning: The SparkFun Arduino shield does NOT support I2C without major modification
// of the circuit board!  If you want to use I2C, use the SparkFun breakout board.
// Warning: The I2C code requires Arduino software 1.0 or greater.
//#define Si47xx_SPI

// Radio I/O pins.  These pin assignments are based on the SparkFun shield.
// Change these if you want when using SparkFun's breakout board.
enum {
   RADIO_SPI_SS_PIN=10,  //SS pin on "original" Arduinos
   RADIO_RESET_PIN =7,   //JCR ORIG =9; W/ TFT ST7735 =7
   RADIO_POWER_PIN =0,   //JCR ORIG =8; W/ TFT ST7735 =6 -->ASSIGN TO 0 TO DISABLE POWER_PIN<--
   //Warning: On the Leonardo, the I2C port's SDA and SCL pins are on pins 2 and 3.
   //Therefore, if you want to use I2C on the Leonardo, RADIO_INT_PIN must be something
   //other than pins 2 and 3.
   //Note: RADIO_INT_PIN must agree with RADIO_EXT_INT below
   #if defined(__AVR_ATmega32U4__) && !defined(Si47xx_SPI)
   RADIO_INT_PIN   =7,  //Leonardo Arduinos with I2C
   #else
   RADIO_INT_PIN   =2,  //All other combinations //JCR ORIG =2 -->ASSIGN TO 0 TO DISABLE INT_PIN<--
   #endif
};

// External interrupt number for AVR based Arduinos.
// Change this if you want when using SparkFun's breakout board.
// For "original" Arduinos this must be from 0 to 1.
// For "Mega" Arduinos this must be from 0 to 5.  (6 and 7 are not connected.)
// For "Leonardo" Arduinos this must be from 0 to 3 or a 6.
// Not used with ARM based Arduinos such as the Due.
enum {
   //Note: RADIO_EXT_INT must agree with RADIO_INT_PIN above
   #if defined(__AVR_ATmega1280__) || defined(__AVR_ATmega2560__)
   RADIO_EXT_INT=4  //Mega Arduinos
   #elif defined(__AVR_ATmega32U4__) && defined(Si47xx_SPI)
   RADIO_EXT_INT=1  //Leonardo Arduinos with SPI
   #elif defined(__AVR_ATmega32U4__) && !defined(Si47xx_SPI)
   RADIO_EXT_INT=6  //Leonardo Arduinos with I2C
   #elif defined(__AVR__)
   RADIO_EXT_INT=0  //Original Arduinos
   #endif
};

/********************************
* Si4735 library default values *
********************************/

// In SPI mode, the second argmunet to begin() gives the clock divider to pass to
// SPI.setClockDivider().  If the second argument is not given to begin(),
// RADIO_SPI_CLOCK_DIV is used instead.  You may change the value of RADIO_SPI_CLOCK_DIV
// if you want.
// Note: Max speed of Si4735 clock input is 2.5 MHz.  All current 5V Arduinos run
// at a 16MHz clock speed.  For 16MHz, use divide by 8 or slower.  The Due runs at
// 84 MHz.  For the Due, use divide by 34 or slower.
// Note: Most users will be running a 5V Arduino with an added level shifter for MISO.
// Some low-to-high volt level shifters can only handle slow speeds.  We choose a slow
// conservative default that is about the same speed as I2C.  If your level shifter
// can handle more, or you don't need a level shifter, you may change the SPI speed.
#ifdef __AVR__
   #if F_CPU <= 8000000L
    #define RADIO_SPI_CLOCK_DIV  SPI_CLOCK_DIV32  //CPU = 8 MHz
   #else
    #define RADIO_SPI_CLOCK_DIV  SPI_CLOCK_DIV64  //CPU = 16 MHz
   #endif
#else
 /* ARM based Due */
 // Note: The Due runs at 3.3V and therefore does not require level shifting.  However,
 // a relatively long wire between the Due and the shield or breakout board will be
 // required and long wires are prone to picking up noise.  Therefore, we choose a slow,
 // conservative bus speed.
 #define RADIO_SPI_CLOCK_DIV  255  //CPU = 84 MHz
#endif

// I2C address of radio chip.  Pass this as the second argument to begin() in I2C mode.
// The radio can be configured to use one of two addresses depending on the SEN/SS input:
//    SEN   Address
//    -------------
//    Low   0x11 (Hexadecimal)
//    High  99   (Decimal)
enum {
   RADIO_I2C_ADDRESS_LOW =0x11,
   RADIO_I2C_ADDRESS_HIGH=99U,
   // If no address is passed to begin(), RADIO_I2C_ADDRESS is used.  Address defaults
   // to SEN == HIGH for Si4707 breakout board compatibility.  Change if you want.
   RADIO_I2C_ADDRESS     =RADIO_I2C_ADDRESS_HIGH
};

/***********************************
* Define Si4735 library class info *
***********************************/

// Bit masks for status byte and interrupts.
// Returned by currentInterrupts(), getInterrupts(), and getStatus().
enum {
   CTS_MASK= 0b10000000,  //Clear To Send
   ERR_MASK= 0b01000000,  //Error occurred
   RSQ_MASK= 0b00001000,  //Received Signal Quality measurement has triggered
   RDS_MASK= 0b00000100,  //RDS data received (FM mode only)
   SAME_MASK=0b00000100,  //SAME (WB) data received (Si4707 only)
   ASQ_MASK= 0b00000010,  //Audio Signal Quality (AUX and WB modes only)
   STC_MASK= 0b00000001   //Seek/Tune Complete
};
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

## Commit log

2020-12-02 Create README.md
    Release Planung am 02.12.2020 erstellt.
    Im Moment arbeiten wir für den Release 1.1 im Main und wir werden am Schluss den Release schliessen, wenn die Arbeiten für Release 1.2 beginnen.
2020-12-02 Update README.md
    Noch zwei Typos gefunden und korrigiert.
2020-12-02 Add files via upload
    Diese vier Dateien sind von Martin mit dem Stand vom 01.12.2020. Es gibt in der Zwischenzeit betreits schon neuere Arbeitsdokumente, und auch dieser Update wird so dann noch ausgetestet.
2020-12-02 Add files via upload
    Dies ist die Spezifikation vom Hersteller Silicon Labs über die leicht neuere SDR Chipreihe mit zwei unterschiedlichen Bauformen. Dabei ist darauf zu achten, dass wir erstens jeweils die Funktion SW 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
2020-12-02 Add files via upload
    Der Hersteller Silicon Labs gibt Unterlagen und Spezifikationen für die Antenne bekannt, welche berücksichtigt werden müssen.
2020-12-02 Add files via upload
    Die ist ein Schema, welches das Projekt von Xhackster verwendet. In diesem Fall wird der Chipset SI4630-D60 in der quadratischen Form verwendet, welcher aber bereits SW kann. Diesen Chip haben wir fü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
2020-12-02 Add files via upload
    Dies ist der Original Code aus dem Xhackster Projekt, welches mit dem SI4730-D60 Chip (mit SW) arbeitet. Wir haben diesen Code mit den entsprechenden Libraries ausprobiert, aber am 03.12.2020 noch ni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
2020-12-03 Update README.md
    Mit dem Release 1.2a "Empfangssignalstärke verknüpft mit den GPS-Daten am Datensammlungspunkt " werden wir überprüfen können, wie der Empfang an einer Live-Antenne im Feld aufgenommen werden können.
2020-12-04 Originalcode von CesarSound (hackster.io)
    Dieser Commit enthält den von CesarSound auf hackster.io publizierten Originalcode zur Ansteuerung des si4730/35 Chips inkl. TFT Display. Sein Schema sowie die notwendigen Arduino-Library Abhängigkei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
2020-12-04 Source Code und Schema von CesarSound aus Wurzelverzeichnis gelöscht
    Diese DAten sind neu im RX_SI4735_30_TFT_ST7735_SHARE_JCR_REV_2_1 Unterverzeichnis zu finden.
2020-12-06 Add files via upload
    Martin hat die vier Dateien zweimal hochgeladen. Ich habe noch nicht herausgefunden wo die ersten vier hingeschickt wurden. Nun sollten diese vier im Ordner Docs sein. Hoffentlich.
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2020-12-21 erste Schema Version für das SDR-RX-PCB
    [SDR-RX.kicad_pcb, SDR-RX.sch]
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2021-01-10 Antennenteil bis SMA Stecker im Schema hinzugefügt
    [SDR-RX.kicad_pcb, SDR-RX.sch]
2021-01-14 Added pullups/down to GPO1, GPO2 of RF and EN of ESP
    [SDR-RX.sch]
2021-01-31 Added Peripheral Schematics for ESP32-WROOM-32-D 3V3 regulator still missing
    [SDR-RX.sch]
2021-02-21 Added power supply path
    [SDR-RX.sch]
2021-03-24 Changes at ESP Reset, Data/Clock wired, Antenna changes
    [SDR-RX.sch]
2021-03-26 Project & PCB file added
    [SDR-RX.kicad_pcb, SDR-RX.sch]
2021-03-26 changed J2 footprint
    [SDR-RX.kicad_pcb, SDR-RX.sch]
2021-03-26 added SW2
    [SDR-RX.kicad_pcb, SDR-RX.sch]
2021-03-26 rearanged parts
    [SDR-RX.kicad_pcb]
2021-03-27 put parts closer on PCB
    [SDR-RX.kicad_pcb, SDR-RX.sch]
2021-03-27 rearraanged RF parts
    [SDR-RX.kicad_pcb]
2021-04-09 PCB layout for plastic enclosure
    [SDR-RX.kicad_pcb, SDR-RX.sch]
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2021-04-27 changed footprint GPS header
    [SDR-RX.kicad_pcb, SDR-RX.sch]
2021-05-03 round corners
    [SDR-RX.kicad_pcb]
2021-05-05 routed without GND
    [SDR-RX.kicad_pcb]
2021-05-05 closed misssing copper
    [SDR-RX.kicad_pcb]
2021-05-06 PCB routed
    [SDR-RX.kicad_pcb]
2021-05-08 sticked back and front GND zones with vias
    [SDR-RX.kicad_pcb]
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2021-05-22 removed obsolete GND vias
    [SDR-RX.kicad_pcb]
2021-05-25 Added BOM and schematics.pdf
    [SDR-RX.csv, SDR-RX.kicad_pcb, SDR-RX.sch]
2021-05-26 Minimize overlap of traces with ESP "keep out" zone for antenna
    [SDR-RX.kicad_pcb]
2021-05-26 Optimizing position of various silk screen elements
    [SDR-RX.kicad_pcb]
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2021-05-26 Adding HB9UF logo to PCB (to be positioned)
    [SDR-RX.kicad_pcb]
2021-06-01 Added silk-screen text and logo
    [SDR-RX.kicad_pcb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]
2021-06-01 V1 submission files generated, some troubles with rotation of CPL detected
    [SDR-RX-B_Cu.gbl, SDR-RX-B_Mask.gbs, SDR-RX-B_Paste.gbp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]
2021-06-02 some local files deleted to regain last SDR-RX.kicad_pcb merged monday with frv branch
    [SDR-RX-B_Cu.gbl, SDR-RX-B_Mask.gbs, SDR-RX-B_Paste.gbp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]
2021-06-02 added teyt as Title and Copyright
    [SDR-RX.kicad_pcb]
2021-06-02 minor changes on silkscreen Program connector and removed strange GND symbol
    [SDR-RX.kicad_pcb]
2021-06-02 created production files, unfortunatelly there is a missrotation on parts
    [SDR-RX-PCB-BOM-V1.csv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]
2021-06-02 added drillfiles
    [SDR-RX.kicad_pcb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]
2021-06-02 fixed reversed comment/designator for switches and connectors to be pick and placed. TODO: need to be changed as well in schema/pcb files
    [SDR-RX-top-pos-V1.csv]
2021-06-03 changed footprint D1 & D4 due to assembly objection
    [SDR-RX.kicad_pcb, SDR-RX.sch]
2021-06-03 moved Prog-Vin1 switch closer to pcb edge, changed anotation GND1 of GND TP
    [SDR-RX.sch]
2021-06-03 changed Designator J5 to Program1 to avoid BPM/CPL missmatch on SMT assembly
    [SDR-RX.kicad_pcb, SDR-RX.sch]
2021-06-03 reversed remaining value/designator of all connectors
    [SDR-RX.kicad_pcb, SDR-RX.sch]
2021-06-03 adapted footprint of GPS1/J6 to real footprint of SMT assembly, created hb9gvd.pretty directory
    [SDR-RX.kicad_pcb, SDR-RX.sch]
2021-06-03 created production files
    [SDR-RX-PCB-BOM-V1.csv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]
2021-06-03 added gerber and hb9gvd.pretty
    [jlcpcb-smt-selected-parts-bom.xls]
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

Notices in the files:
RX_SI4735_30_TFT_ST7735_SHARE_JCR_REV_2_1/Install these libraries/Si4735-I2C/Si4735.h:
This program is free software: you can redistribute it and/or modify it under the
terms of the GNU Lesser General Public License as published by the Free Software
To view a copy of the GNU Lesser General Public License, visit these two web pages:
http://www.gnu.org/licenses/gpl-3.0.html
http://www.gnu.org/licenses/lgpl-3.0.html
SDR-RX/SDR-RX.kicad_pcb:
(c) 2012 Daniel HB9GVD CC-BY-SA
